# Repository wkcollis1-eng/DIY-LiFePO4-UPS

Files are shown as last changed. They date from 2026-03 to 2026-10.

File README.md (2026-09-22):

<div align="center">

# DIY UPS for Home Assistant Green & Xfinity XB7 Modem

**12V LiFePO4-Based Uninterruptible Power Supply**







</div>

A 12V LiFePO4-based uninterruptible power supply for keeping a Home Assistant Green and Xfinity XB7 cable modem running during grid outages. Built into an IP65 enclosure with Home Assistant monitoring via ESPHome INA260 current sensor.

> **Honest context:** A $85 APC BE600M1 provides comparable backup capability. This build costs roughly the same over 10 years as that option (based on battery replacements and electricity usage). The engineering rationale — longer battery life, faster switchover, direct HA integration, no DC-DC converter voltage regulation — is documented in [design-rationale.md](docs/design-rationale.md). Build this if those tradeoffs matter to you.

---

## ⚠️ Safety Warning

> [!CAUTION]
> **This project involves lithium batteries and AC mains voltage.** Improper handling can cause fire, electric shock, or equipment damage.

- ✅ **Disconnect AC power** before any work inside the enclosure
- ✅ Use appropriate **fusing** on battery connections
- ✅ Never charge LiFePO4 below **0°C (32°F)**
- ✅ Keep a **Class B or ABC fire extinguisher** accessible
- ✅ Review [docs/safety.md](docs/safety.md) before building

**Disclaimer:** Information provided for educational purposes only. Build at your own risk.

---

## Performance Summary

**Validated Runtime:** **~3.6 hours** to hardware LVD (11.8V) under a sustained **14.9W** load.

> **Monitoring upgrade note:** The Shelly Plus Uni has been replaced by an ESPHome XIAO ESP32-C3 + Adafruit INA260 current sensor. All capacity figures below are now coulomb-counted by INA260 rather than inferred from voltage profiles. The May 2026 figures supersede the March 2026 D3 estimates.

### Key Finding

The UPS delivers a reliable **~3.6 hours** of runtime at typical HA Green + XB7 loads. This is **~42%** of the theoretical maximum runtime at full charge (10 Ah / 1.18A = 8.47h).

This result is **not** due to battery degradation, measurement error, or software issues. It is a direct consequence of the **single-rail 13.3V CV architecture**.

### Why the Runtime is Limited

The system uses a single shared rail for both charging and load. To keep the voltage safe for the connected equipment, charging is capped at 13.3V. This holds the battery at approximately **65% SOC**, preventing proper absorption charging at 14.4V. As a result, approximately **3.5 Ah** (~35%) of the battery's rated 10 Ah capacity is never accessible.

| Capacity zone | Ah | Reason |
| :--- | ---: | :--- |
| Float ceiling — never loaded | ~3.5 Ah | 13.3V float ≈ 65% SOC; requires 14.4V charger to recover |
| Rate/LVD penalty | ~1.3 Ah | IR drop at 1.18A strands charge above LVD threshold |
| **Delivered (INA260 measured)** | **4.18 Ah** | Coulomb-counted, May 6 2026 |
| Protected at LVD cutoff | ~0.8 Ah | Intentional; prevents over-discharge |
| Below LVD to rated-empty | ~0.8 Ah | Intentional; cell protection |

### Discharge Characteristics

- Extremely flat voltage plateau from 13.0V down to 12.85V — delivers the bulk of usable energy
- Knee region (12.40–12.85V) shows accelerating decline; ~53 min at production load
- Cliff begins at **~12.40V**: voltage slope accelerates from −30 mV/min to −58 mV/min
- 12.4V warning provides approximately **15–20 minutes** of action time before hardware LVD

### Conclusion

The system performs exactly as designed. The layered protection (voltage warnings → automated shutdown → BP-65 hardware LVD) is robust and all three tiers are now fully live-validated.

**Current validated specification:** ~3.6h runtime at 14.9W average under the existing single-rail topology, based on INA260 coulomb counting (May 6 2026).

A two-stage charging architecture (dedicated 14.4V charger + DC-DC regulator) would be required to approach the full ~7.1–8.5 hour theoretical runtime.

Reports and data can be found in [docs/](docs/).
Last validated: **May 2026 (INA260 coulomb counting)**

---

## Commissioning Results

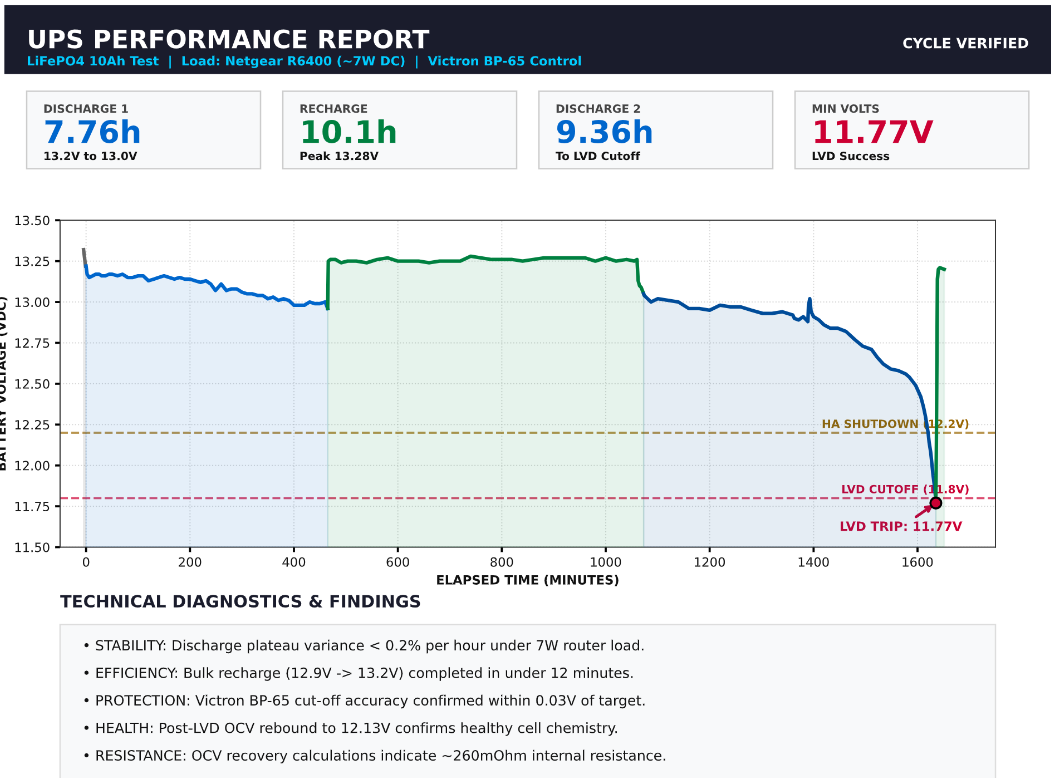
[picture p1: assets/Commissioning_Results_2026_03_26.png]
Commissioning Results


The chart records a full two-cycle discharge test performed March 25–26, 2026 using a
Netgear R6400 router (~7W DC) as a substitute load, with battery voltage logged via the
Shelly Plus Uni at 5-second intervals.

**Discharge 1 (7.76h):** Voltage held the characteristic LiFePO4 flat plateau from 13.2V
to 13.0V over 7.76 hours — a drop of only 0.2V at light load, confirming textbook cell
behavior. **Recharge (10.1h):** AC restored; PSU returned the battery to float within
minutes, peaking at 13.28V and holding stable through a 10-hour recharge window.
**Discharge 2 (9.36h):** A second full discharge ran the battery to LVD cutoff. The
Victron BP-65 tripped at **11.77V** — within 0.03V of the 11.8V design target —
confirming protection circuit accuracy. Post-LVD OCV rebound to 12.13V confirms healthy
cell chemistry with no permanent capacity loss from the deep discharge.

Key findings:
- Discharge plateau variance under 0.2%/hr
- BP-65 cutoff accuracy ±0.03V
- Internal resistance ~260mΩ at low SoC (derived from OCV recovery)
- Bulk recharge from 12.9V to 13.2V completed in under 12 minutes after AC restoration

---

## System Overview

AC grid powers a Mean Well HDR-60-12 PSU set to 13.3V float, which charges a 12V 10Ah LiFePO4 battery through a MOSFET ideal diode. On grid failure, loads switch directly to battery in under 1ms. A Victron BatteryProtect BP-65 disconnects loads at 11.8V to prevent over-discharge. An ESPHome XIAO ESP32-C3 with Adafruit INA260 current sensor and DS18B20 temperature sensor reports battery voltage, current, power, and accumulated Ah/Wh to Home Assistant.

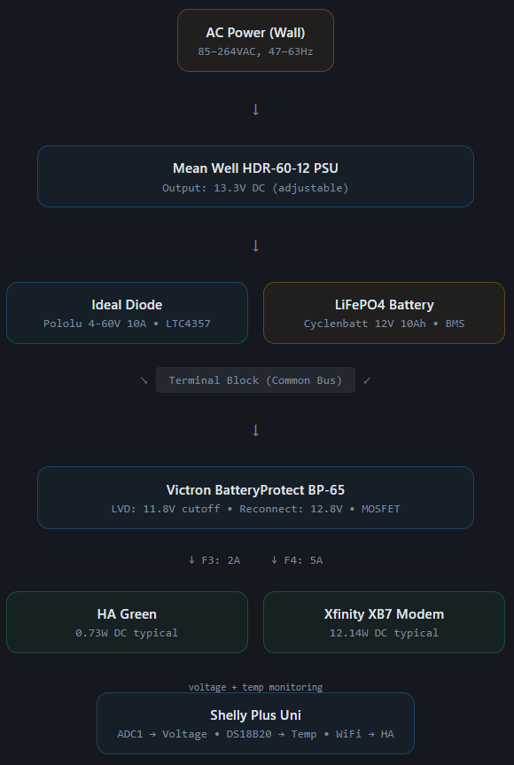
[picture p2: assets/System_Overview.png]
System Architecture


---

## Key Specifications

| Parameter | Value |
| :--- | :--- |
| PSU | Mean Well HDR-60-12, 13.3V float |
| Battery | Cyclenbatt 12V 10Ah LiFePO4 |
| Float voltage | 13.3V (set on PSU trimmer, lacquered) |
| LVD cutoff | 11.8V (Victron BP-65, Setting 7) |
| LVD reconnect | 12.8V (30s delay after threshold met) |
| Device voltage envelope | 11.71–13.11V at terminals (2A worst-case) |
| Switchover time | <1ms (MOSFET ideal diode) |
| Typical load | 16.0W AC wall / 14.9W DC at devices + monitor (INA260 measured) |
| Accessible capacity | 4.18 Ah / 53.3 Wh (INA260 coulomb-counted, May 2026) |
| Runtime at typical load | ~3.6 hours to LVD |
| Battery lifespan | 10–20 years (calendar aging at 13.3V float, 63–75°F) |
| Enclosure | LeMotech IP65 ABS, 9.6″×7.6″×4.5″ |
| Monitoring | ESPHome XIAO ESP32-C3 + INA260 + DS18B20 → Home Assistant |
| Total build cost | ~$224 + ~$25 ESPHome monitor board |

---

## Operating Modes

**Mode 1 — AC Present:** PSU outputs 13.3V through ideal diode; battery held at float equilibrium. Loads draw from PSU, not battery.

**Mode 2 — AC Failure:** PSU output drops to 0V. Ideal diode blocks. Battery feeds loads directly, no interruption.

**Mode 3 — Low Battery (~12.4V):** ESPHome Cliff phase alert. HA notification: Critical Warning.

**Mode 4 — Low Battery (~12.2V):** ESPHome detects threshold. Home Assistant initiates graceful HA Green shutdown; modem continues on battery.

**Mode 5 — LVD Cutoff (11.8V):** Victron BP-65 disconnects loads after 90-second hold-off.

**Mode 6 — AC Restoration:** PSU resumes 13.3V, ideal diode switches source, BP-65 reconnects after 30s hold-off. PSU immediately enters CC mode at 4.5A (~60W) bulk recharge, tapering to CV float over approximately 10–15 minutes.

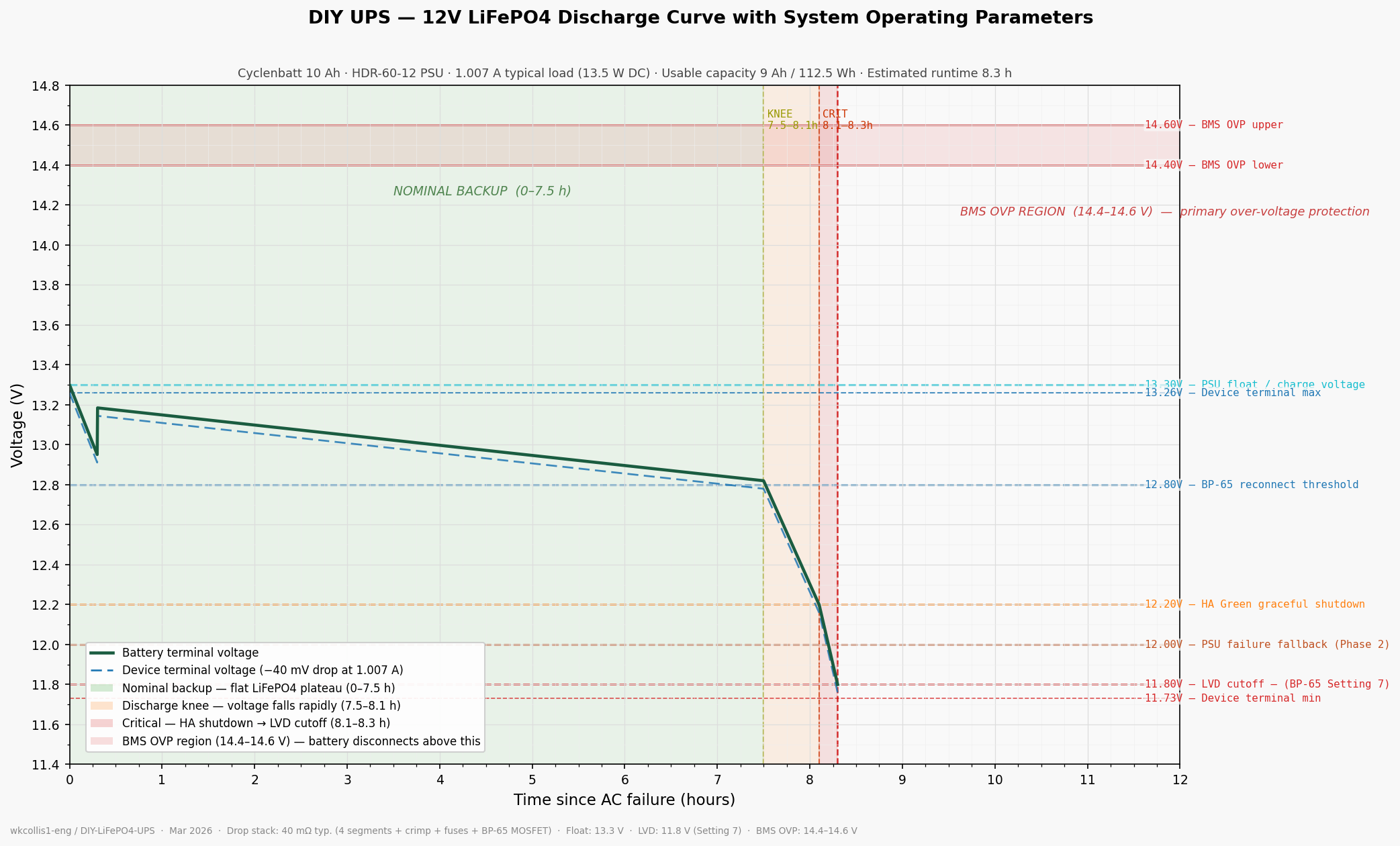
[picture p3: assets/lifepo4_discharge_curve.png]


---

## Automation Validation Status

| Automation | Threshold | Mar 26 | Mar 28 | May 6 | Status |
| :--- | :--- | :--- | :--- | :--- | :--- |
| Early Warning | < 13.0V for 2 min | ✅ | ✅ | ✅ | **PASS** |
| Critical Warning | < 12.4V | ✅ | ✅ | ✅ | **PASS** |
| Graceful Shutdown | < 12.2V for 1 min | ⚠️ Not tested | ⚠️ Not tested | ✅ **Confirmed** | **PASS** |
| BP-65 hardware LVD | ~11.8V | ✅ Direct (11.77V) | ✅ Inferred | ✅ Confirmed (11.675V) | **PASS** |

All four tiers are now fully live-validated. The graceful shutdown automation was confirmed on May 6, 2026 — the final outstanding commissioning item.

---

## Assembly Layout

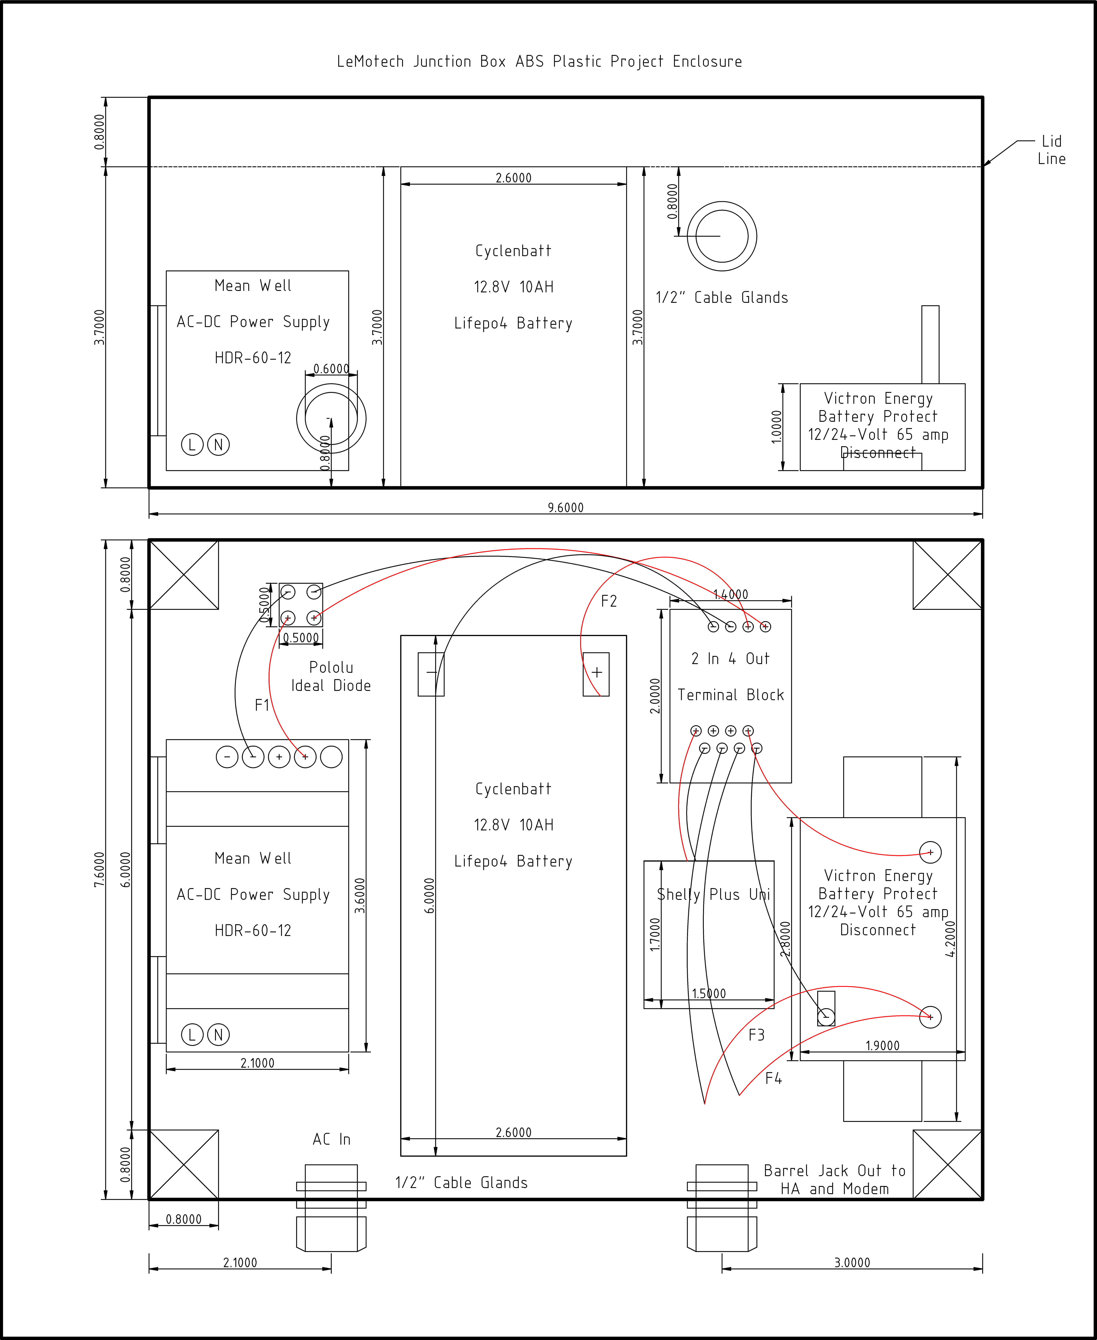
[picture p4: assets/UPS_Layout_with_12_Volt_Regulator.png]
Component Layout


*Elevation (top) and plan (bottom) views of LeMotech junction box. Interior Dimensions in inches.*

## Assembly Pictures

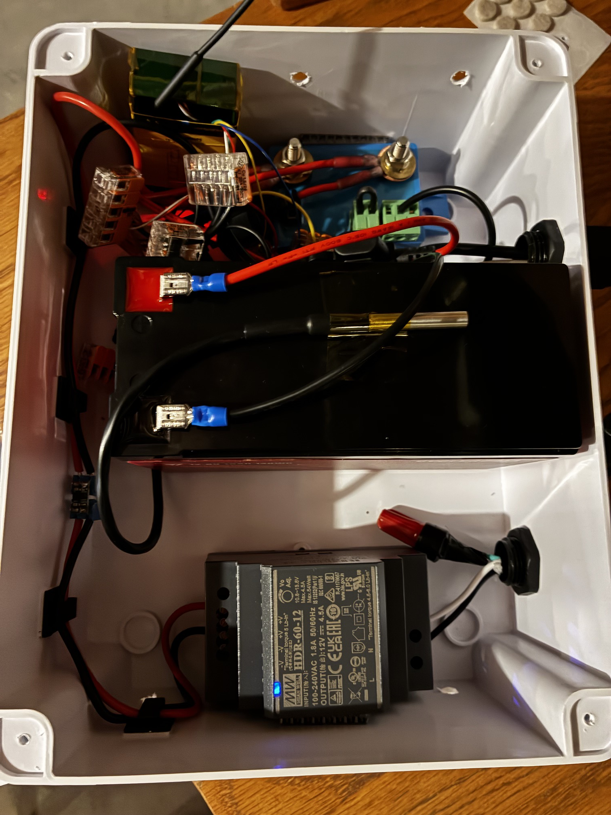
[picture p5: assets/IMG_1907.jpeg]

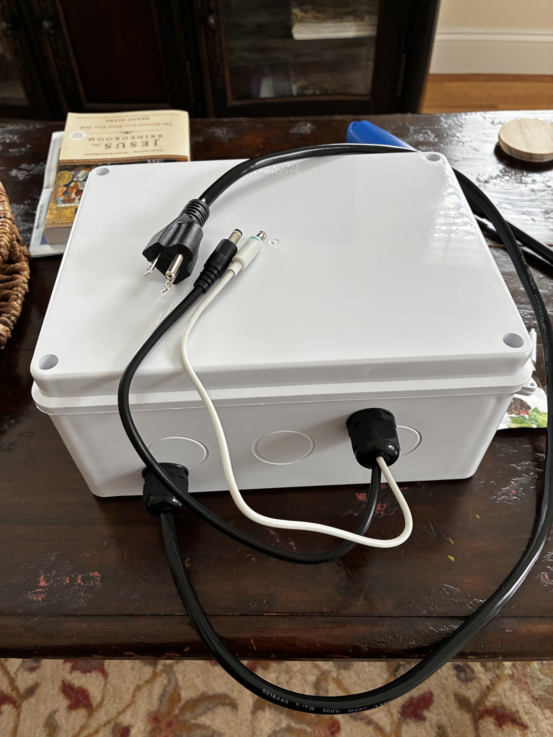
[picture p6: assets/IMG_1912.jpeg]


---

## Documentation

| File | Contents |
| :--- | :--- |
| [docs/bom.md](docs/bom.md) | Full bill of materials with vendor, price, and notes |
| [docs/wiring.md](docs/wiring.md) | From/To wiring tables, fuse locations, component mounting |
| [docs/specifications.md](docs/specifications.md) | Electrical, performance, and protection spec tables |
| [docs/design-rationale.md](docs/design-rationale.md) | Build-vs-buy analysis, float charging strategy |
| [docs/component-selection.md](docs/component-selection.md) | Per-component selection rationale |
| [docs/cost-analysis.md](docs/cost-analysis.md) | Build cost breakdown and 10-year lifecycle comparison |
| [docs/safety.md](docs/safety.md) | AC and battery safety procedures |
| [docs/voltage-drop-analysis.md](docs/voltage-drop-analysis.md) | Wiring resistance and voltage drop calculations |
| [docs/supplemental-analysis.md](docs/supplemental-analysis.md) | Thermal Analysis & Enclosure Heat Budget, Runtime Analysis, Failure Modes & Effects Analysis (FMEA) |
| [docs/design-specification.md](docs/design-specification.md) | Formal requirements, design decisions, and verification matrix |
| [docs/commissioning.md](docs/commissioning.md) | System commissioning process and results |
| [docs/Final_As_Built_Performance_&_Cost_Summary.md](docs/Final_As_Built_Performance_&_Cost_Summary.md) | Final As-Built Performance & Cost Summary |
| [docs/UPS_Validation_Report.md](docs/UPS_Validation_Report.md) | Final Validation Report with Home Assistant configuration |
| [docs/UPS_Report_2026-04-05.md](docs/UPS_Report_2026-04-05.md) | Inaugural commissioning report (Apr 5, 2026) |
| [docs/UPS_Report_2026-05-06.md](docs/UPS_Report_2026-05-06.md) | Outage test report; INA260 first measurement; 12.2V automation confirmed |
| [Top-Off-Charger/top-off-charger-design.md](Top-Off-Charger/top-off-charger-design.md) | Bench top-off / top-balance charger for the removed battery: pre-build design with from/to wiring tables |

## Datasheets

- [Mean Well HDR-60-12 - Datasheet](https://www.meanwell.com/Upload/PDF/HDR-60/HDR-60-SPEC.PDF)
- [Victron Smart BatteryProtect BP-65 — Datasheet](https://www.victronenergy.com/upload/documents/Datasheet-Smart-Battery-Protect-65-A--100-A--220-A-EN.pdf)
- [Victron Smart BatteryProtect — Manual](https://www.victronenergy.com/upload/documents/Smart_BatteryProtect_12V_24V/114439-Smart_BatteryProtect-pdf-en.pdf)
- [Adafruit INA260 — Guide](https://learn.adafruit.com/adafruit-ina260-current-voltage-power-sensor-breakout)
- [TI INA260 — Datasheet](https://www.ti.com/product/INA260)
- [Seeed Studio XIAO ESP32-C3 — Datasheet](https://wiki.seeedstudio.com/XIAO_ESP32C3_Getting_Started/)

---

## Related Projects

- [LiFePO₄ Battery Bank Study](https://github.com/wkcollis1-eng/Lifepo4-Battery-Banks) — 500Ah DIY battery bank with 130+ days of monitoring
- [Home Assistant Config](https://github.com/wkcollis1-eng/home-assistant-config) — HVAC monitoring implementation

---

## Status

- [x] Design complete
- [x] Components specified
- [x] Components ordered / received
- [x] Build complete
- [x] XB7 power measurement complete (14.7W avg, 20.3W peak — 1.066 kWh / 72.4 hr standalone)
- [x] Combined system power measurement complete (16.0W avg, 23.0W peak — confirmed across 5 windows, 525 hours total)
- [x] Home Assistant automation documentation
- [x] ESPHome INA260 monitor build complete and deployed (Apr 2026)
- [x] INA260 coulomb counting validated — first direct capacity measurement: 4.18 Ah / 53.3 Wh (May 2026)
- [x] HA graceful shutdown automation live-validated (May 6, 2026)
- [x] All four automation tiers confirmed — system fully commissioned

---

## Notes

- Device input voltage tolerance (±10%) is inferred from IEC 62368-1 design practice; neither Nabu Casa nor Comcast publish explicit DC input voltage ranges for these products.
- The PSU output trimmer is set to 13.3V and lacquered. Drift analysis shows expected aging drift of 3–5 mV/year — negligible relative to the 500mV headroom before OVP.
- No DC-DC converter is used. The direct battery feed strategy is documented in [design-rationale.md](docs/design-rationale.md).
- The INA260 monitor board (XIAO ESP32-C3 + Adafruit INA260 + DS18B20 on SBB400 breadboard) replaced the Shelly Plus Uni in April 2026, adding coulomb counting, phase detection, and runtime estimation. Monitor draws ~30–40 mA from the 12V battery bus via Pololu D24V7F3 3.3V regulator.
- The Shelly Plus Uni ADC-based capacity estimates (D3, March 2026: 4.85 Ah / 62.5 Wh) are superseded by the INA260 coulomb-counted measurement of 4.18 Ah / 53.3 Wh from May 2026. The D3 figure was computed from voltage profile timing × assumed constant load and should no longer be used as the capacity baseline.

---

## 💝 Support This Project



If this build log or the design rationale saved you time or money on your own UPS project, consider sponsoring continued measurement and documentation work.

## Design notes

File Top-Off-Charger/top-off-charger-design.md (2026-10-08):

# LiFePO4 Top-Off / Top-Balance Charger — Design

**System:** bench top-balance hold charger for the UPS's Cyclenbatt 12V 10Ah. **The pack is removed from the UPS for every session** [owner, 2026-09-21], **charged to full on a Dylannet P20 at 5 A, then held at 14.40 V here** [owner, 2026-09-22; §4.3, §10.1].
**Controller:** the **Top Off Charger PCB** (`Top Off Charger- Oct 2026.kicad_pcb`, §7), one 2-layer board carrying the XIAO ESP32-C3, Adafruit INA228 (#5832), Pololu #2814 switch, Pololu #5382 ideal diode, Pololu D24V7F3 buck and the status LED. It replaces rev 0.5's second build of the bank-monitor board and its Wago-spliced wiring. The bank-monitor build is still cited for the rules that carry over ([wiring summary v1.10][ws], cited below as **ws**).
**Document revision:** 0.8 — **pre-build design draft, 2026-10-08.** The board is laid out (rev 0.7: re-laid smaller, 29.5 × 78 mm, with a Kelvin GND for the INA228; rev 0.8: the power path widened and VIN+ moved to B.Cu), with DRC at 0 errors, 34 warnings (all silk or library) and 0 unconnected. Schematic parity did not run (§7). It is not fabricated, and nothing here is built or tested. Scoped to the UPS pack and moved here from `Lifepo4-Battery-Banks/Top-Off Charger/` (rev 0.2 is commit `680caed` in that repo). Changes are listed in §15.
**Author:** William Collis (draft prepared with Claude Code)

Provenance tags follow the house convention: **[M]** measured, **[S]** spec (document + page), **[D]** derived (formula shown), **[I]** inferred (with its falsifier). The on-hand fuse has no maker's datasheet, so its interrupt rating is **[I]** (O2). Seller listings are cited as **[listing]**: below [S], because R16 needs a maker's document for the identifier on the unit.

[ws]: https://github.com/wkcollis1-eng/Lifepo4-Battery-Banks/blob/main/INA228%20Monitor/battery-bank-monitor-wiring-summary-v1_10.md

---

## 1. The unattended moment

A session is running and the owner is away. Wi-Fi or Home Assistant is down, the ESP32 hangs, the PSU's voltage regulation fails high, or the pack on the lead never went through the P20.

**"Working" at that moment means:**

1. The session ends by itself within its time cap.
2. The pack never sits above its voltage ceiling for longer than one sample period.
3. No fault the battery can feed can burn a conductor.
4. Nothing restarts a charge after a reboot or an AC blip.
5. The PSU never runs in its overload fault mode beyond a short transient (RQ-12).

Every protection layer in §8 exists for one of those five clauses.

---

## 2. Why this exists

The HDR-60-12 floats the pack at 13.3 V, so the cells never reach balancing voltage. On the 09-15 test the pack delivered 2.5331 Ah LVD-to-LVD, against 4.179 Ah on 05-06 [M, one test each; [09-15 README](../data/2026-09-15_full_discharge_survival_test/README.md)]. Its OCV overlay favours a non-uniform pack. Rev 0.4 made this charger the tool for that report's Open Item 16, a coulomb-counted recharge to termination. **Rev 0.5 does not:** the bulk charge moves to the P20 (§4.1 correction record, §4.3), which counts nothing, so Open Item 16 is not served by this build (O10).

**What it cannot do:** balance a pack whose BMS has no balancer. The Cyclenbatt is sealed, with no balance taps [M, owner-confirmed 2026-09-15], and its label gives no balance details [owner, 2026-09-21]. Documentation cannot settle whether it balances. Two observations bear on it:

- **The success measure** is the matched-load LVD-to-LVD capacity test, before and after (UPS Open Item 14a). Nothing else here shows whether the top-off helped.
- **The current tail at 14.40 V** (FW-6) is the first direct look. A passive balancer bleeding a high cell should hold the charge current above zero at constant voltage [I; falsifier: the logged current at 14.40 V decays toward zero with no floor].

The P20's full charge reaches the capacity the 13.3 V float never uses. The hold here adds time at balancing voltage, and nearly all of it is the current tail FW-6 logs, which is the observation above.

**Deferred: the 500 Ah bank hold** (rev 0.2 profile P2). Adding it back needs a second firmware profile, a busbar pigtail fused for the bank's ≥ 3.6 kA prospective fault current [D, rev 0.2 §6.2], the charger's return on the load side of the bank shunt, and the bank report's ledger fix done first. Nothing in this build blocks it, but V_SET must then stay at or below the bank's 14.58 V measured peak.

---

## 3. Requirements

| ID | Requirement | Value | Basis |
|---|---|---|---|
| RQ-1 | Charge current into the pack | **≤ 5.0 A (0.5 C)** | Owner, 2026-09-21, from the Cyclenbatt documentation |
| RQ-2 | The PSU physically cannot exceed RQ-1, under any overload behaviour | ≤ 3.64 A worst case, at any pack voltage FW-3 admits | [D] §4.1 |
| RQ-3 | Charge stops with no network, no HA, and a hung CPU | — | §1 |
| RQ-4 | Nothing restarts after a reboot or an AC loss | — | §1 |
| RQ-5 | Every conductor the battery can feed is fused at the battery end, with an interrupt rating ≥ the battery's prospective fault current | — | §6 |
| RQ-6 | Battery polarity at the F2 tabs is set **by procedure**: colour-matched QDs, checked before each push-on, with AC off | — | §6.3. Rev 0.2 claimed "reversal impossible" through a keyed connector. That held only for a permanent pigtail, and this pack's tabs are remade every session |
| RQ-7 | The pack is never charged on the UPS bus | Removed from the UPS for every session | Owner, 2026-09-21. XB7 validated envelope 11.71–13.11 V [[boost-subsystem-design.md](../UPS-Monitor/boost-subsystem-design.md) R5] |
| RQ-8 | *Withdrawn in rev 0.3* (bank return on the busbar; bank deferred, §2) | — | — |
| RQ-9 | No charging at or below freezing | Charge only above 32 °F. **Met by siting:** the P20 and this charger are used indoors, in conditioned space. No sensor, no firmware check | Owner, 2026-09-21 (Cyclenbatt label) and 2026-09-22 (siting; rev 0.5 dropped the DS18B20) |
| RQ-10 | Charge voltage within the pack's rating | 14.4–14.6 V | Owner, 2026-09-21, Cyclenbatt label |
| RQ-11 | No charging above the pack's upper charge temperature | The label gives none [owner, 2026-09-22]. **Met by siting**, as RQ-9 | Q2 answered |
| RQ-12 | The PSU runs inside its rating: load ≤ 2.0 A, except a transient no longer than t_ol | 2.0 A [S, HDR-30-SPEC p.2, rated current]; t_ol from T11 | Overload is a "fault condition" [S, p.2]; §4.1 correction record. Enforced by FW-4 |

---

## 4. Part selection

### 4.1 PSU — HDR-30-15, not HDR-60-15

The HDR series has no current setpoint. When a pack below V_SET is connected, the battery holds the output near its own voltage, and the PSU runs at its overload limit: **105–160% of rated output power** [S, HDR-30-SPEC and HDR-60-SPEC, both dated 2026-04-03, p.2]. **In rev 0.5 that happens only as a transient** (RQ-12): the P20 does the bulk charge (§4.3), and this PSU holds a full pack.

| | HDR-60-15 | **HDR-30-15** |
|---|---|---|
| Rated | 4 A / 60 W [S, HDR-60-SPEC p.2] | **2 A / 30 W** [S, HDR-30-SPEC p.2] |
| Adj. range | 13.5–18 V [S] | 13.5–18 V [S] |
| OVP | 18.8–22.5 V [S] | 18.8–22.5 V [S] |
| Efficiency (typ.) | 89% [S] | 89% [S] |
| Current in overload, into 13.2 V | **4.77–7.27 A** [D: 63–96 W ÷ 13.2 V] | **2.39–3.64 A** [D: 31.5–48 W ÷ 13.2 V] |
| Meets RQ-1 (≤ 5.0 A)? | **No**: the upper part of the band exceeds it | **Yes, at the band's ceiling** |

The sibling HDR-60-12 on the UPS was measured inside that band. Its total output was 143.8% of nameplate at 11:00:13, decaying to 96.0% by 11:07:58 [D in the 09-15 README; one recharge, with the true peak earlier and unobserved]. So the band is not a paper number. It was also a transient of minutes, which is the only use of the band rev 0.5 keeps (RQ-12).

**Decision: HDR-30-15.** Its datasheet ceiling (3.64 A [D]) is below RQ-1, whatever the overload circuit actually does. The overload row adds "Constant current limiting within 50% ~ 100% rated output voltage" [S, p.2], so the current does not rise as the pack voltage falls, down to 7.5 V [D: 50% × 15 V]. The 13.2 V figure below is therefore not a limit on validity: 3.64 A bounds every pack voltage FW-3 admits (> 10.0 V).

- The pack took ≥ 4.4465 A on the 09-15 outage recharge [M, one firmware peak, a lower bound], so 3.64 A is inside its service history.
- Heat is 3.71 W at rated load [D: 30 W ÷ 0.89 − 30 W].
- 13.2 V is used as a conservative low battery voltage. The current is lower at any higher voltage.

**Output regulation**, the terms that set the voltage-ceiling margin in §9 [S, HDR-30-SPEC p.2, 15 V column]:

| Spec | HDR-30-15 | At V_SET = 14.40 V |
|---|---|---|
| Voltage tolerance (Note 3: includes setup tolerance, line and load regulation) | ±1.0% [S] | ±144 mV [D: 14.40 × 1.0%] |
| Temperature coefficient (0–50 °C) | ±0.03%/°C [S] | ±108 mV over a 25 °C rise [D: 14.40 × 0.03% × 25; the rise is assumed, not measured] |
| Ripple and noise (max, 20 MHz) | 120 mVp-p | +60 mV peak [D: 120 ÷ 2] |
| Overload behaviour | "Hiccup mode when output voltage <50%"; "Constant current limiting within 50% ~ 100% rated output voltage"; both "recover automatically after fault condition is removed" [S] | Hiccup below 7.5 V [D: 50% × 15 V rated]; constant current above it. O3 closed: read by layout-preserving extraction 2026-09-22, the last clause decoded from private-use glyphs |

Terminals: one **+V**, one **−V**, **AC/L**, **AC/N** [S, HDR-30-SPEC p.4]. The pin numbers do not survive text extraction, so work from the labels on the unit's silk. Class II, with no earth terminal [S, p.4].

> **Correction record (R13), 2026-09-22.** Rev 0.3 and 0.4 made this PSU the bulk charger, running "at its overload limit" for the whole bulk phase. The review that preceded rev 0.5 accepted that and recommended dropping the owner's P20, citing the HDR-60-12's recharge as precedent. The datasheet does not support it: the overload row says the PSU "recovers automatically after **fault condition** is removed" [S, HDR-30-SPEC p.2], and the derating curve's load axis ends at 100% [S, p.3]. The HDR-60-12 precedent was a transient of minutes, 143.8% of nameplate decaying to 96.0% within 8 min [D, 09-15 README, n = 1], while a bulk charge from empty would hold this PSU in overload for 0.8–2.0 h [D: 2.53 Ah ÷ 3.2 A to 4.18 Ah ÷ 2.1 A; the pack's measured capacities, one test each, over the 105–160% band of the 2.0 A rating]. Found when the owner asked for proof that the HDR-30-15 could do the whole charge. Rev 0.5 moves the bulk charge to the P20 and adds RQ-12 and the FW-4 overload stop.

### 4.2 Switch — Pololu #2814 (Big MOSFET Slide Switch, MP), not #2815 (HP)

From the comparison table on the Pololu #2814/#2815 product pages [S, read 2026-09-21; footnote 1: "At 12 V with ambient temperature of 22 °C in still air"]:

| | #2814 MP | #2815 HP |
|---|---|---|
| Absolute max / recommended operating voltage | 40 V / 4.5–32 V | 40 V / 4.5–32 V |
| On resistance (max, at 10 V) | 30 mΩ | 8.6 mΩ |
| Continuous current, MOSFETs at 55 °C | 4.0 A | 6.0 A |
| Continuous current, MOSFETs at 150 °C (absolute limit) | 8.0 A | 16 A |
| Price | $5.49 | $8.49 |

**Decision: #2814.**

- At the PSU's 3.64 A worst case [D, §4.1] the #2814 dissipates 0.40 W [D: 3.64² × 0.030 Ω]. That is below the 4.0 A at which Pololu's table puts its MOSFETs at 55 °C in 22 °C still air.
- Its 32 V recommended maximum is above the PSU's 22.5 V OVP ceiling [S, §4.1].
- The ON pin tolerates 30 V independent of VIN, and **"Driving the 'ON' pin low (or leaving it disconnected) will leave the switch off"** [S, #2814 page].
- It saves $3.00 [D: 8.49 − 5.49].

> **Correction record (R13), 2026-09-21.** The review that preceded rev 0.3 read the table's "4.0 A at 55 °C" as an **ambient**-temperature rating and recommended keeping the #2815. The 55 °C is the **MOSFET** temperature, at 22 °C ambient (footnote 1). The owner caught it from the #2814's 8 A spec line, which is the 150 °C absolute-limit figure. Evidence: the #2814 page's comparison table, read 2026-09-21.

### 4.3 Bulk charger — Dylannet P20 (owner's, rev 0.5)

The owner's charger does the bulk charge before every hold session. Everything below comes from the owner's reading of the unit or from the seller's listing; there is no maker's datasheet.

| | Value | Source |
|---|---|---|
| Identity | Dylannet **P20**, maker's part TB-30020A (Huizhou Haitan Technology) | [listing, Amazon B0BM9H759L, read 2026-09-22]. Confirm "P20" on the unit's label (R16) |
| LiFePO4-mode current | 5 / 10 / 20 A selectable; **5 A used** | Owner, 2026-09-22. Meets RQ-1. The listing's own note: "Charge the battery below 10AH with the minimum current" |
| LiFePO4-mode voltage | 14.6 V | [listing]. The top of RQ-10's 14.4–14.6 V |
| End of charge | Enters trickle charging; it **does not turn off** | [listing]. §10.1 disconnects it when it reaches trickle |
| Repair / pulse mode | Lead-acid only; not offered in LiFePO4 mode | Owner, 2026-09-22 |
| Temperature compensation | Automatic winter/summer switching; whether it acts in LiFePO4 mode is not stated | [listing]. Indoor use (RQ-9) |

**Why the P20 and not the HDR-30-15 for bulk:** the P20 is a charger, built to deliver its set current continuously. The HDR-30-15 would deliver bulk current only in its overload fault mode (§4.1 correction record).

**What the P20 does to this design:** the pack arrives having just finished a 14.6 V absorb, so it rests above V_hold, and FW-3 refuses Start until VBUS falls below it (§9). The P20 records nothing, so the approach to the top of charge, where an uneven pack would trip its BMS, happens unlogged. FW-5 still sees a trip during the hold.

---

## 5. Architecture

```text
AC 120 V ─ plug-in COUNTDOWN TIMER (L6, no network) ─ 2-wire cord ─ G1 ─► HDR-30-15 AC/L, AC/N

POWER PATH  (charge current, ≤ 3.64 A)      ── board copper ──────────────────────────────────────────────────────────────────────
HDR +V ─► TB1-2 ═BATT_RAW═► U4 #2814 VIN ~ VOUT ═Batt_SW═► U5 #5382 VIN ~ VOUT ═VIN+═► U2 INA228 VIN+ ═15 mΩ═ VIN− ═VIN−═► TB2-1 ─ G2 ─► S1 ─► 5 A FUSE ─► F2 QD ─► pack +
HDR −V ◄─ TB1-1 ◄══════════════════════════════════ GND pour (both layers) ═══════════════════════════════════════ TB2-2 ─ G2 ──────────────────► F2 QD ─► pack −

BOARD SUPPLY (upstream of the switch)
BATT_RAW ─► F1 1 A slow-blow ═V_Fused═► U3 D24V7F3 ═+3V3═► U1 XIAO 3V3 · U2 INA228 VCC

CONTROL  (on-board traces)
U1 D2 (GPIO4) ═GPIO4_SW═► U4 pin 1 ON   (direct; the #2814's own R4 + R5 = 20 kΩ to GND holds it off)
U1 D1 (GPIO3) ═GPIO3═► R1 1 kΩ ═GPIO3_LED═► LED anode;  LED cathode ─► GND      (status LED, §5.5)
U1 SDA / SCL ═► U2 SDA / SCL

#2814 slide: LOCKED in OFF.  INA228 VBUS jumper: CLOSED.  GPIO4_SW: NO pull-up (the board has no position for one; never add one, §7.2).
```

The order of the power path is deliberate:

- **Switch → ideal diode → shunt.** The switch interrupts forward current. The shunt sees only battery current, not the board's supply.
- **The ideal diode** blocks the battery from back-feeding the PSU (the job it already does in the UPS [[bom.md](../docs/bom.md)]). It does two further jobs here:
  - **It makes L6 end everything.** The board is fed from the PSU side of the switch. Without the diode, AC loss with the switch ON would let the pack back-feed through the switch into the board. The ESP32 would stay up and hold the switch on, and the pack would drain into the PSU output with nothing to stop it. T12 proves this.
  - **It guarantees I ≥ 0 through the shunt.** The VBUS ceiling trip (§9) relies on this.
- **The board is fed upstream of the switch**, from the PSU side (BATT_RAW → F1 → U3). It is alive whenever AC is on, draws nothing from the battery when AC is off, and keeps reading the pack while the switch is open.
- **VBUS is on the battery side.** With the switch open, VIN+ is tied to the battery through the idle shunt, so VBUS reads the pack's open-circuit voltage before every start.
- **The ground is the pour, not a star (rev 0.6).** Rev 0.5 made the [WG] lever nut a ground star, so charge current never flowed in the conductor the INA228 measures VBUS against. On the board, pack − (TB2-2) and HDR −V (TB1-1, rev 0.7) both land on the GND pour. The INA228's GND (U2 pin 2) is not on the pour (the owner's 2026-10-06 17:09 save): it is its own net, GND_SENSE, a 0.5 mm track to a net tie on TB2-2's pad. This is a Kelvin connection (§7.3). The charge return therefore no longer crosses copper shared with the INA228's reference, and **VBUS reads high by ≤ 0.20 mV at 3.64 A** [D, §7.3]. Before the Kelvin connection it read high by 0.376–0.382 mΩ × I, 1.37–1.39 mV at 3.64 A. High is the safe direction for the 14.60 V ceiling (§9). It is zero before every start (I = 0, FW-3), and T10 measures it as part of R_series.

### 5.1 Terminal blocks (rev 0.6: replaces the splice nodes)

The rev 0.5 lever nuts WP, WG and WL are gone: their joints are board copper now. Only four wires land on the board, on two 2-position 3.81 mm screw terminals: **Phoenix Contact BC-381X9-2 GN, item 5442756** (owner, 2026-10-06; it is the board's Value field) [S, Phoenix product page for 5442756, owner-supplied text, 2026-10-06]. Its body (7.62 × 7.3 mm, 1.1 mm hole) matches the footprint, `TerminalBlock_Phoenix_MKDS-1-2-3.81_1x02_P3.81mm_Horizontal` (7.61 × 7.3 mm, 1.1 mm drill) [M, board file]. Directions below assume the board is held **component side up, with the INA228 end at the top** (the TB2 end; KiCad's y = 20 mm edge in rev 0.7).

| Block | Pin | Pad | Silk | Net | Wire landed | Which screw |
|---|---|---|---|---|---|---|
| **TB1** (PSU in) | 1 | round | `GND` | GND | W6 from HDR **−V** | the **upper** screw, nearer the XIAO |
| | 2 | square | `+` | BATT_RAW | W3 from HDR **+V** | the **lower** screw, nearer F1 |
| **TB2** (pack lead) | 1 | square | `+` | VIN− (the shunt's low side) | W16, lead **+** | the **right** screw, nearer the board centre |
| | 2 | round | `GND` | GND | W18, lead **−** | the **left** screw, nearer the left edge |

[M, board file saved 2026-10-06 15:16:19 (rev 0.7 layout), pad nets, shapes and positions. **Rev 0.7 swapped TB1's pins** (owner, 2026-10-06: intentional): BATT_RAW moved from pin 1 to pin 2 and GND from pin 2 to pin 1, so `+` is now the **lower** screw. The square pad stayed with `+`. TB2 is unchanged.]

- **TB1's wires enter from the board's left edge**; **TB2's from the top edge**, so the lead leaves the box that way without a hard turn (owner, rev 0.6 layout; both blocks keep their rev 0.6 rotations in rev 0.7 [M]).
- **Rev 0.8: TB1's labels can be read with U4 seated** (O14). TB1 moved 4.5 mm down, its pads now at y 68.5 and 72.31 [D: rev 0.7's + 4.5]. `GND` is at (16.5, 66.0), above the upper screw, and `+` at (17.0, 74.5), below the lower one, both left of U4's outline at x 20.7 [M, board file 2026-10-08 10:48:22]. The screw order is unchanged: **lower screw `+`**.
- **Rev 0.7: TB1's `+` and `GND` silk sat under the #2814.** `GND` is at (22.5, 66.0) mm and `+` at (21.5, 67.5), both inside U4's outline (x ≥ 20.7 mm), so a seated #2814 hides them [M, board file 2026-10-06]. `GND` also sits midway between the two screws (pads at y 64.0 and 67.81). Read them before U4 goes in, or go by the table: **lower screw `+`** (O14).
- **TB2-1's screw is under the INA228.** TB2's `+` silk (20.0, 29.5) and pin 1 (x 20.6) are inside U2's outline (x ≥ 18.5 mm) [M], and the module sits ~10 mm up (owner) over an 8.5 mm block [S]. **Land and torque W16 and W18 before seating U2**, and unseat U2 (AC off) to re-land them. `GND` (15.5, 30.0) is clear. Rev 0.8 leaves TB2 and its `+` where they were, and moves `GND` to (15.5, 29.5), still clear [M].
- **Landing the wires** [S, Phoenix 5442756 page]: 26–16 AWG (to 1.5 mm²), so 16 AWG at TB2 and 18 AWG at TB1 are in range. Strip 5 mm. Torque 0.22–0.25 Nm, holding the housing while tightening. Ferrules are listed only up to 0.5 mm², so land 16 and 18 AWG bare. Do not tin the strands [I: solder creeps under clamp pressure and the joint loosens; general practice, not on the Phoenix page]. Rated 13.5 A (UL 10 A), above the 3.64 A transient (§6.4).
- **Nothing on the board blocks a reversed TB1.** BATT_RAW has no diode or protection part [M, netlist §7]. The #2814 has its own reverse-voltage protection [S, product name, §14], but F1's branch feeds C4 and U3 directly. Check polarity before first power (§5.4).

### 5.2 From/to — inside the enclosure

| W# | From | To | Wire | Termination / notes |
|---|---|---|---|---|
| W1 | AC cord, **hot** conductor (smooth jacket; narrow blade on a polarized plug) | HDR-30-15 **AC/L** | 2-conductor cord, through cord grip **G1** | HDR screw terminal. The cord's plug goes into the countdown timer |
| W2 | AC cord, **neutral** conductor (ribbed jacket; wide blade) | HDR-30-15 **AC/N** | same cord | HDR screw terminal |
| W3 | HDR-30-15 **+V** | board **TB1-2 (BATT_RAW, `+`)** | 18 AWG red | HDR screw terminal → TB1 **lower** screw (§5.1; rev 0.7 moved it). Feeds the power path and, through F1 (1 A SB), the board supply. PSU-fed only: the ideal diode keeps the pack off it (§5) |
| W4, W5 | *Withdrawn in rev 0.6* | — | — | Board copper: the BATT_RAW track to U4 VIN and to F1 (§7) |
| W6 | HDR-30-15 **−V** | board **TB1-1 (GND)** | 18 AWG black | HDR screw terminal → TB1 **upper** screw. The charge return lands here from the pour (§5, §7.3) |
| W7–W14 | *Withdrawn in rev 0.6* | — | — | Board copper. W7–W9 (grounds) → the GND pour; W10 → the Batt_SW track; W11 → the VIN+ track; W12 → the VIN− track; W13/W14 (the J2 control pair) → the GPIO4_SW track, U1 D2 to U4 ON, and the pour. The #2814 and #5382 grounds are their own module pins on the pour (§7) |
| W15 | *Withdrawn in rev 0.3* | — | — | No external pull-down: the #2814 carries its own (§7.2) |

### 5.3 From/to — leaving the enclosure

| W# | From | To | Wire | Termination / notes |
|---|---|---|---|---|
| W16 | board **TB2-1 (VIN−, `+`)** | Splice **S1** → fuse holder, line-side lead | 16 AWG red, through cord grip **G2** | **Lead +.** S1 is a crimped, heat-shrunk butt splice, not a lever nut: this joint is outside the box, on a lead that is handled every session. **24–30 in** (owner, 2026-10-06; §6.4). R_series is measured at T10 |
| W17 | Fuse holder, battery-side lead (**5 A**) | **F2 female QD** → Cyclenbatt **+** | the holder's own lead | **The fuse sits within a few inches of the + tab** (§6.1). Insulated 6.3 mm female QD |
| W18 | board **TB2-2 (GND)** | **F2 female QD** → Cyclenbatt **−** | 16 AWG black, through **G2**, twisted with W16 | **Lead −**, the charge return. Insulated 6.3 mm female QD |
| W19 | *Withdrawn in rev 0.5* | — | — | DS18B20 dropped: RQ-9 and RQ-11 are met by siting (§3). Enclosure temperature comes from the INA228 die (FW-10) |

Not on the rev 0.6 board: an OLED header (dropped in rev 0.3), a DS18B20 terminal (dropped in rev 0.5), an ALERT test point (L4 withdrawn), or a separate VBUS lead (the jumper replaces it). INA228 header pins 5 (VBUS) and 8 have no net [M, board file].

### 5.4 Build notes

- **First flash by USB with AC off** (cord unplugged from the timer), OTA after that, and never USB with AC on. The board puts U3's 3.3 V output straight onto the XIAO's 3V3 pin (§7), so the bank build's rule against a 3V3 source conflict with the XIAO's USB-fed LDO carries over [[ws] §2.1].
- **Power-up tell:** the status LED is firmware-driven, not a rail indicator. GPIO3 resets as an input with no pull and is not in the power-up glitch table [S, ESP32-C3 datasheet pp.20–21], so the LED is dark from reset until the firmware drives it. If it is **dark for more than ~10 s** after AC on, the board is not running [[ws] §4.4]. Check TB1 polarity first, **then the LED's own polarity** (§5.5): a reversed LED is dark forever and fakes this symptom.
- **Staged first power (rev 0.6).** The modules plug into sockets, and every socket accepts a module turned 180° or shifted along the row. Bring the board up one module at a time, AC off for every insertion:
  1. **Bare board** (U1–U4 out; U5 is soldered): DMM TB1-1 to TB1-2 must **not** read a steady short. C4 and C5 charge from the meter, so the reading climbs.
  2. **U4 (#2814) in:** repeat step 1. Turned 180°, the module's GND pin 2 lands on board pad 11 (BATT_RAW) while its pins 9–10 land on GND pads, so TB1 reads a dead short [D, from the pad map, §7]. On AC, that short would hold the PSU in hiccup.
  3. **U3 (D24V7F3) in, U1 and U2 out:** AC on, read **3.3 V** at the U1 socket's 3V3 pin and at U2 socket pin 1. Turned 180°, U3 puts V_Fused on its own output pin. What that does to the +3V3 net depends on the module's internals, which the board review could not settle: whether C4's body blocks the reversed insertion is inconclusive [I; falsifier: the step-3 reading]. That is why U1 and U2 stay out until this reads 3.3 V.
  4. **U2, then U1**, each with AC off.
- **Control net, XIAO out, U4 in, before the first AC on:** the U1 socket's D2 contact to U4 pin 1 (ON) reads 0 Ω, and D2 to GND reads roughly 10–20 kΩ through the #2814's R4 + R5, with Q3's base junction across R5 depending on the meter. A 0 Ω to GND, or an open to ON, means U4 is mis-seated. On the board, copper replaces the J2 cable, so the pair can no longer be swapped; this check now proves the seating. It still does one of the jobs of the withdrawn Rs (§7.2).
- **Before the first AC on:** DMM continuity from each F2 QD back to its terminal (+ through the fuse to TB2-1, − to TB2-2), with no continuity between them.

### 5.5 Status LED: where it goes, and which leg goes in which hole

**Where (rev 0.8).** With the board component side up and the INA228 end at the top, the LED is on the **left edge**, below the XIAO and above TB1, just left of the #2814's outline. Its two holes are 2.54 mm apart, at (15.96, 61.50) and (18.50, 61.50) mm, against the left edge at x 13.45 [M, board file saved 2026-10-08 10:48:22]. It is still turned as in rev 0.7, so the square pad is the **right** hole. But the LED now sits at the other edge, so the square hole is the one **farther from** the edge; in rev 0.7 it was the nearer. The LED is under no module, and no part's outline stands in front of the XIAO's USB-C socket (O12) [M, courtyards and outlines]. R1 (1 kΩ) lies horizontally under the XIAO.

**Where (rev 0.7, superseded).** The LED was on the **right edge**, level with the XIAO's USB-C socket, which opened straight at it: the socket's axis at y 46.0 mm, the LED's centre at y 47.0, its holes at (37.16, 47.00) and (39.70, 47.00) mm [M, board file saved 2026-10-06 15:16:19]. Rev 0.7 **turned it 180°** from rev 0.6.

```text
            INA228 end of the board is UP, component side facing you

                      silk ring: cut FLAT on this side (on the
                      3 mm footprint the flat shows only as two
   left edge          short ticks, above and below the square pad)
   of the board                    │
       │                           ▼              #2814 (U4)
       │       (●)          [■]   ▌               outline ──►
       │      pad 2        pad 1  ▌
       │      ROUND        SQUARE ▌
       │        │             │
       │     LONG leg      SHORT leg
       │     anode (+)     cathode (−)
       │     to R1, XIAO   to GND
       │     D1 (GPIO3)
```

| LED lead | How to recognise it | Goes in | Pad | Net |
|---|---|---|---|---|
| **Cathode (−)** | the **short** leg; the **flat** on the LED's rim is on this side | the **right** hole, toward the #2814 and away from the board edge, on the flat side of the silk ring | **square** (pad 1) | GND |
| **Anode (+)** | the **long** leg | the **left** hole, nearer the board edge | **round** (pad 2) | GPIO3_LED → R1 → GPIO3 |

**Mnemonic: Square = Short = Flat = minus.** The square pad, the short leg and the flat on the rim all mark the same lead, the cathode. The long leg goes in the round hole.

- **What is measured, and what is convention.** The pad shapes, their nets and the flat in the silk are [M], read from the board file: pad 1 is square and on GND, and pad 2 is round and on R1. "Long leg = anode, flat = cathode" is the industry convention. For this part it is **[I]**: Lite-On's LTL-4231N datasheet could not be retrieved (§14).
- **The check that settles it, before soldering and before trimming the legs** (trimmed legs lose the length cue). Put the DMM on diode test, red probe on the long leg and black on the short. The LED should glow faintly and read about 2 V [I: the listing's 2.1 V forward voltage]. If it reads open, swap the probes. If it glows that way round, this part breaks the convention: trust the meter, and put the lead on the **black** probe in the square hole.
- **A reversed LED** sits reverse-biased at 3.3 V and never lights. Whether that is inside its reverse rating is [I] without the datasheet. The real cost is the indicator: a dark LED reads as "board not running" (§5.4), and FW-11's status patterns are lost. The first boot checks it: once HA or the web page shows the node running, the LED must show the IDLE blink.
- **Current:** about 1.2 mA [D: (3.3 V − 2.1 V) ÷ 1 kΩ; Vf from the listing]. Whether that is bright enough in room light is [I]. The falsifier is the first boot. If it is too dim, R1 is the only part to change.
- **Size: 3 mm.** The Value field names the LTL-4231N, which LCSC lists as a 3 mm (T-1) part [listing, C125082]. The owner changed the footprint from `LED_D5.0mm` to `LED_D3.0mm` in v6 (2026-10-03 22:41:30), and that closed Q6. The pads did not move in that edit: same positions, same nets, 1.8 mm pads, 0.9 mm drill [M, v5/v6 diff]. Rev 0.7 then moved and turned the LED (above); pad 1 is now 1.6 × 1.8 mm, pad 2 1.8 mm round, both 0.9 mm drill, same nets [M, board file 2026-10-06]. The Value text still reads "LED GREEN DIFFUSED T/H LED_D5.0mm - LTL-4231N". It is on F.Fab, which is not fabricated, so nothing printed is wrong (O13).
- **USB-C plug clearance: settled in rev 0.8** by the move to the left edge. The LED is now at the XIAO's other end and below it, so a cable's overmold cannot reach it (O12 closed). Rev 0.7's analysis follows. The XIAO sits about 10 mm up on its sockets (owner, 2026-10-06; rev 0.6 said ~8 mm), and in rev 0.7 its USB-C socket points straight at the LED. The LED is 1.0 mm off the socket's axis (it was 7.0 mm in rev 0.6), and its dome starts about 0.5 mm past the XIAO's outline [D: dome centre x 38.43 − 1.5 mm vs outline x 36.4, board file], so a cable's overmold passes **directly over** it. The board's 3D render puts the LED top at about 5.1–5.3 mm and the socket's underside at about 9.7 mm [M, render of the board file's models]. An overmold up to 8 mm thick, centred on the socket, would clear the LED by roughly 2 mm [I: overmold size and a 3.2 mm socket height assumed, not measured]. Whether it clears is not settled (O12). **Dry-fit before soldering:** seat the XIAO, plug a USB-C cable in, and stand the LED in its holes. If they touch, mount the LED flush, or do the one USB flash (§5.4) with the XIAO out of its socket. Every later flash is OTA.

---

## 6. Fusing and the battery connection

### 6.1 Where the fuse goes

The energy that burns wire comes from the **battery**. The PSU limits itself to ≤ 160% of rated power [S] and hiccups below 50% Vout [S, HDR-30-SPEC p.2; O3].

A short in the external lead (a QD touching the wrong tab, chafed insulation) is fed from the battery and never passes a fuse at the charger end. **So the fuse goes at the battery end of the + conductor, as close to the + tab as the holder allows.** Everything downstream of it is then protected: the lead, the splices, and every node inside the enclosure the battery can reach. A second fuse at the charger end would add nothing for battery-fed faults.

The negative conductor is not fused (standard practice: fuse the ungrounded conductor). The UPS's own F2 fuse stays with the UPS harness when the pack comes out, so the charger lead carries its own.

### 6.2 Rating and interrupt capacity

| | |
|---|---|
| Normal current | ≤ 3.64 A [D, §4.1] |
| Fuse | **5 A mini (ATM/APM) blade in an inline holder** (owner, on hand; from an AKOSN assortment kit, Q3 answered 2026-09-22) |
| Prospective fault current | Bounded by the pack and a 10 A BMS, below 1 kA [I; falsifier: none cheap] |
| Interrupt rating | **Unknown.** The kit's listing states no voltage rating, no interrupt rating and no standard [listing, Amazon B0DNC57LR9, read 2026-09-22], and the kit has no maker's datasheet. **RQ-5 cannot be shown met with it:** fit a branded 5 A mini fuse whose maker publishes a DC interrupt rating (O2). Rev 0.2's ATC-5 figure (1,000 A at 32 VDC) came from a distributor listing |

The fuse protects the **wire**. It does not enforce RQ-1: a 5 A fuse carries 5 A indefinitely. RQ-1 is enforced by the PSU choice (§4.1) and the firmware I_max stop (§9).

### 6.3 No alligator clips, and no keyed connector

**Clips are out.** A slipping clip can bridge terminals upstream of the fuse, and clips allow a reversed connection.

**The keyed connector is out too (rev 0.3).** The pack comes out of the UPS for every session, so its F2 tabs are reconnected every time, to the UPS harness and to this lead alike. A keyed connector on the charger would only move the joint where reversal can happen. It would never remove it.

The lead therefore ends in the fuse holder and insulated F2 female QDs (§5.3), and **RQ-6 is met by procedure** (§10.1), as it already is for the UPS's own battery connection.

What reversal would do: with the switch open, a reversed pack puts about −13 V on VBUS and the #5382 output [I]. Treat the INA228 and #5382 as damaged until proven otherwise. FW-3 refuses to start on a reversed or absent pack, because VBUS then reads ≤ 10.0 V. But the damage happens when the QD goes on, before any firmware runs.

### 6.4 Conductors

- **External lead:** 16 AWG, 4.016 mΩ/ft [S, standard AWG table, 20 °C].
- **PSU to board** (W3, W6): 18 AWG, short runs.
- **On the board (rev 0.7):** the power path is 1.5 mm track on F.Cu: BATT_RAW, Batt_SW, VIN+ and VIN−, each a single route [M, board file 2026-10-06]. IPC-2221's external-conductor formula gives 3.21 A at a 10 °C rise and 4.35 A at 20 °C for 1.5 mm of 1 oz copper [D: I = 0.048 · ΔT^0.44 · A^0.725, with A = 81.4 mil²; 1 oz is assumed, not measured]. 2.0 A is the steady case (RQ-12); 3.64 A is a transient no longer than t_ol. The ground is the pour (§7.3). The owner plans to move VIN+ to B.Cu and shorten it (O15, §7.4).
- **On the board (rev 0.8, the 2026-10-08 10:48 save):** each power net is still a single route, now wide [M, board file]:
  - BATT_RAW: 4.0 mm on F.Cu, from TB1-2 through U4 pins 12 and 11.
  - Batt_SW: 2.9–4.0 mm on F.Cu.
  - VIN+: 2.9–4.0 mm on **B.Cu**, with no vias (O15, done).
  - VIN−: 3.85 mm on F.Cu, necking to 1.7 mm for its last ~0.2 mm into U2 pin 6.

  The same IPC-2221 formula gives these rises at 3.64 A: 4.0 mm 2.6 °C, 2.9 mm 4.5 °C and 1.7 mm 10.8 °C. At 2.0 A they are 0.7, 1.2 and 2.8 °C [D]. The formula assumes a long run, so it overstates the short 1.7 mm neck [I].
- **The F1 branch** (BATT_RAW, from U4 pins 11–12 to F1 pin 1) is 2.0 mm, and V_Fused is 1.5 mm. The branch lies upstream of F1, so F1 does not protect it. The PSU's limit does (≤ 3.64 A [D, §4.1]), and the #5382 keeps the pack off BATT_RAW. At 3.64 A, 2.0 mm rises 8.3 °C [D, as above]. The branch's two legs, to U4 pins 11 and 12, form a small loop in parallel with the main run. That loop barely matters: narrowing the branch from 2.95–3.95 mm to 1.5 mm, on a copy of the 08:04 save, moved BATT_RAW's track resistance from 1.172 to 1.177 mΩ [D, §7.4's 2-D solve].
- **Module contacts.** U2's VIN+ and VIN− are one socket contact each, so the whole charge current crosses two Sullins contacts rated 3 A [S, Sullins 0.100″ female header datasheet pp.114–115]. That covers 2.0 A steady. **3.64 A exceeds it**, and is tolerated only as the t_ol transient [I; falsifier: the contact runs warm to the touch after T11's opening minutes]. The #2814 has two contacts on VIN and two on VOUT (§7). U5 is soldered on pin headers. The #5382 is rated 10 A continuous and < 10 mΩ [S, Pololu #5382 product page, read 2026-10-08; the part number is the board's Value field, not read off a unit (R16)].
- **The #2814's contact pairs share the current** (rev 0.8). A network solve of the board copper, with each socket pad tied in through a contact resistance Rc, gives these splits at Rc = 1 mΩ and 5 mΩ [D]:
  - VIN, pin 11 / pin 12: 47.0 / 53.0 and 49.4 / 50.6.
  - VOUT, pin 5 / pin 6: 51.0 / 49.0 and 50.2 / 49.8.

  The busier contact therefore carries ≤ 1.93 A at 3.64 A, under the 3 A rating [D]. With ideal contacts (Rc → 0), the copper alone would put 89 % through pin 12. No real contact is that good [I: falsifier, a Sullins contact resistance below 1 mΩ on pp.114–115]. Rc itself has not been looked up.
- **Voltage drop** between VBUS and the pack terminals is I × R_series, where R_series = shunt (15 mΩ [S, Adafruit #5832]) + U2's VIN− contact + the VIN− track (≈ 5.7 mΩ in rev 0.7 [D: 17.3 mm ÷ 1.5 mm = 11.5 squares × 0.4926 mΩ/sq, at 35 µm and 20 °C; a network solve of the three segments gives 5.67]; rev 0.6's 24.4 mm gave 8.0; rev 0.8 gives 2.36 mΩ [D: 2-D solve, §7.4]) + TB2 + fuse + both lead conductors + splice + QDs + the pour's shared path (≤ ~0.055 mΩ since the 17:09 Kelvin GND, TB2-2's own pad included; it was 0.376–0.382 mΩ [D, §7.3]). VIN+ is upstream of the VBUS sense point, so its track is not in R_series. Measure it once at commissioning (T10). **The firmware does not use it (rev 0.5):** it publishes raw VBUS and I, and V_batt = VBUS − I·R_series is computed in InfluxDB/Grafana, where a revised R_series re-computes history. T10's value also splits FW-12's per-session edge resistance into series and pack parts.
- **Worked example**, lead alone, at the owner's 24–30 in (2026-10-06; W16): 4.0–5.0 ft of 16 AWG conductor, out and back, is 16.1–20.1 mΩ [D: × 4.016 mΩ/ft]. It drops 32–40 mV at 2.0 A and 58–73 mV at 3.64 A [D]. Until this revision the example assumed 5 ft each way: 40 mΩ and 146 mV. At 24–30 in the lead is **less** than the board's 38.10 mΩ of charge-path track (§7.4). In rev 0.8 that track is 12.17 mΩ (§7.4), so the lead is now the larger term. The drop falls toward zero as the current tapers.

---

## 7. The board — Top Off Charger PCB (rev 0.8)

The controller is a purpose-built board, `Top Off Charger- Oct 2026.kicad_pcb` (KiCad 10): two layers, 29.5 × 78 mm in rev 0.7 (rev 0.6 was 31.5 × 95) [M, F.Cu/B.Cu stackup, Edge.Cuts]. It is drawn for OSH Park and replaces rev 0.5's reuse of a bank-monitor V2 board. Everything in this section is read from the board file using kicad-cli 10.0.6 and KiCad's pcbnew Python [M]. Unless a line says rev 0.6, it was read from the rev 0.7 file saved 2026-10-06 15:16:19 (309,671 B), or from the owner's 17:09:17 save (309,654 B), which adds the Kelvin GND (§7.3). The 17:09 save was the file in `pcb/` until rev 0.8 (below). Rev 0.6 was read from v6 (saved 2026-10-03 22:41:30, 318,750 B) and gated on v7 (22:42:18, 318,320 B). Rev 0.7 re-laid the same netlist on a smaller outline. Its net changes are TB1's pin order (§5.1) and, in the 17:09 save, the GND_SENSE net (§7.3). The design rules are unchanged: the `.kicad_pro` differs only in the default pad width for new pads and the last plot path [M, diff]. The 17:09 save's (17:08:40) differs from 15:16's only in the default size and drill of new pads [M, diff].

- **Not yet fabricated.** The board file and its project file (design rules) are the only artifacts. Both are in [`pcb/`](pcb/) (O11). When the Gerbers are exported for the order, they become the authority for what was built, as the V2 Gerbers were for rev 0.5.
- **No schematic.** The board was drawn directly, so the netlist below is the design. KiCad's schematic-parity check therefore cannot run.

**Rev 0.8 (2026-10-08).** The file in `pcb/` is now the owner's 2026-10-08 11:00:58 save (318,992 B, sha256 `e5586ceb07233e71a7556a01576da8c81db629cf90da1182eaa210763013efaf`). Every check in this revision was run on the 10:48:22 save before it (318,536 B, sha256 `9661db54913ce70fbb37433480a5eb0c0172a43b08102493edb6cd6dbcda5b28`). The two differ only in U1's 3D models: the XIAO's model is raised from 8.5 to 11.0 mm, and two pin-header models are added. The copper, pads, vias, zones and text are identical, and DRC gives the same 34 warnings [M: text diff, board dump, DRC set]. Each sha256 in this document is of a board file as KiCad wrote it, with CRLF line endings, which a Windows checkout with `core.autocrlf` reproduces. Git stores the boards with LF, so a plain checkout or a download from GitHub hashes differently: rev 0.8's board is then `aaa9e15839149177f0d6b3867c41cc5a0832db0a3e18ae6439577525eda6e6d4` and the 17:09 save's `f141be03aa21f8603825f59d2e9ac5b4dba23db41a2cc76aac1e34f071ec0bf6` [M]. The `.kicad_pro` files are LF already, so their hashes hold either way. The `.kicad_pro`, the same file for both saves, (9,806 B, sha256 `abb4d3f13d19d1a4fbb53a2cd935b50558ca129046a85dc00457706d6852c5eb`) differs from 17:09's only in the default size and drill of new pads [M, diff]. Rev 0.8 keeps rev 0.7's outline, netlist and parts, and changes the copper. The owner made the changes over a series of saves from 2026-10-06 to 10-08. Some of them began as edits a review session wrote into the owner's file on 2026-10-06 (R13, §7.4). The list below is read from the 10:48 file [M]:

- **VIN+ is on B.Cu** (O15): 2.9–4.0 mm wide and 47.3 mm long, from U5 pad 3 to U2 pin 7, with no vias. Both ends are through-hole pads, so the bottom layer reaches them directly.
- **BATT_RAW, Batt_SW and VIN− are 2.9–4.0 mm**, with VIN− necking to 1.7 mm into U2 pin 6. The F1 branch is 2.0 mm (§6.4).
- **Pads enlarged**, for current and for hand soldering:
  - TB1-2, TB2-1 and TB2-2: 3.0 mm. TB1-1: 2.0 mm.
  - U4: pins 11 and 12 3.2 mm (pin 11 3.2 × 2.25), pins 5 and 6 2.1 mm.
  - U5: pins 1 and 3 3.1 mm.
  - U2: pin 7 a 3.0 × 2.1 oval, pin 6 a 2.0 × 1.6 oval.
  - F1: 2.5 mm.
- **TB1-1 and TB2-2 meet the pour through thermal reliefs**, for hand soldering. At 17:09, TB2-2 was solid [M, pad zone_connect] (§7.3).
- **Signals:** GPIO4_SW runs 16.9 mm on B.Cu and 8.7 mm on F.Cu, joined by one via, and still reaches only U1 D2 and U4 pin 1 [M]. SDA and SCL were re-routed on B.Cu.
- **Stitching vias:** 78 → 85, so 86 vias in all, counting GPIO4_SW's.
- **Placement**, against 17:09 [M]. The outline is unchanged. Parts moved:
  - **The LED went from the right edge to the left** (§5.5). Its square hole is now the one away from the edge.
  - TB1 moved 4.5 mm down, which clears its labels from under U4 (§5.1, O14).
  - U4 moved 0.9 mm down, and U5 0.6 mm; U5 is still under U4.
  - R1 moved and turned 180°, and now lies wholly under the XIAO.
  - C2 moved 1.0 mm left and 3.5 mm up. U1 and C3 moved 0.5 mm up.
  - H3 and H4 moved by about 0.5 mm.
  - F1 moved 0.35 mm down, and U3, C1, C4 and C5 0.5 mm.
- **F1 and U3 moved down** in the last save, by 0.15 and 0.2 mm (owner: for clearance). C1, C4 and C5 moved with U3. F1's courtyard now clears U3's by 0.63 mm and C4's by 0.54 mm; they were 0.58 and 0.49 [M, courtyard boxes].
- **The net tie is named NT1** (O16a).

**Gate verdicts, rev 0.8 (the 10:48 save, 2026-10-08):**

- DRC (`--severity-all`, with the board's `.kicad_pro` rules) gives the same result on the saved fill and after a refill: **0 errors, 34 warnings**, **0 unconnected** [M, kicad-cli 10.0.6 JSON, compared as a set]. By class: lib_footprint_issues 2, lib_footprint_mismatch 12, silk_edge_clearance 6, silk_over_copper 8, silk_overlap 6.
- **Against 17:09's 26 warnings, 11 are new and 3 are gone.** None is electrical. The new ones:
  - U2 and U5 no longer match their library footprints, because of the enlarged pads.
  - Module outlines on F.Silk now cross enlarged pads: U2 pin 7 (twice), U4 pins 11 and 12, U5 pins 1 and 3, and C2 pad 2 (U2's outline, twice).
  - U3's outline is clipped by the board edge. This comes from the last save's 0.2 mm move: the outline's bottom line now lies on the edge line, at y 98.0 [M]. U3's pads stay 1.15 mm inside the edge, against the 0.5 mm copper-to-edge rule [M].

  The 3 that are gone are O13(e)'s.
- The saved fill equals a refill: 1258.8 and 1549.5 mm² [M, pcbnew].
- An injected fault made DRC report shorting_items [M]: a GND stitching via moved onto the re-routed V_Fused track.
- Every stitching via lands in both layers' fill: 85 of 85 have their centre and at least 12 of 16 points around them inside each layer's fill [M].
- Schematic parity: **DID NOT RUN** (no `.kicad_sch`). This is a WARN, not a clean result.
- **A save made without a refill can hold copper that only DRC on the saved file catches.** The owner's 09:46 save of 2026-10-08 was made before a refill. Its saved GND fills sat inside the clearance of U4 pins 11 and 12 (BATT_RAW), whose pads that save had enlarged. At pin 12 the gap on B.Cu was 0.000 mm, so the saved copper shorted BATT_RAW to GND. DRC on the saved file gave 4 errors (3 clearance, 1 solder-mask bridge), and a refill cleared them [M]. So press B (Fill All Zones) and save before exporting Gerbers, and run DRC on the saved file as well as with `--refill-zones` (O11).

**Gate verdicts, rev 0.7 (2026-10-06):**

- DRC (`--severity-all --refill-zones`, with the board's `.kicad_pro` rules): **0 errors, 26 warnings** (lib_footprint_issues 2, lib_footprint_mismatch 10, silk_edge_clearance 5, silk_over_copper 3, silk_overlap 6), **0 unconnected**.
- The **17:09 save** gives the same on the saved file and after a refill: 0 errors, 26 warnings, 0 unconnected, and the same 26 entries by type and item [M, kicad-cli 10.0.6 JSON, compared as a set]. An injected fault, a GND track from the stitching via at (23.5, 29.0) onto the GND_SENSE track, made DRC report clearance and shorting_items [M], so GND_SENSE's separation from the pour is checked, not assumed.
- Schematic parity: **DID NOT RUN** (no `.kicad_sch`). This is a WARN, not a clean result.
- None of the 26 warnings is in an electrical class. The silk items worth fixing before the order are in O13 and O14.
- Rev 0.6's v7 gave 0 errors, 26 warnings (lib_footprint_issues 3, lib_footprint_mismatch 9, silk_edge_clearance 5, silk_over_copper 7, silk_overlap 2), 0 unconnected. Re-run on 2026-10-06 under kicad-cli 10.0.6, v7 gave 25: lib_footprint_issues 2, not 3. That class compares footprints against the installed libraries, so the difference is the libraries, not the board [I].

| Ref | Part (from the Value field) | Mounting | Pads → nets |
|---|---|---|---|
| U1 | Seeed XIAO ESP32-C3 | Sullins female sockets, 2 × 1×7, ~10 mm up (owner, 2026-10-06) | 3V3 → +3V3; GND; D1 → GPIO3; D2 → GPIO4_SW; SDA, SCL (§7.1). D3, D6 and D7 are unplated holes |
| U2 | Adafruit INA228 #5832 | Sullins socket, 1×8, ~10 mm up | 1 → +3V3; 2 → GND_SENSE (GND before the 17:09 save, §7.3); 3 → SCL; 4 → SDA; 6 → VIN−; 7 → VIN+; 5 (VBUS) and 8 have no net |
| U3 | Pololu D24V7F3, 3.3 V | Sullins socket, 1×3, ~10 mm up | V_Fused in, GND, +3V3 out |
| U4 | Pololu #2814 Big MOSFET Slide Switch, MP | Sullins sockets, 2 × 1×6, ~10 mm up | 1 (ON) → GPIO4_SW; 11–12 (VIN) → BATT_RAW; 5–6 (VOUT) → Batt_SW; 2–4 and 9–10 → GND; 7–8 have no net |
| U5 | Pololu #5382 ideal diode | **soldered** on pin headers, ~2.54 mm up (owner, 2026-10-03); in rev 0.7 it sits **under U4** | 1 → Batt_SW (from the switch); 3 → VIN+ (to the shunt); 2 and 4 → GND |
| F1 | 1 A slow-blow, 5 × 20 mm, in a Würth 696108003002 holder | soldered | BATT_RAW → V_Fused: the board supply only, not the charge path |
| C1 | 10 µF 25 V X7R, disc | soldered, **under U3's module** | +3V3 |
| C2, C3 | 0.1 µF 50 V X7R, disc | soldered; C3 **under the XIAO** | +3V3; C2 beside U2 |
| C4 | 47 µF 50 V, radial 6.3 × 11 mm | soldered | V_Fused (U3's input) |
| C5 | 0.1 µF 50 V X7R, disc | soldered | V_Fused (U3's input) |
| R1 | 1 kΩ 1/4 W, axial | soldered, **under the XIAO** (partly, before rev 0.8) | GPIO3 → GPIO3_LED |
| LED | Lite-On LTL-4231N, green diffused, 3 mm | soldered; **polarity in §5.5** | pad 1 (square) → GND; pad 2 (round) → GPIO3_LED |
| TB1, TB2 | Phoenix BC-381X9-2 GN (item 5442756), 2-position 3.81 mm screw terminals | soldered | §5.1 |
| NT1 (`REF**` until rev 0.8, O16) | Net tie, KiCad `NetTie-2_SMD_Pad0.5mm` (17:09 save) | F.Cu copper only; nothing to fit | pad 1 → GND, on TB2-2's pad edge at (17.54, 25.17); pad 2 → GND_SENSE |
| H1, H3, H4 | M3 mounting holes, for nylon screws and standoffs (owner, 2026-10-06) | — | no net. In rev 0.7 each is **under a module**: H1 under U2, H3 under U1, H4 under U4 [M]. Rev 0.8 moves H3 and H4 by about 0.5 mm, and each is still under the same module [M] |

The V_Fused capacitors are rated 50 V against the PSU's 22.5 V OVP ceiling [S, §4.1]. C1, at 25 V, sits on 3.3 V.

**Solder the parts that sit under a module first:** C1 under U3, and C3 and R1 under the XIAO. The 2026-10-03 review's 3D render showed C1 clearing U3's underside at the 8.5 mm socket height [D, render]. On the bench, a module that will not seat fully on its socket is the tell. The plan-view courtyards cannot show this, because U3's covers only its 1×3 socket.

**Rev 0.7 adds three steps, all before any module is seated:**

1. **U5 goes under U4.** Solder it, then trim its header pins flush with the top of the #5382's board. Untrimmed, their tips come within about 1.35 mm of U4's underside [D, the board file's 3D models with U4 ~10 mm up]. U5 pin 3 (VIN+) is 2.72 mm from one of U4's 2.18 mm mounting holes [M], whose net is assumed to be GND [I, not read from Pololu's drawing]. That figure is rev 0.7's. In rev 0.8 U4 moved 0.9 mm down and U5 0.6 mm, so the gap changed by no more than 0.3 mm [D]; it was not re-measured.
2. **Fit the board to its standoffs.** H1, H3 and H4 are each under a module, so their nylon screws cannot be reached once the modules are on.
3. **Land TB2's wires.** TB2-1's screw is under U2 (§5.1).

**Netlist** [M, board file 2026-10-06]. The power nets are 1.5 mm track on F.Cu, each a single route; +3V3 and V_Fused are 1.5 mm on F.Cu too. Signals are 0.2 mm, and GND_SENSE 0.5 mm. In rev 0.7, GPIO4_SW, SDA and SCL run on **B.Cu** (24.2, 11.8 and 11.6 mm), through the bottom pour, with no signal vias; GPIO3 and GPIO3_LED stay on F.Cu. Rev 0.6 had every track on F.Cu. §7.3 gives what the B.Cu runs cost the ground. **Rev 0.8** [M, the 10:48 save]: the nets and their pads are unchanged, and only the copper differs. BATT_RAW, Batt_SW and VIN− are 1.7–4.0 mm on F.Cu, and VIN+ is 2.9–4.0 mm on B.Cu (§6.4, §7). V_Fused stays 1.5 mm. GPIO4_SW now changes layer through one via (16.9 mm on B.Cu, 8.7 mm on F.Cu); SDA and SCL stay on B.Cu (11.3 and 12.3 mm).

- **BATT_RAW:** TB1-2, U4 VIN (11, 12), F1.
- **Batt_SW:** U4 VOUT (5, 6), U5 pad 1.
- **VIN+:** U5 pad 3, U2 pin 7.
- **VIN−:** U2 pin 6, TB2-1.
- **V_Fused:** F1, C4, C5, U3 VIN.
- **+3V3:** U3 VOUT, U1 3V3, U2 pin 1, C1, C2, C3.
- **GPIO4_SW:** U1 D2 and U4 pin 1 (ON), and nothing else.
- **GPIO3:** U1 D1 and R1. **GPIO3_LED:** R1 and LED pad 2.
- **SDA / SCL:** U1 to U2 pins 4 / 3.
- **GND:** a pour on both layers, stitched by 78 vias in the 17:09 save (77 at 15:16; rev 0.6: 92; rev 0.8: 85). It reaches 18 pads: TB1-1, TB2-2, U1, U3, U4 (2–4, 9, 10), U5 (2, 4), C1–C5, LED pad 1 and the net tie's pad 1. At 15:16 U2 pin 2 stood where the tie's pad is now (§7.3).
- **GND_SENSE** (17:09 save): U2 pin 2 and the net tie's pad 2, by one 0.5 mm F.Cu track, 8.87 mm. It carries only U2's own supply return, a few mA at most [I], and the tie at TB2-2 is its one join to GND (§7.3).

| Setting | Charger build | Why |
|---|---|---|
| INA228 onboard 15 mΩ shunt | **KEEP** | It is the charger's shunt. At 3.64 A it drops 55 mV [D], inside the ±163.84 mV range [D: 312.5 nV × 2¹⁹, from `battery-bank-monitor.yaml`]. The board is sold for up to 10 A [S, Adafruit #5832 page] |
| Breakout VBUS jumper | **CLOSED** (VBUS = VIN+) | High-side use [S, Adafruit #5832 page]. U2 pin 5 (VBUS) has no net on this board [M, board file v6 and 2026-10-06], so the closed jumper reaches nothing else, and no VBUS lead is needed |
| **No pull-up on GPIO4_SW** | **mandatory**; the board has no position for one | GPIO4 powers up high-impedance with no internal pull (reset state "1") and is not in the power-up glitch table [S, ESP32-C3 datasheet pp.20–21]. A 10 kΩ pull-up (the V2 board's R3) would hold ON at 2.2 V [D: 3.3 × 20/30, where 30 kΩ = R3 10 kΩ + the #2814's on-board 20 kΩ] through every boot, watchdog reset and flash, above the ~1 V threshold, so **the charger turns on whenever the ESP32 is not running** (§7.2) |
| Board supply | **BATT_RAW, upstream of the switch** (TB1-2 in rev 0.7, from PSU +V) | Board alive whenever AC is on; zero battery drain when AC is off |
| F1 (1 A slow-blow, BATT_RAW → V_Fused), U3 D24V7F3 | as on the V2 board | The D24V7F3 takes 4–36 V [[ws] §3.1], which covers the PSU's 22.5 V OVP ceiling [S] |

### 7.1 XIAO pin map (charger)

| XIAO | GPIO | Net | Charger function |
|---|---|---|---|
| D1 | GPIO3 | GPIO3 → R1 → LED | **Status LED** (FW-11), active-high. Reset state "1", no internal pull, not in the glitch table [S, ESP32-C3 datasheet pp.20–21], so the LED stays dark until the firmware drives it |
| D2 | GPIO4 | GPIO4_SW → U4 ON | **Charge enable** output, active-high. Boot-safe because nothing pulls the net up (§7.2) |
| D4 / D5 | GPIO6 / GPIO7 | SDA / SCL | INA228 |
| 3V3, GND | — | +3V3, GND | Supplied by U3 |

Every other XIAO pin has no net [M, board file 2026-10-06]: 5V, D0, D8, D9 and D10 (GPIO10). The footprint's D3 position is a plain non-plated hole. In rev 0.7, **D6 and D7 (GPIO20) are non-plated too**, with 1.02 mm holes, 1.7 mm mask openings and no copper (owner: "to gain clearance for the 3.3 V rail"). In rev 0.6 they were plated pads with no net. Their socket pins pass through unsoldered. The nearest copper is the VIN+ track along the left edge, 0.30 mm outside both mask openings; no +3V3 copper is within 1.5 mm [M]. The SDA track on B.Cu passes 0.25 mm from D3's hole, which is exactly the board's min_hole_clearance of 0.25 mm; DRC passes it [M]. The strapping pins GPIO2 (D0), GPIO8 (D8) and GPIO9 (D9) are among the unconnected pins, so nothing on the board can pull them at boot [S, Seeed XIAO ESP32C3 wiki pin map].

### 7.2 Switch control net (on-board)

| Ref | Part | Connects | Purpose |
|---|---|---|---|
| Rs | *Withdrawn in rev 0.4* (owner, 2026-09-21) | — | GPIO4 drives ON directly. On the board, GPIO4_SW is one 0.2 mm track from U1 D2 to U4 pin 1 (ON), with no other pad on the net [M, board file v6 and 2026-10-06]. Rev 0.7 moved it to B.Cu. There is no series position. The V2 board had none either: XIAO D2, R3 pad 1 and J2-1 only [M, Gerber X2 net attributes, 2026-09-21]. A swapped control pair is no longer possible, because the J2 cable is now copper. The §5.4 continuity check proves U4 is seated, and FW-1's 5 mA drive strength limits what the pin pushes into a fault. **Left uncovered:** +V reaching the track, through a solder bridge or a mis-seated #2814. That would cost the socketed XIAO, and it turns the charger on whatever the firmware does. That is L6's case, the same as a shorted #2814 |
| — | *(on the #2814)* R4 10 kΩ + R5 10 kΩ | ON → R4 → Q3 base; R5 base → emitter (GND) | **The off-state pull-down, already on the board** [S, Pololu schematic]. With ON floating, R5 holds Q3's base at 0 V and the switch is off. That is Pololu's "leaving it disconnected will leave the switch off". GPIO4's input leakage, at most 50 nA [S, ESP32-C3 datasheet Table 14 p.32], gives at most 1 mV across 20 kΩ [D]. GPIO high drives ON to ~3.3 V at 0.17 mA [D: 3.3 V ÷ 20 kΩ], above the ~1 V threshold [S, §4.2]; R4/R5 halve it onto Q3's base-emitter junction |

> **Correction record (R13), 2026-09-21.** Rev 0.2 and the first draft of rev 0.3 specified an external **Rpd 10 kΩ** (ON → GND at the switch) to hold ON low with GPIO4 high-impedance, and gave ON = 3.0 V [D: 3.3 × 10/11]. Both were written before the switch's schematic was read. The board already has R4 + R5 = 20 kΩ from ON to GND, which does that job, so Rpd was redundant and the 3.0 V omitted the on-board resistors. The owner asked why Rpd was required, and the schematic answered it. Rpd was withdrawn (W15). T1 and T2 now prove the on-board pull-down. Evidence: Pololu "Big MOSFET Slide Switch with Reverse Voltage Protection" schematic (file 0J1071, ©2015), read 2026-09-21.

> **Correction record (R13), 2026-09-21.** Rev 0.3 (`34e4a52`) said the ESP32's leakage across the 20 kΩ was "microvolts". The datasheet's maximum input leakage is 50 nA [S, ESP32-C3 datasheet Table 14 p.32], which gives up to 1 mV [D]. The conclusion stands, because turn-on needs ~1 V, but the figure was wrong. It was found while answering the owner's question about Rs.

**Off at every reset: why GPIO4, and why GPIO4_SW has no pull-up.** Power-on, an AC blip, a watchdog reset (L3), an OTA reflash or a crash each leave the ESP32 in ROM and the bootloader for a few hundred milliseconds before ESPHome drives GPIO4 low. In that window the hardware alone holds the switch off:

1. GPIO4 returns to reset state "1": input, high-impedance, no pull [S, ESP32-C3 datasheet pin table p.20, key p.21]. It is not in the power-up glitch table [S, Table 7 p.21].
2. With ON undriven, the #2814's R5 holds Q3's base at 0 V and the switch is open [S, Pololu schematic].
3. Leakage gives at most 1 mV against a ~1 V turn-on [D, above].
4. Only then does FW-1 drive GPIO4 low (`restore_mode: ALWAYS_OFF`), confirming a state the hardware already set.

No added part, no firmware and no resistor ratio is involved. Adding a pull-up to GPIO4_SW is the one way to break it, and the board (rev 0.6 and rev 0.7) has no position for one (§7). T1 and T2 prove it on the hardware.

**GPIO20, the bank board's LED pin, is not an alternative control pin, and it is not used.** It resets in state "3", with its internal pull-up on [S, p.20–21]. That would lift ON to ~1.0 V at every reset [D: 3.3 × 20/66, with the pull-up at its typical 45 kΩ (Table 14), R4 1 kΩ and the #2814's 20 kΩ]. The datasheet gives that pull-up no minimum, so no added pull-down could be proven adequate on paper. The rev 0.6 board moves the LED to GPIO3 (D1). It resets in state "1" with no pull and no glitch [S, pp.20–21], so the LED stays dark through every reset (§5.4).

**The #2814 slide must be locked in OFF.** External ON control works only with the slide OFF: "if the physical switch is in the 'off' position, the switch state can also be controlled by a digital signal … via the 'ON' control pin" [S, #2814 page]. Glue or lacquer it.

### 7.3 Ground: the pour, and what it costs VBUS

The ground is copper pour on both layers, stitched by 78 vias in the 17:09 save (77 at 15:16, 92 in rev 0.6, 85 in rev 0.8), with no star point [M, board file 2026-10-06]. The charge return enters at TB2-2 (pack −) and leaves at TB1-1 (PSU −V; TB1-2 in rev 0.6). The INA228's ground (U2 pin 2) sits on the same pour, so part of the return path is shared with its reference. **VBUS reads high** by the drop across that shared part. The pack's negative terminal sits above U2's ground by I × R_shared. **The owner's 17:09 save removes the shared part** with a Kelvin connection (below). The table, the effect and the B.Cu-track study are the 15:16 save's: the baseline it improved on.

| Case | R_shared, TB2-2 → U2 pin 2: rev 0.6 | rev 0.7, 15:16 | Whole pour, TB2-2 → PSU −V pad: rev 0.6 | rev 0.7, 15:16 |
|---|---|---|---|---|
| 0.1 mm cells, ideal vias | 0.383 mΩ | 0.382 mΩ | 1.720 mΩ | 1.632 mΩ |
| 0.05 mm cells, ideal vias | 0.375 mΩ | 0.377 mΩ | 1.699 mΩ | 1.596 mΩ |
| 0.1 mm cells, 1.5 mΩ per via barrel [I] | 0.407 mΩ | 0.376 mΩ | 1.819 mΩ | 1.749 mΩ |

All rows are [D]. The PSU −V pad is TB1-2 in rev 0.6 and TB1-1 in rev 0.7. **Effect (rev 0.7, 15:16 save):** VBUS reads high by 0.75–0.76 mV at 2.0 A, and by 1.37–1.39 mV at 3.64 A [D: I × 0.376–0.382 mΩ]. Rev 0.6 gave 0.75–0.81 and 1.36–1.48 mV. The lead alone drops 58–73 mV at 3.64 A (§6.4), so the pour is a small term in R_series, and T10 measures R_series whole.

**What rev 0.7 changed [D, differences of the table's rows].** The whole pour fell by 0.070–0.104 mΩ. R_shared moved by −0.001 and +0.002 mΩ in the ideal-via rows, which is inside the 0.006–0.008 mΩ the two cell sizes disagree by, so it is unchanged. In the barrel row it fell by 0.032 mΩ. At 3.64 A, the whole-pour drop is 5.81–6.37 mV and its loss 21.1–23.2 mW [D: I × R, I² × R], against 6.19–6.62 mV and 22.5–24.1 mW in rev 0.6. Both changes are small beside the 58–73 mV in the lead.

- **The B.Cu signal tracks (rev 0.7).** GPIO4_SW, SDA and SCL cut slots in the bottom pour, so they were sized directly. pcbnew refilled the rev 0.7 file three ways and the solver ran on each:
  - **Control: refilled, nothing removed.** Same fill as the saved file, 1278.9 mm² on the zone that pours both layers and 1772.5 mm² on the B.Cu zone [M, pcbnew]. Same results as the table.
  - **SDA and SCL deleted, then refilled.** The B.Cu fill gains 19.5 mm². R_shared 0.441 / 0.432 / 0.437 mΩ and whole pour 1.479 / 1.449 / 1.575 mΩ, in the table's row order.
  - **All three deleted, then refilled.** The fill gains 44.4 mm². R_shared 0.442 / 0.433 / 0.440 mΩ and whole pour 1.452 / 1.423 / 1.531 mΩ.

  So the tracks as laid **raise** the whole pour by 0.173–0.218 mΩ and **lower** R_shared by 0.057–0.064 mΩ [D]. The I²C pair is most of it (+0.146–0.174 and −0.056–0.062 mΩ). It runs from U2 down to the XIAO (x 19–30 mm, y 31.6–38.4), just south of U2 pin 2 and across the return path from TB2 to TB1. GPIO4_SW, down the right side, adds +0.026–0.044 and −0.001–0.003 mΩ. At 3.64 A, that is 0.63–0.80 mV more whole-pour drop and 2.3–2.9 mW more loss, and VBUS reads 0.21–0.23 mV *less* high [D]. Why a slot lowers R_shared [I, no field map was drawn]: it closes off the copper around U2 pin 2 to the south, so little return current flows past the pin and the pin sits nearer TB2-2's potential. **No reroute is needed:** the larger term is under 0.22 mΩ, and the term the INA228 sees moves the right way.
- **The Kelvin GND (owner, 17:09 save).** U2 pin 2 is now its own net, GND_SENSE. A net tie (`NetTie-2_SMD_Pad0.5mm`; its reference is still `REF**`, O16) joins it to GND on F.Cu: pad 1 sits on TB2-2's pad edge at (17.54, 25.17), and a 0.5 mm track runs 8.87 mm from pad 2 to U2 pin 2 [M, board file]. TB2-2's zone connection is Solid. The edit moved one stitching via and added another (77 → 78). The fills changed from 1278.9 to 1270.0 mm² on the two-layer zone and from 1772.5 to 1775.9 mm² on the B.Cu zone [M, pcbnew]. In the table's row order [D, `gnd_drop.py`]:
  - **Whole pour** 1.584 / 1.550 / 1.701 mΩ, down 0.045–0.048 mΩ from 15:16. At 3.64 A it drops 5.64–6.19 mV and loses 20.5–22.5 mW.
  - **The Kelvin residual**, V(TB2-2) − V(tie pad 1), is 0.0049 / 0.0024 / 0.0049 mΩ. The solver holds each pad at one potential, so it leaves out the spreading inside TB2-2's pad, from the pin out to the tie at its edge: 0.047 mΩ on one layer [D: 0.4926 mΩ/sq × ln(1.0/0.55) ÷ 2π, for radial flow from the 1.1 mm hole to the 2.0 mm pad's edge; the radial model is [I]].
  - So **VBUS reads high by ≤ 0.11 mV at 2.0 A and ≤ 0.20 mV at 3.64 A** [D: (0.0049 + 0.05) mΩ × I], down from 0.75–0.76 and 1.37–1.39 mV. That is about one 195.3 µV LSB at most, beside the INA228's own VBUS error of up to ±9.70 mV at 14.40 V [D: 14.40 V × 0.05 % + 2.5 mV, from TI SLYS021A p.5 [S]].
  - **Solid, not a thermal relief.** A relief with 0° spokes was tried and raised the whole pour by about 0.06 mΩ [D]. Solid puts TB2-2's pin straight into the pour on both layers, so it will take more heat to solder than its neighbours [I: falsifier, solder that does not wet the pin's whole ring at the iron's usual setting]. Inspect its fillet from both sides.
  - `gnd_drop.py` prints R_shared only when U2 pin 2 is on GND. On this file it skips that line without saying so (O16), and the residual above is read from its per-pad list.
- **Rev 0.8 (the 2026-10-08 10:48 save).** The tie, its pad positions and its track are unchanged, and its reference is now NT1. TB2-2's pad is now 3.0 mm and TB1-1's 2.0 mm, and both meet the pour through thermal reliefs, for hand soldering [M]. That supersedes "Solid, not a thermal relief" above. There are 85 stitching vias, and the fills are 1258.8 mm² on the two-layer zone and 1549.5 mm² on the B.Cu zone [M, pcbnew; a refill reproduces them]. In the table's row order [D, solver with the fix below]:
  - **Whole pour** 1.965 / 1.932 / 2.054 mΩ, up 0.380 / 0.381 / 0.353 mΩ from 17:09. The two reliefs account for 0.173–0.180 mΩ of that, found by changing only them on a copy of the owner's 2026-10-06 22:29 save [D]. The rest is copper that the wider power tracks, VIN+'s B.Cu run and the larger pads, with their clearances, take out of the pour [I: not split further]. At 3.64 A the pour drops 7.03–7.48 mV and loses 25.6–27.2 mW [D: I × R, I² × R]. The charge-path tracks fell by far more (§7.4), so the loop is lower overall.
  - **The Kelvin residual** is 0.0000 mΩ in all three rows. The tie's pad 1 now lies inside TB2-2's larger pad, so the solver puts both on one node. The spreading inside the pad, from the pin out to the tie, is unchanged at about 0.047 mΩ, because the tie is still 1.0 mm from the pin's centre [D: as above; the radial model is [I]]. So VBUS reads high by ≤ 0.10 mV at 2.0 A and ≤ 0.18 mV at 3.64 A [D: 0.047 mΩ × I].
  - **The repo's `gnd_drop.py` gives a false residual on rev 0.8** (O16). Once TB2-2's pad reaches about 2.5 mm, the tie's pad falls inside it, and the script then reads the residual from the wrong node: it printed 0.240 mΩ on the 08:04 save [D, false]. The figures above come from a scratch copy that numbers the tie's node last. **Fixed in the repo on 2026-10-08** (O16): a pad that loses all its copper to a later pad is now numbered last, and a pad left with no node is refused. The fixed script gives the same figures as the old one on every save from 2026-10-06 15:16 to 22:29, with no per-pad value changed, and 0.0000 mΩ on every save from 2026-10-07 19:09 on [M, both scripts on the 17 saves, `--h 0.1`].
- **Method.** Finite differences on the GND copper, rasterised at 0.1 mm and 0.05 mm. The model includes both layers' zone fills as KiCad refills them, the GND tracks, and the through-hole GND pads (both layers, each pad one node). It also includes the stitching vias (78 at 17:09, 77 at 15:16), as ideal links or with a barrel resistance. Sheet resistance is 0.4926 mΩ/sq [D: ρ 1.724 × 10⁻⁸ Ω·m, annealed copper at 20 °C, ÷ 35 µm]. 1 A goes in at TB2's GND pad and out at TB1's. The solver finds each by reference and net, not by pad number (R13 note in the code, 2026-10-06: rev 0.7's TB1 swap broke the old pad-2 selection). The solver is `gnd_drop.py`, which moved on 2026-10-08 from `pcb/` here to the Tools repo: [`pcb-eval/solve/gnd_drop.py`](https://github.com/wkcollis1-eng/Tools/blob/e6c198f66fdf1c933df72e4e666ca1a19c05137f/pcb-eval/solve/gnd_drop.py). Run it from a Tools checkout as `python pcb-eval/run.py gnd_drop <board file>`. The move changed one thing: the board file is now a required argument (it used to default to the board beside the script).
- **Solver checks.** A uniform strip, solved by the same code, gave 1.9481 mΩ against 1.9457 mΩ exact. A pour cut in two is refused by its connectivity check, and a board with no TB2 is refused by the pad selection. `python gnd_drop.py --self-test` runs all three.
- **Limits (R11).** Two geometries. Rev 0.6 was computed on v4 (2026-10-03); its copper is byte-identical in v5, v6 and v7, whose diffs touch only silk text, the LED footprint (same pads, same nets) and a 3D-model offset [M]. A re-run on v7 reproduced all three rev 0.6 cases, on 2026-10-03 and again on 2026-10-06 with the fixed solver [M]. Rev 0.7 was computed on the 2026-10-06 15:16:19 file and on the 17:09:17 save. A pcbnew refill reproduces each saved fill exactly [M]. Left out: resistance inside the modules, the socket contacts, the solder joints, and temperature (copper at 20 °C; warmer copper reads higher). The copper thickness, 1 oz (35 µm), is assumed, not measured. The 1.5 mΩ barrel is [I].
- **Falsifier (T10).** With a known charge current flowing, probe the solder joints on the board's underside, not the screws. (1) TB2-2's pin to U2's socket pin 2 (GND_SENSE): ≤ ~0.11 mV at 2.0 A [D, above]. More than 0.5 mV falsifies the Kelvin figures [I: the margin covers a 0.1 mV meter resolution and probe placement]. (2) TB2-2's pin to TB1-1's pin: 3.1–3.4 mV at 2.0 A [D: 1.550–1.701 mΩ × 2.0 A]. More than 5 mV falsifies the pour model [I: the margin covers the 1 oz assumption, warm copper and the pin joints]. If either trips, look for a joint or a thin pour before a modelling error. **R13 (2026-10-06):** rev 0.6 and the first rev 0.7 draft put the probe on TB2-2's screw. That reading includes the terminal's own clamp-to-pin drop, which the model leaves out and which has not been measured [I: about 1 mΩ would add about 2 mV at 2.0 A], so a sound board could have tripped the old 1.5 mV threshold.

### 7.4 Improvement study, and the VIN+ re-route (planned 2026-10-06, done in rev 0.8)

After the Kelvin GND, the owner asked what else would improve the board electrically, and proposed a shorter VIN+ on B.Cu. Figures are [D] on the 17:09 save unless tagged, at 1 oz and 20 °C (§7.3, Limits). Two effects are kept apart:

- **What VBUS reads.** Only copper between the pack and the INA228's reference moves it: the pour's shared path (now ≤ ~0.055 mΩ, §7.3) and the VIN− track, which T10 measures inside R_series (§6.4).
- **What the loop costs.** Every charge-path conductor adds drop and heat: the board's tracks, the pour, the socket contacts and the lead. VIN+ is in the loop but upstream of the VBUS sense point, so changing it changes no reading. A lower loop resistance raises the opening current a little [I: T11 measures it, and FW-4's overload stop and t_ol are set from T11].

**Baseline: the 17:09 save** (309,654 B, sha256 `484347efc18dab8977edf261f263d09099937cb40ec9514db8752c9c1c653b5d`; its `.kicad_pro`, 9,805 B, sha256 `c2c4390b8853b105a179ccb513242b1f844c5a0ecbd582b303f57a4ee791b847`). Both were in [`pcb/`](pcb/) until rev 0.8 replaced them; git keeps them at commit `f77169e`.

| Quantity | 17:09 save | Source |
|---|---|---|
| Charge-path track: BATT_RAW, Batt_SW, VIN+ and VIN− | 38.10 mΩ | [D: each net's segments solved as a network, 0.4926 mΩ/sq, T-junctions split, vias ideal] |
| of which VIN+, U5 pad 3 → U2 pin 7: F.Cu only, 1.5 mm, 77.56 mm | 25.15 mΩ (25.47 taken as one series run) | [D, same] |
| Whole pour, TB2-2 → TB1-1, §7.3's three rows | 1.584 / 1.550 / 1.701 mΩ | [D, `gnd_drop.py`] |
| Kelvin residual, V(TB2-2) − V(tie pad 1), same rows | 0.0049 / 0.0024 / 0.0049 mΩ | [D, `gnd_drop.py`'s per-pad list] |
| Zone fill: two-layer zone / B.Cu zone | 1270.0 / 1775.9 mm², reproduced by a refill | [M, pcbnew] |
| Stitching vias | 78 | [M] |
| DRC | 0 errors, 26 warnings, 0 unconnected: §7's 26 entries | [M, kicad-cli 10.0.6] |

**Options**, at 2.0 A, the steady case:

| Option | Loop | VBUS | Outcome |
|---|---|---|---|
| Kelvin GND for U2 pin 2 | whole pour −0.045–0.048 mΩ | offset 1.37–1.39 → ≤ 0.20 mV at 3.64 A | **Done** (owner, 17:09; §7.3) |
| Widen VIN+ to fill its corridor | 25.5 → 17.3 mΩ: −16 mV, −33 mW | none | Possible. The left-edge run is boxed at 1.65–1.70 mm by TB2-2, U1 and H3, so most of the gain is on the other runs. **Superseded** by the B.Cu route, which rev 0.8 lays 2.9–4.0 mm wide (below) |
| 2 oz copper | track 38.10 → 19.05 mΩ, pour 1.58 → 0.79 mΩ: −38 mV, −76 mW | VIN− 5.67 → 2.84 mΩ, inside R_series, which T10 measures anyway | A fab option, not a layout change. Not taken up |
| Narrow +3V3 from 1.5 to 0.5 mm | F.Cu fill 1270.0 → 1342.3 mm² [M]; whole pour −0.018–0.023 mΩ | none | **Not worth it.** Safe: 0.5 mm carries 1.45 A at a 10 °C rise [D, IPC-2221 as in §6.4, A = 27.1 mil²]. But U3's output to the XIAO's 3V3 pin drops 44.4 mV at 600 mA, the D24V7F3's continuous rating [S, Pololu #5592 page], against 14.8 mV at 1.5 mm. 0.8 mm gives a whole pour within 0.005 mΩ of 0.5 mm's. +3V3 bounds no VIN+ corridor |
| Remote sense of the pack | — | would take R_series out of VBUS | **Rejected.** A loose sense wire would corrupt the reading the 14.60 V ceiling acts on (§9), and the wire would need its own fuse |
| VIN+ on B.Cu, shorter (owner) | about −7.3 mΩ: ~15 mV, ~29 mW [D on a hand route, not laid] | none | **Done** in rev 0.8 (O15 closed): 25.00 → 7.15 mΩ [D, the 2-D solve below], with no vias |

**Why not a straight line.** U5 pad 3 to U2 pin 7 is 37.3 mm straight [D, from the pad coordinates]. On B.Cu that line crosses GPIO4_SW near (28.5, 40.1) and the XIAO's top row of pins (y 38.38), whose gaps are 0.84 mm [M], too narrow for 1.5 mm. XIAO D7 is an unplated hole (§7.1), so the route passes beside it. GPIO4_SW cannot move to F.Cu whole, because there it would cross GPIO3.

**A route that fits**, hand-checked against the board's pads, tracks and holes, not laid: F.Cu from U5 pad 3 along the present route to (14.75, 52.5), between H3 and D7; four vias to B.Cu; B.Cu diagonally between H3 and C3 to (23.75, 43.5); along y 43.5, between the XIAO's top row and R1, to (34, 43.5); up past the right side of XIAO D0 to (37.46, 40.04); and up to U2 pin 7. About 54.2 mm: 17.8 mΩ of track plus ~0.4 mΩ for the vias [I: 1.5 mΩ per barrel, four in parallel], against 25.15 mΩ. It costs:

- GPIO4_SW hops to F.Cu and back, by two vias near (30.7, 42.25) and (32, 44.75), about 0.9 mm from GPIO3 [D, hand clearance].
- About six stitching vias move.
- A 1.5 mm track with 0.5 mm zone clearance each side cuts a 2.5 mm slot diagonally across the B.Cu pour, in the return path from TB2 to TB1. In return the F.Cu pour regains the left-edge and top strips the present route occupies. **Which way the whole pour moves is not known until it is solved.**

The owner's route may differ; the method below applies to whatever is laid.

**Evaluation method**, for the session that reviews the re-route. Run each step on a copy, and give each result against its baseline figure:

1. **Identity.** Copy the saved `.kicad_pcb` and `.kicad_pro` out of the owner's folder (KiCad keeps the original open), and record size, save time and sha256. Diff the board against the 17:09 baseline item by item: footprints, every pad's net, tracks by net and layer, vias and zone fills. Expect changes on VIN+, GPIO4_SW (if it hops) and GND vias only, and **no pad's net**. Name and explain anything else before going on.
2. **DRC**, `--severity-all --refill-zones`. Accept 0 errors and 0 unconnected. Compare the warnings as a set against the baseline's 26, and name any new one. Then inject a fault on the new route, such as a VIN+ via moved onto a GND via, and show that DRC reports it (R7).
3. **Fill.** A pcbnew refill must reproduce the saved fill areas, so the solver reads current copper.
4. **Pour.** Run `gnd_drop.py` (in the Tools repo, §7.3 Method) on the copy three ways (`--h 0.1`; `--h 0.05`; `--barrel-mohm 1.5`) against 1.584 / 1.550 / 1.701 mΩ. Read the Kelvin residual from the per-pad list (O16) against 0.0049 / 0.0024 / 0.0049 mΩ. It should stay under 0.01 mΩ [I]; a larger one means the new slot changed the copper around TB2-2, so look at the tie's placement.
5. **VIN+.** Solve the VIN+ segments as a network, layer by layer, with each via at 1.5 mΩ [I], against 25.15 mΩ. The hand route predicts ~18.2.
6. **Net change in the loop** = ΔR(VIN+) + Δ(whole pour), in each of the three pour cases. Accept the re-route if all three are negative, and give the change in mV and mW at 2.0 A.
7. **Width and vias.** Keep VIN+ at 1.5 mm, like the rest of the power path; for any narrower segment, redo §6.4's IPC-2221 figure. Record the number of VIN+ vias and their drill. Four would share 3.64 A at 0.91 A each [D]; whether a 0.3 mm via carries that is not checked here.
8. **GPIO4_SW** still reaches U1 D2 and U4 pin 1 and nothing else (§7.2).
9. **Record.** Update §6.4, §7's netlist and verdicts, §7.3's Kelvin figures and this section; close O15; copy the file into `pcb/`; then export the Gerbers (O11).

The track network solve and the DRC set comparison were run with scratch scripts that are not in this repo; the method above is enough to repeat them.

**Outcome: rev 0.8, the owner's 2026-10-08 10:48 save** (§7 gives its identity and gate verdicts). The tracks were wider than some of their pads and joined by overlap, so the one-dimensional network solve above no longer applies. Both columns below therefore use a two-dimensional solve of each net's copper (tracks and pads, 0.05 mm cells, 0.4926 mΩ/sq, current entering and leaving at each pin's drill). On the 17:09 save it gives 37.33 mΩ for the four nets, against the network solve's 38.10.

| Quantity | 17:09 save | 10:48 save | Source |
|---|---|---|---|
| BATT_RAW track | 3.514 mΩ | 1.177 mΩ | [D, 2-D solve] |
| Batt_SW track | 3.469 mΩ | 1.484 mΩ | [D, same] |
| VIN+ track | 25.003 mΩ | 7.148 mΩ | [D, same] |
| VIN− track | 5.345 mΩ | 2.359 mΩ | [D, same] |
| Charge-path tracks, total | 37.33 mΩ | 12.17 mΩ | [D, sum] |
| Whole pour, §7.3's three rows | 1.584 / 1.550 / 1.701 mΩ | 1.965 / 1.932 / 2.054 mΩ | [D, `gnd_drop.py`; the 10:48 column with the tie numbered last, §7.3] |
| Kelvin residual, same rows | 0.0049 / 0.0024 / 0.0049 mΩ | 0.0000 mΩ in each | [D, same] |
| Zone fill: two-layer zone / B.Cu zone | 1270.0 / 1775.9 mm² | 1258.8 / 1549.5 mm² | [M, pcbnew; the 10:48 figures equal a refill] |
| Stitching vias | 78 | 85 | [M] |
| DRC | 0 errors, 26 warnings, 0 unconnected | 0 errors, 34 warnings, 0 unconnected | [M, kicad-cli 10.0.6] |

With the whole pad taken as the contact instead of the drill, the 10:48 tracks give 0.822 / 1.258 / 6.762 / 2.101 mΩ [D], so the drill figures are the conservative ones.

- **Net change in the loop** (step 6). VIN+ fell by 17.86 mΩ and the pour rose by 0.353–0.381 mΩ, so the re-route is accepted in all three pour cases [D]. Taking every change together, the board's share of the loop (tracks plus the pour's barrel row) went from 39.03 to 14.22 mΩ, down 24.81 mΩ [D]. That is 49.6 mV and 99 mW less at 2.0 A, and 90 mV and 329 mW less at 3.64 A [D: ΔR × I, ΔR × I²].
- **The board is now the smallest known term in the loop.** The known parts total 85.3–89.3 mΩ [D: board 14.22 + #2814 30 [S, §4.2, max at 10 V] + #5382 ≤ 10 [S, §6.4] + shunt 15 [S, Adafruit #5832] + lead 16.1–20.1 [D, §6.4]]. It leaves out the module socket contacts, TB1, TB2, the splice, the QDs and the pack, none of which has a figure here. At 3.64 A the known parts drop 0.31–0.33 V [D]. A lower loop raises the opening current, until the PSU's overload limit caps it (§4.1) [I: T11 measures it, and FW-4's overload stop and t_ol are set from T11].
- **Departures from the plan above.**
  - Step 1 expected changes on VIN+, GPIO4_SW and GND vias only. Rev 0.8 also widened every power net, enlarged pads, changed two zone connections and moved parts (§7's rev 0.8 list). Each was named before going on, and **no pad's net changed** [M: the (part, pad, net) sets of the two saves are equal, apart from one XIAO pin with no net, whose pad name went from blank to D6].
  - Step 2's fault was injected on V_Fused, not on VIN+, because VIN+ has no vias in rev 0.8.
  - Step 5 has no barrel term, for the same reason.
  - Step 7: VIN+ is 2.9–4.0 mm, wider than the 1.5 mm asked for, so §6.4's IPC-2221 figures are redone for the new widths.
  - Step 8 holds: GPIO4_SW reaches U1 D2 and U4 pin 1 and nothing else [M].
  - Step 9 is this revision, except the Gerbers (O11).
- **R13 (2026-10-08): some of rev 0.8's copper began as edits written by a review session, not by the owner.** On 2026-10-06 at 20:35, the session reviewing the board wrote a set of scripted edits into the owner's board file (session 4dcbc5e4). One of them widened the power path, and with it the BATT_RAW branch from U4 to F1, from 1.5 to 2.95–3.95 mm. That branch carries only the board supply (§6.4), so its width bought nothing. The same edit set TB1-1's pour connection to solid, which was never weighed against hand soldering. Neither was recorded here. Later review sessions found both and noted them only in their local review notes. The owner returned TB1-1 to a thermal relief in the 2026-10-07 19:09 save and narrowed the branch to 2.0 mm in the 2026-10-08 09:46 save. The rest of that edit, the wider charge path, is in rev 0.8 at the widths §7 lists.

**Limits (R11).** These are copper resistances at 1 oz and 20 °C, computed on one file. They leave out the socket contacts, the solder joints and the modules' own copper, and the via barrel is [I]. Nothing here has been measured on a built board; T10 measures the series path whole.

---

## 8. Protection ladder

| Layer | What stops the charge | Catches | Does not catch | Proven by |
|---|---|---|---|---|
| L1 | Firmware normal end: time at voltage (FW-6) | normal completion | everything below | T11 |
| L2 | Firmware hard stops: VBUS ceiling, I_max, PSU overload beyond t_ol, T_max, INA228 loss, BMS-trip signature | PSU regulation fault, sensor faults, a pack that skipped the P20 | firmware logic error, hang | T4, T6–T8, T14 |
| L3 | ESP32 watchdog reset → GPIO4 high-impedance → the #2814's on-board R4 + R5 → OFF | CPU hang | logic error that keeps the loop alive | T3 |
| L4 | *Withdrawn in rev 0.3.* It was INA228 BOVL → ALERT → Dx → ON low. BOVL and the ALERT latch are registers the firmware writes at boot, and an INA228 power-on reset returns them to defaults, so L4 was armed only by the firmware it backed up. L2 (gated by T4 on every firmware edit), L6 and L7 stand behind the same fault | — | — | — |
| L5 | `restore_mode: ALWAYS_OFF` | auto-resume after a blip or reboot | — | T9 |
| L6 | AC **countdown timer** (standalone, no network) | everything electronic, **including a #2814 failed short** | nothing inside its time | T12 |
| L7 | The pack's own BMS (OVP/OCP) | last resort | — | not tested (inside the pack) |
| L8 | Battery-end fuse (§6) | battery-fed faults in the lead or enclosure | over-charge (a fuse is not a limiter) | continuity only |

Pololu's own caveat: *"Do not use this switch as an emergency cutoff or similar safety disconnect in applications where failure to cut power could lead to injury or property damage."* [S, Pololu #2814 page]. MOSFETs usually fail shorted. **The #2814 is the operational stop; L6 and L7 are the safety layers.** L6 ends everything only because the ideal diode stops the pack keeping the board alive (§5).

**Not watched (rev 0.5): the pack's temperature.** With the DS18B20 dropped, a cell heating during the hold is bounded only by T_hold/T_max (FW-6, FW-4), L6 and L7. Accepted with RQ-9/RQ-11's siting.

---

## 9. Firmware requirements (new firmware; not written)

This is a new, small configuration, **not** `battery-bank-monitor.yaml`. It is gated by the `esp-firmware-validation` skill (real compile, `src/main.cpp.o` 0 errors), compiled on the Device Builder add-on's ESPHome version.

**States:** IDLE → CHARGING → DONE | FAULT(reason). DONE and FAULT are latched until acknowledged.

| ID | Requirement |
|---|---|
| FW-1 | Enable switch on GPIO4, `restore_mode: ALWAYS_OFF`, **`drive_strength: 5mA`**. Only the state machine drives it. ON needs 0.17 mA [D: 3.3 V ÷ 20 kΩ], so the weakest setting drives it fully and pushes less into a swapped or shorted control wire. The options are 5, 10, 20 (default) and 40 mA on esp-idf [S, esphome.io pin schema], which the bank firmware already uses. The 5 mA is ESPHome's nominal label; the datasheet characterises only the 40 mA setting [S, Table 14], so the dead-short current is [I] |
| FW-2 | *Withdrawn in rev 0.3* (profile select; bank deferred) |
| FW-3 | Start preconditions: VBUS (switch open) > 10.0 V (Cyclenbatt BMS UVP [[supplemental-analysis.md](../docs/supplemental-analysis.md)]) and **< V_hold**; no latched fault. A reversed or absent pack reads ≤ 10.0 V and is refused. **Why V_hold, not 14.60 V (rev 0.5):** the pack arrives from the P20's 14.6 V absorb [listing] resting above V_hold. Started there, the diode blocks (I = 0) while VBUS ≥ V_hold, and FW-6 would count the pack's own relaxation as time at voltage, so a session could reach DONE having delivered nothing. Counting time only while I > 0 would not fix it: a balanced pack with no balancer legitimately decays toward 0. **Write the test so NaN refuses:** `v > 10.0 && v < V_hold`, never `!(v <= 10.0)` |
| FW-4 | **Hard stops** (any one → switch OFF, FAULT latched): **raw VBUS > 14.60 V** on one averaged sample; I > I_max = 5.0 A (RQ-1); **I > 2.0 A for longer than t_ol → FAULT "overload: pack not pre-charged"** (RQ-12; 2.0 A is the PSU's rated current [S, HDR-30-SPEC p.2], t_ol from T11); session time > T_max; INA228 read failure or NaN on **one** read. **N = 1 (rev 0.5):** §1 clause 2 allows one sample period unobserved, and a missed read is that period; a glitch costs a session, the same safe-direction trade §9 accepts for false trips. The overload stop also enforces §10.1: a pack that skipped the P20 is refused within t_ol instead of holding the PSU in overload |
| FW-5 | **BMS-trip signature:** current falls from charging to ~0 within one sample while VBUS sits at the source voltage → OFF, FAULT "BMS trip", and publish the **raw VBUS and I of the last sample before the step** (V_batt is computed downstream, §6.4). A plain "at voltage and I < tail" rule would read this as "full". This is the first per-cell evidence the sealed pack can give. With a per-cell cutoff V_ovp, a trip at V_batt puts the other three cells at an average of (V_batt − V_ovp)/3 [D]. V_ovp is undocumented for this pack (O7), so the figure stays a formula. **A blown fuse or a QD pulled off gives the same signature**: check continuity before reading it as a BMS trip. If the pack is uneven, session 1 may end here rather than in DONE. That is a designed-for outcome, not a failure. **Thresholds (rev 0.5):** "charging" and "~0" have no values yet. At the tail the step is at most the tail current, so both are set from T11 (O5). Resolution is not the limit: 20.8 µA per shunt LSB [D: 312.5 nV ÷ 0.015 Ω] |
| FW-6 | **Normal end: time at voltage.** Accumulate time with VBUS ≥ V_hold; at T_hold → OFF, DONE. **Log the current throughout and do not act on it.** A taper rule (I < I_tail) could fail to fire precisely when a balancer is bleeding and holding the current up (§2), ending a working session as a T_max FAULT. V_hold, T_hold and T_max are **TBD from T11**. T_hold is bounded by how long the owner accepts the host running with no backup (§10.2) |
| FW-7 | **V_SET = 14.40 V**, inside the Cyclenbatt's 14.4–14.6 V (RQ-10). Dropping the bank removed rev 0.2's reason (the bank's 14.58 V peak), but 14.40 V stays: it is the bottom of RQ-10, and the whole window to the 14.60 V ceiling is the false-trip margin (below). It sits below the P20's 14.6 V absorb [listing], so the hold adds time at balancing voltage, not a further push |
| FW-8 | Sampling ≥ 1 Hz while charging. INA228 averaging window ≥ one 120 Hz ripple period (8.3 ms [D: 1 ÷ 120 Hz]); one conversion cycle is "one sample period" for §1 clause 2. **ESPHome's defaults miss this (rev 0.5):** its INA2xx driver always converts bus, shunt and die temperature (MODE 0x0F [M, source read, ESPHome 2026.8.2 `ina2xx_base.cpp:344`]), and its defaults of 4120 µs × 128 averages give a 1,582 ms cycle [D: 3 × 4.120 ms × 128]; the bank firmware logged the same ~1.58 s cycle in V1.12. FW-10 pins the settings. Termination and stops are local; HA is not in the loop. **`reboot_timeout: 0s` on both `api:` and `wifi:`** (both default to 15 min [S, esphome.io `api` and `wifi` component pages, read 2026-09-21]): a mid-session reboot is safe (FW-1) but discards the session's Ah count, the Open Item 16 measurement. Because ESPHome notes that a full reboot is sometimes needed to recover Wi-Fi [S, `wifi` page], add an interval check that reboots after 15 min without an API client **only while IDLE** |
| FW-9 | Publish to HA: raw VBUS, I, P, Ah this session, time at voltage, state, fault reason, the INA228 die temperature (enclosure; report-only), FW-5's pre-step VBUS and I, and FW-12's edge values. **No V_batt and no R_series in firmware** (rev 0.5, §6.4). **Session Ah is the INA228's hardware CHARGE register**, not a sum in a lambda (R10): ESPHome publishes it (`charge:`, INA228/229 only) and `reset_energy_counters()` zeroes it at Start [M, source read, ESPHome 2026.8.2 `ina2xx_base/__init__.py:74`, `ina2xx_base.cpp:237`]. An INA228 power-on reset also clears it, but that reset ends the session anyway (FW-1). Hold session Ah, FW-5's pre-step VBUS and I, and the end reason in `restore_value` globals, written once at DONE/FAULT, so a later reboot does not lose them. Controls: Start/Stop, fault acknowledge |
| FW-10 | INA228 at boot: shunt 0.015 Ω; ADC range ±163.84 mV; **`adc_time: 1052us`, `adc_averaging: 64`** → 67.3 ms per channel [D: 1.052 ms × 64], above FW-8's 8.3 ms, and a 202 ms cycle [D: 3 × 67.3 ms], inside FW-8's 1 s. Both are valid settings [S, TI INA228 datasheet SLYS021A pp.23–24]. Publish `temperature:` (the die): ±1 °C max at 25 °C, ±2 °C max over −40…+125 °C [S, SLYS021A p.6]. It reads the breakout, which carries the 15 mΩ shunt (0.199 W at 3.64 A [D: 3.64² × 0.015]), so it runs above the enclosure air while current is high [I; falsifier: in T0 it does not move with current]. The XIAO's own sensor is not used: Espressif gives it no accuracy figure and says it reads "higher than the operating ambient" [S, ESP32-C3 datasheet v1.2 §3.3.2 p.19]. No BOVL or ALERT configuration (L4 withdrawn) |
| FW-11 | **Status LED (GPIO3, XIAO D1; active-high, through R1 1 kΩ; §5.5)**, the only local indicator when Wi-Fi is down. IDLE: one short blink every 3 s. CHARGING: 500 ms on / 500 ms off; a hung CPU freezes it on or off. DONE: two short blinks every 3 s. FAULT: 4 Hz |
| FW-12 | **Edge resistance, both switch edges, every session (rev 0.5).** In the same loop pass, capture VBUS and I from the last sample before the edge and from the first full conversion after it (discard the conversion that straddles the edge), and publish both pairs. R_edge = ΔVBUS ÷ ΔI = R_series + the pack's ohmic resistance + whatever polarisation relaxes within one conversion [I; falsifier: session-to-session scatter too large to trend]. Computed downstream, not in firmware. **The pairing must be done here:** HA writes VBUS and I to InfluxDB as separate state changes with their own timestamps, the problem UPS firmware V1.20's paired V/I blocks fixed (UPS Open Item 21). The ON edge carries the session's largest current; the OFF edge carries the tail. Both happen on a full pack indoors, so conditions repeat session to session. Hold FW-10's conversion settings fixed, or the trend breaks |

**Voltage ceiling: 14.60 V on raw VBUS, not on compensated V_batt.**

- **Why raw VBUS is never later.** Charge current flows from VBUS through the shunt and lead into the pack, so V_batt = VBUS − I·R_series. The ideal diode holds I ≥ 0 (§5), so V_batt ≤ VBUS: whenever V_batt exceeds the ceiling, VBUS already has.
- **Why compensation would be worse.** A compensated trip with R_series set too high would read low and fire late, which is the unsafe direction. Tripping on raw VBUS takes a hand-measured constant out of the safety path.
- **False trips are possible and are safe-direction.** In normal operation VBUS ≤ the PSU output, which the datasheet bounds at 14.40 V + 144 mV tolerance + 108 mV drift + 60 mV ripple peak = **14.712 V worst case** [D, §4.1, for an assumed 25 °C rise]. That is above the 14.60 V ceiling. A false trip stops the charge and latches FAULT: it costs a session, not safety. Near the end of charge the current is small, so a compensated trip would have the same exposure.
- **How the margin is established.** T0 measures the real unit warm, T4's no-trip direction runs a full warm session, and FW-8's averaging removes ripple. T0 also logs the INA228 die temperature, which replaces the assumed 25 °C rise with a measured one: the temperature coefficient is specified against ambient, 0–50 °C [S, HDR-30-SPEC p.2].

---

## 10. Procedures

### 10.1 Every session

1. **Remove the pack from the UPS by OP-1**: battery last-off, first-on; EN jumpered low across any battery connection [[boost-subsystem-design.md](../UPS-Monitor/boost-subsystem-design.md) §9]. From this point the host has no backup.
2. **Charge it to full on the P20** (§4.3): LiFePO4 mode, **5 A** (RQ-1). The P20 does not turn off: when it reaches trickle, disconnect it.
3. Countdown timer **OFF** (AC dead).
4. **Polarity check, then connect:** read the pack's + and − markings, then push the **black** QD onto **−** and the **red** (fused) QD onto **+**. Re-read both before step 5 (RQ-6).
5. Set the timer to T_max plus a margin, and switch it on. The board boots with the switch **OFF**, and the LED shows IDLE.
6. In HA or on the ESPHome web page, check VBUS. Fresh off the P20 the pack rests above V_hold, and FW-3 refuses Start until it falls below V_hold (and at or below 10.0 V). Wait for it, then press **Start**.
7. The session ends by itself (DONE or FAULT). Then set the timer **OFF** and remove the red QD, then the black.

### 10.2 Returning the pack to the UPS (RQ-7)

- **Before reconnecting**, read the pack's rest voltage. A freshly topped pack rests above the 13.3 V float [I]. Bleed it to ≤ 13.3 V so the bus stays inside the XB7's validated envelope. Falsifier: the UPS INA260 bus reading right after reconnection. **The bleed load and method are not yet named (O8).**
- Reinstall by OP-1.
- The P20 and this charger are used indoors, in conditioned space (RQ-9, RQ-11). No sensor checks it.
- **Success measure:** the matched-load LVD-to-LVD capacity test, before and after (UPS Open Item 14a).
- The host has no backup from step 1 of §10.1 until reinstall, which now spans the P20 charge, the rest before Start and the hold. T_hold (FW-6) trades balancing time against that window. **That trade is the owner's call.**

### 10.3 Bank

*Withdrawn in rev 0.3*; the bank is deferred (§2).

---

## 11. Commissioning tests — both directions (R2 / R7)

Run T1–T9 and T14 on a **resistive load, no battery**: **10 Ω, ≥ 25 W**, 1.44 A at 14.4 V [D: 14.4 V ÷ 10 Ω], 20.7 W [D: 14.4² ÷ 10], inside the PSU's 2.0 A rating (RQ-12). Each fault test must **fire**, and the clean run must stay **silent**. In every test, the LED pattern must match the state (FW-11).

> **Correction record (R13), 2026-09-22.** Rev 0.4 specified a 5 Ω load, which draws 2.88 A [D: 14.4 V ÷ 5 Ω], above the PSU's 2.0 A rated current [S, HDR-30-SPEC p.2]. Every commissioning test would have run the PSU in its overload fault mode, and if the unit's limit sat below 2.88 A, T0 would have measured a current-limited VBUS instead of the regulation margin. Found while writing RQ-12.

| # | Inject | Must | Silent direction |
|---|---|---|---|
| T0 | — | Trim V_SET = 14.40 V at the PSU terminals, output open, cold. Run the resistive load 30 min with the box closed; log the highest averaged VBUS. Stop, and within 1 min re-read the PSU output open-circuit. **Record the margin, 14.60 V − highest VBUS [M]**, and the INA228 die temperature's rise over the run (§9). If it is under 60 mV [D, ripple peak §4.1], stop: RQ-10 leaves no room to move either number. Lacquer the trimpot | — |
| T1 | Power up with the XIAO **removed** from its socket | Load current 0; ON < 1 V | — |
| T2 | Hold RESET; reflash OTA; power-cycle | ON < 1 V throughout (scope the ON node) | Commanded ON conducts |
| T3 | Test build: infinite loop in a lambda while charging | Watchdog reset → OFF | Normal build runs a full session |
| T4 | Test build: ceiling below V_SET | OFF, FAULT "over-voltage" | Production ceiling (14.60 V): a full **warm** session on the load with no trip |
| T5 | *Withdrawn in rev 0.3* (L4) | — | — |
| T6 | Test build: I_max below the load current | OFF, FAULT "over-current" | — |
| T7 | **Rev 0.6:** mid-session, hold SDA to GND with a clip lead from U2's SDA pin (pin 4) to a GND point. Then, **AC off**, remove the INA228, power up, and press Start | OFF, FAULT "sensor"; Start refused (NaN, FW-3), with ON < 1 V at U4 pin 1 | — |
| T8 | Test build: T_max = 1 min | OFF at 1 min | — |
| T9 | Pull AC mid-session, then restore | Stays OFF | — |
| T10 | On the pack, at a steady known current | DMM at the pack terminals vs VBUS → **R_series** (analysis only: V_batt downstream, and FW-12's split, §6.4). Also, at the solder joints on the underside (R13: not the screws), mV from TB2-2's pin to U2's socket pin 2: ≤ ~0.11 mV at 2.0 A, and more than 0.5 mV falsifies; and from TB2-2's pin to TB1-1's pin: 3.1–3.4 mV, and more than 5 mV falsifies (§7.3) | — |
| T11 | First **supervised** session, on a pack fresh off the P20 | Log the current at 14.40 V (the balancer question, §2); set V_hold, T_hold, T_max, t_ol (how long the opening current stays above 2.0 A) and FW-5's thresholds; note how long the pack takes to rest below V_hold. Session 1 may end in an FW-5 trip | — |
| T12 | Let the countdown timer expire mid-session | Everything dark: LED off, pack current 0. This proves the ideal diode stops the pack keeping the board alive (§5) | — |
| T13 | *Withdrawn in rev 0.5* (DS18B20 dropped) | — | — |
| T14 | Test build: overload threshold below the load current | OFF after t_ol, FAULT "overload" | Production threshold (2.0 A) on the 10 Ω load: a full session, no trip |

Any firmware edit re-runs T1–T4, T6–T9 and T14 (R7: a gate untested against a known-bad input is not a gate).

**Why T7 changed in rev 0.6.** On the board, the INA228 is in the charge path: VIN+ and VIN− pass through its socket contacts 7 and 6 (§6.4). Unplugging it mid-session would break up to 3.64 A at a socket contact. It would also end the charge by opening the path, so the test could pass without the firmware doing anything. And it would tilt a module carrying ~14 V on pin 7 beside SDA and SCL on pins 4 and 3. Holding SDA low produces the same I2C read failure without touching the power path [I: the ESP32's I2C pins are open-drain, so the short fights only the breakout's pull-ups]. **Never unplug U2 with AC on.**

---
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

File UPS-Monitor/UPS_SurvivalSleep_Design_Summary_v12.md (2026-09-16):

# UPS Monitor — Survival Sleep Feature Design Summary

## Engineering Basis Document v12

**Document scope:** Power budget, timing, entry/exit logic, data-integrity, and
implementation rationale for the ESP32-C3 survival sleep feature on the DIY
LiFePO4 UPS Monitor, as built on the **UPS-Monitor-THT Rev 1** carrier PCB.

**Date:** June 2026
**Revision:** v12 — **Tracks firmware through V1.14.** Builds on the v10 pre-sign-off
fixes (FIX 1, FIX 2) and the v11/V1.13 config simplification, and adds the items
surfaced by the V1.13 pre-deployment review pass. Per the code-review standard, all
v12 items were caught *during review, before sign-off*; none changes the validated
survival entry/exit thresholds or decision logic.

> **Currency note (2026-09-16).** This document tracks firmware **through V1.14**;
> the deployed firmware is **V1.20**. Revisions V1.15–V1.20 are recorded in the
> header changelog of `ups-monitor.yaml`, not here. One of them alters a mechanism
> this document describes as current, and is noted at its sites: **V1.20 replaced
> the per-channel `throttle_average: 5s` filters with a paired V/I block
> accumulator** (§2.3 "Data path", §9.6). Everything else below is as of V1.14 —
> check the firmware header before relying on a detail added after that version.
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

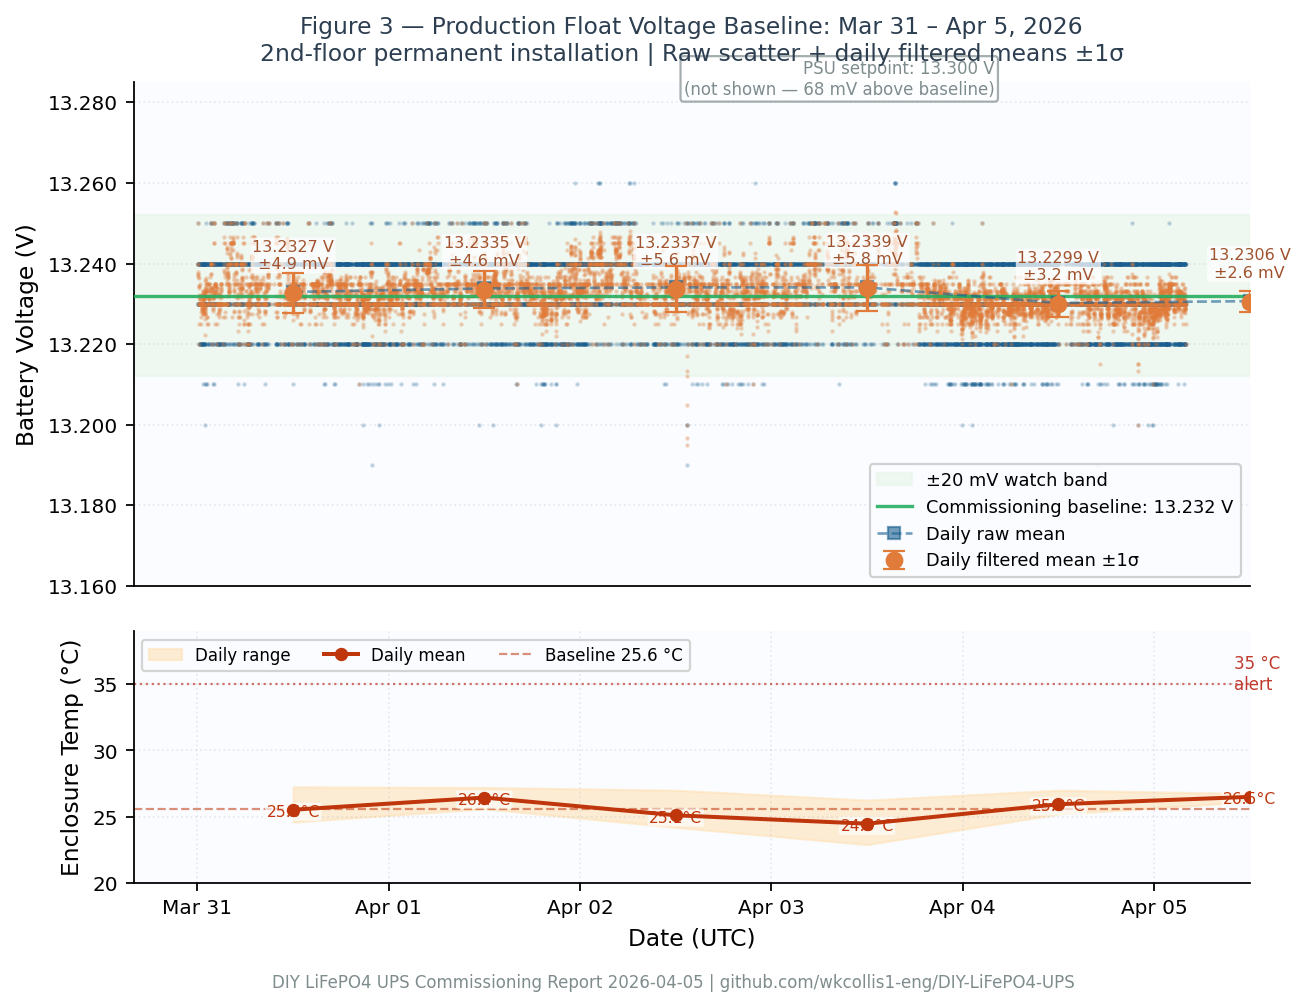
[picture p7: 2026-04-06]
assets/fig_float_baseline_apr05.png

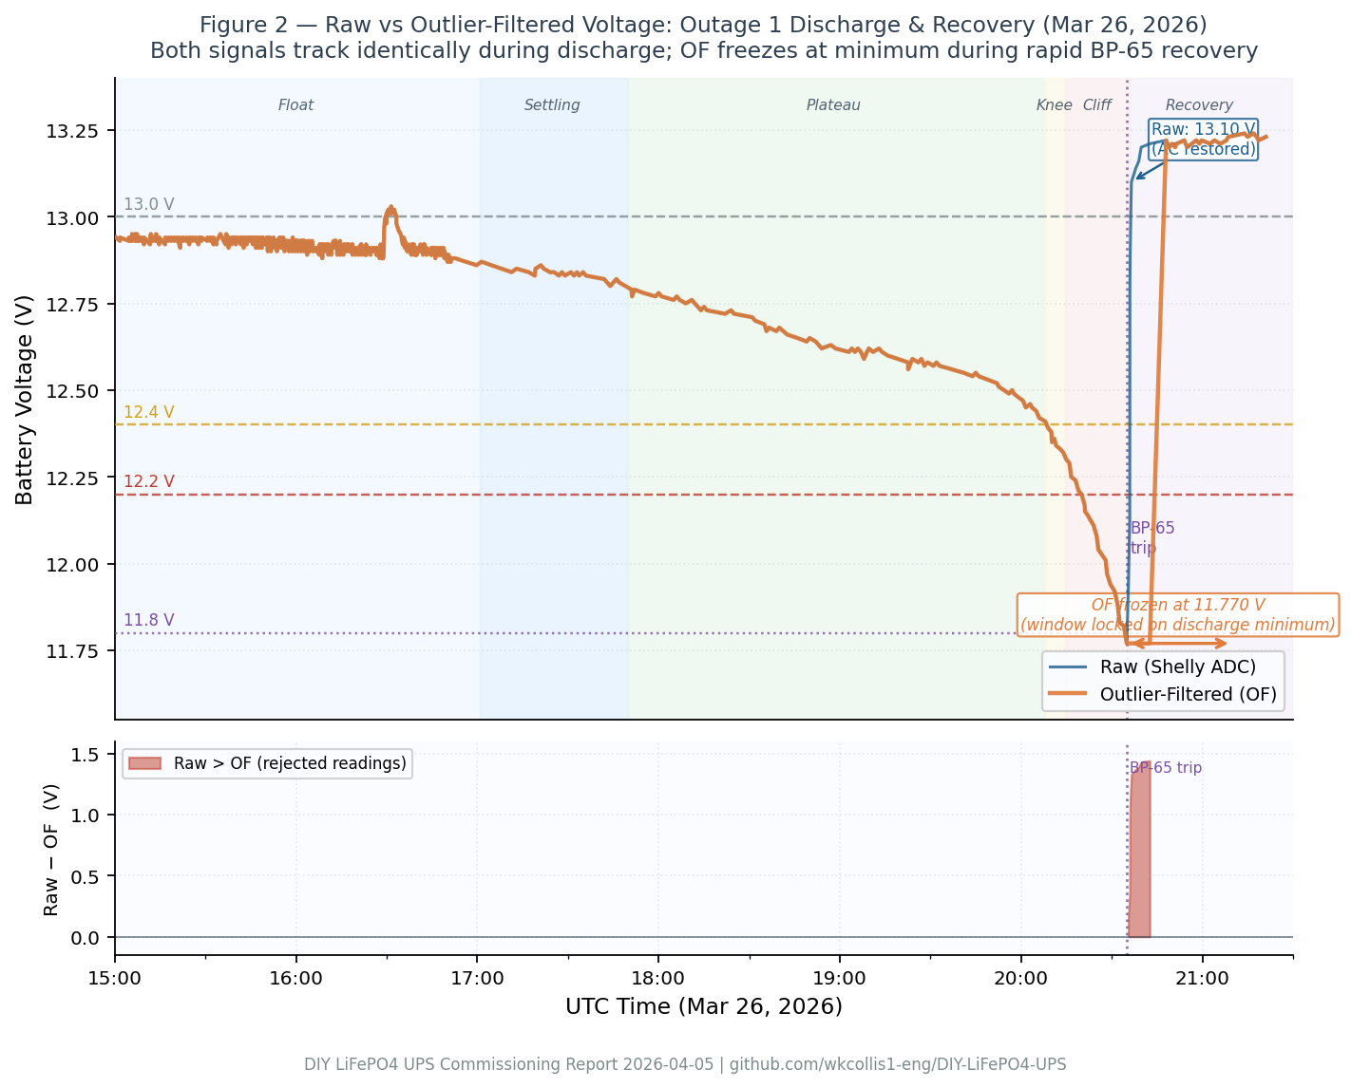
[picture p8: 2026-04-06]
assets/fig_filtered_vs_raw_apr05.png

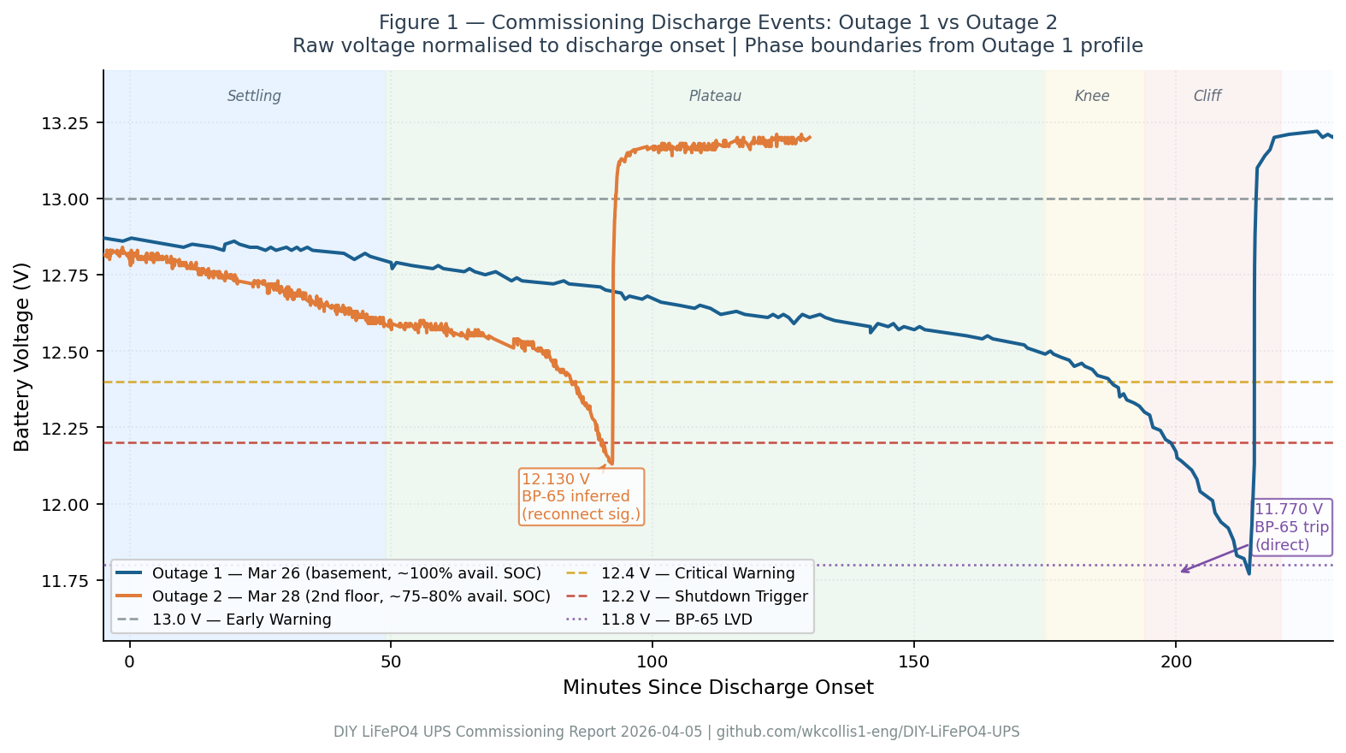
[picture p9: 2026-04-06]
assets/fig_discharge_comparison_apr05.png

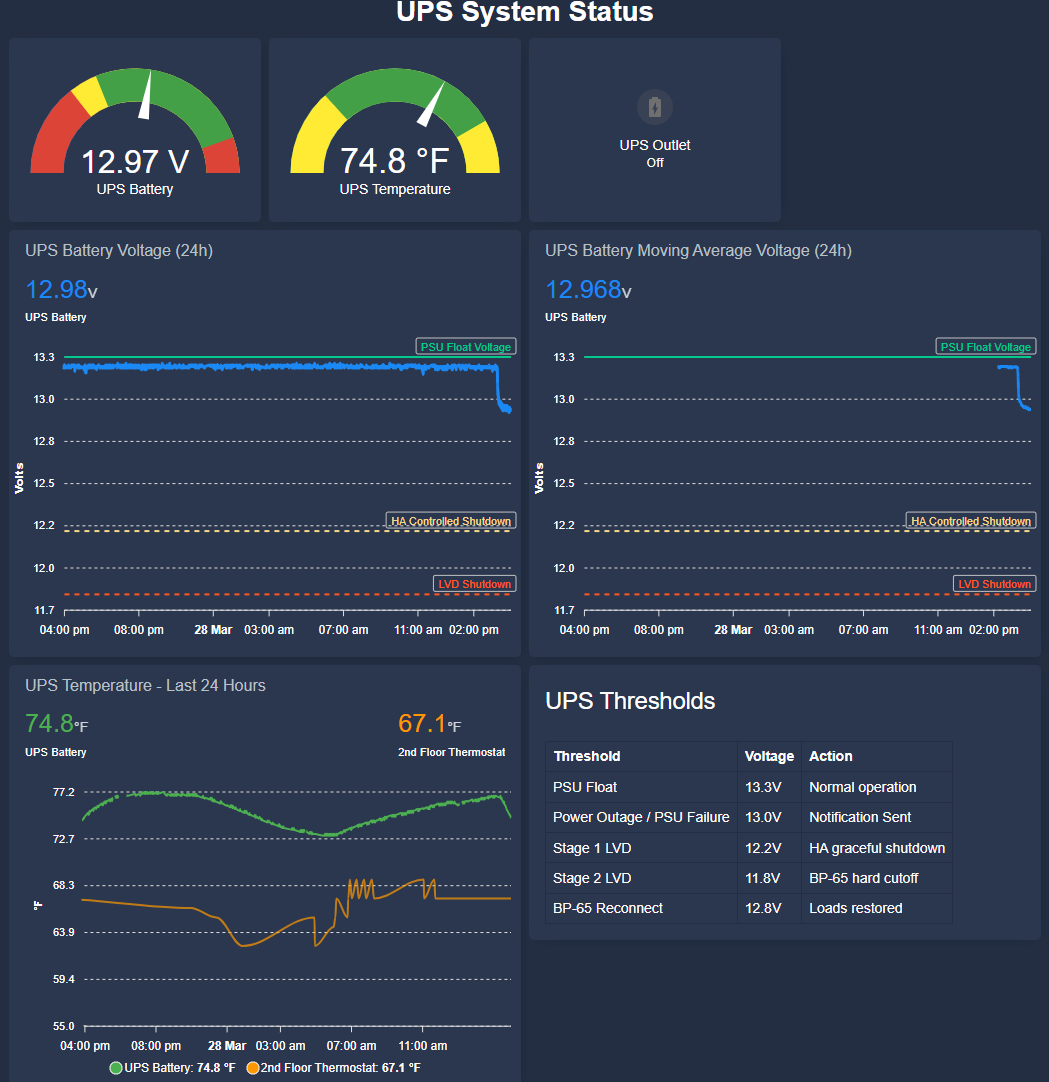
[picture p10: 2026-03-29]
assets/HA_UPS_Dashboard.png

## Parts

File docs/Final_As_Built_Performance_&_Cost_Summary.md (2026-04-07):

***

# Final As-Built Performance & Cost Summary
**Project:** DIY LiFePO4 UPS
**Date:** March 2026
**Status:** Validated & Deployed

## Executive Summary
Following 25+ hours of continuous full-load operation in its permanent 2nd-floor location, the DIY LiFePO4 UPS has been fully validated. The system currently supports an Xfinity XB7 modem and a Home Assistant Green hub. All thermal, electrical, and efficiency metrics align precisely with the original engineering models.

---

## 1. Performance Results
*Measured over 25h 5m of continuous operation (Kill-a-Watt, final configuration: PSU → Kasa HS103 → Kill-a-Watt).*

| Metric | Value |
| :--- | :--- |
| **Average AC Wall Draw** | 17.90 W |
| **Peak AC Wall Draw** | 29.3 W (Includes Kasa HS103 in measurement chain) |
| **Derived DC Load** | ~14.4 W (Typical) |
| **PSU Terminal Voltage** | 13.3 V (Set) |
| **Battery Terminal Voltage** | 13.23 – 13.27 V (Avg: 13.25 V) |
| **Battery Temperature** | 72–77 °F (8–10 °F above ambient) |

### Comparison to Original Specification

| Parameter | Original Spec | As-Built Performance | Status |
| :--- | :--- | :--- | :--- |
| Typical AC Wall Power | 16.0 W | 17.90 W | Matches thermal model |
| Peak AC Wall Power | 23.0 W | 29.3 W | Acceptable¹ |
| Typical DC Load | 14.5 W | ~14.4 W | **Excellent match** |
| Float Voltage (PSU) | 13.3 V | 13.3 V | **Exact setpoint** |
| Battery Voltage (Float) | 13.24 V | 13.25 V (Avg) | **Exact match** |
| Expected Runtime | ~7.8 Hours | ~8.0 – 8.3 Hours | **Exceeds target** |

> ¹ *Final measurement configuration: PSU plugged into Kasa HS103, Kasa into Kill-a-Watt. Peak of 29.3 W includes Kasa HS103 idle overhead (~0.5 W) and XB7 spike events. The Mean Well HDR-60-12 and DC-side components see a lower peak (~21–22 W AC equivalent), well within safety ratings.*

---

## 2. Engineering Notes
*   **Voltage Regulation:** The voltage drop from 13.3 V (PSU) to 13.25 V (Battery) confirms a total path resistance of ~50 mΩ, validating the `voltage-drop-analysis.md` calculations.
*   **Thermal Margin:** Thermal performance remains excellent, maintaining a buffer of ~27–32 °F below the 40 °C (104 °F) DS18B20 alert threshold.
*   **Switchover Efficiency:** Confirmed seamless transition; zero reset events on the XB7 or Home Assistant Green during testing.
*   **HA Shutdown Automation:** Validated against actual discharge data (2026-03-26). Outlier filter radius set to 0.10 V; trigger duration 1 minute. Total automation chain 2.5 min; margin before BP-65 hardware LVD ~18 min at 15 W actual load.

---

## 3. Cost Analysis

### Actual Build Cost
*   **Total Investment:** $223.88
*   **Effective Hardware Cost:** ~$211.00 (excluding one-time tools)

### Annual Operating Cost Comparison
| System Configuration | Annual Cost | Notes |
| :--- | :--- | :--- |
| Standard AC Adapters (No UPS) | $41 /yr | 16.0 W base load |
| **DIY LiFePO4 UPS** | **$46 /yr** | **17.90 W (As-built)** |
| APC BE600M1 | $52 /yr | Estimated efficiency loss |
| APC BX1500M | $64 /yr | Higher idle power draw |

---

## 4. 10-Year Lifecycle Cost Comparison

| Metric | DIY LiFePO4 UPS | Standard AC Adapters | APC BE600M1 | APC BX1500M |
| :--- | :--- | :--- | :--- | :--- |
| **Initial Cost** | $224 | $0 | $85 | $180 |
| **Battery Repl.** | $30 (1x) | — | $60–90 | $100–150 |
| **Electricity** | $460 | $410 | $520 | $640 |
| **10-Year Total** | **~$714** | **~$410** | **~$665–695** | **~$920–970** |

---

## 5. Value Proposition
The DIY UPS represents a **$304 premium over 10 years** compared to unprotected power; this is the **cost of redundancy**. For this investment, the system delivers:
*   **High Performance:** 3× longer runtime than a comparable APC BE600M1.
*   **Instantaneous Response:** <1 ms switchover (10× faster than typical consumer standby UPS).
*   **Longevity:** 10–20 year battery service life vs. 2–3 years for Lead-Acid (SLA) equivalents.
*   **Intelligence:** Integrated Kasa HS103 enables smart switching and remote power monitoring.

## Conclusion
The as-built system performs exactly as designed. Voltage regulation and thermal margins are well within engineered parameters. The UPS is cleared for long-term service, providing approximately 8 hours of reliable, seamless backup for the home network infrastructure at a competitive lifecycle cost.

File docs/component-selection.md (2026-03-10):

# Component Selection Rationale

---

## Mean Well HDR-60-12 Power Supply

Selected for its adjustable voltage range and efficiency characteristics:

- Adjustable voltage range (10.2–13.8V) enables precise 13.3V float setting
- 13.3V float operates 1.3V below BMS OVP trip point (14.4–14.6V) for safe margin
- 87% efficiency at 25% load vs 79% for LRS-100-12 at comparable loading
- MTBF 927,600 hrs — 37% higher than LRS-100-12
- Class II design (double-insulated) appropriate for ABS enclosure with no metal surfaces
- DIN rail mount capability, compact form factor
- OVP range of 13.8–16.2V provides a hard ceiling above the 13.3V float setpoint

At the 14.5W DC typical system load (~1.2A), the PSU operates at approximately 26% of its 4.5A rated capacity. Light loading reduces thermal stress and extends service life.

---

## Cyclenbatt 12V 10Ah LiFePO4 Battery

LiFePO4 chemistry selected over SLA for:

- Thermal stability: thermal runaway threshold above 270°C, non-flammable under normal conditions
- Cycle life: rated 5000+ cycles vs. 200–500 for SLA
- Calendar life: 10–20 years expected at 13.3V float and 63–75°F (1–2%/yr calendar aging) vs. 2–3 years for SLA at conventional float voltage
- Weight: approximately 40% lighter than equivalent SLA

Built-in 10A BMS provides cell-level over-voltage (14.4–14.6V), under-voltage (10.0V), and overcurrent protection as a secondary layer behind the system-level protections.

The 10Ah capacity provides approximately 7.8 hours runtime at the measured 14.5W DC combined load (Kill-a-Watt confirmed, 16.0W AC avg with adapter losses removed).

---

## Pololu Ideal Diode (4-60V, 10A) — Pololu #5382

A MOSFET-based ideal diode rather than a conventional Schottky diode eliminates the 0.6–0.7V forward voltage drop that would otherwise reduce the PSU-to-battery charging voltage. The MOSFET approach has approximately 5mΩ effective resistance at operating current — contributing only ~5mV drop at 1A vs. 600–700mV for a Schottky.

Function: blocks reverse current from battery to PSU during AC failure. Without this, the battery would attempt to back-power the PSU through its output terminals (PSU has no reverse protection).

10A rating provides 8× margin over 1.2A typical load (5× over 2A worst-case design current). Two units purchased; one installed, one spare.

---

## Victron BatteryProtect BP-65 (LVD)

See [design-rationale.md](design-rationale.md) for the relay module comparison.

Key specifications relevant to this installation:

- Setting 7: 11.8V disconnect / 12.8V reconnect — appropriate for LiFePO4 at this load level
- MOSFET Rds(on): ~3mΩ typical (community-validated; not published in datasheet)
- 90-second disconnect delay: prevents LVD trip on brief voltage sag from inrush or transient load; adds only ~0.02V additional drop during delay — negligible
- Over voltage protection: load disconnected if input exceeds 16.3V (12V system)
- Current consumption: 1.5mA with BLE on — negligible impact on battery runtime (0.018W parasitic)
- Bluetooth programming via VictronConnect app; thresholds are user-defined (not just preset table values)
- IP67 potted electronics, no calibration drift
- 5-year warranty

---

## DC-DC Converter — Design Decision (Not Purchased)

Originally specified: Mean Well DDR-60G-12 DC-DC converter. After analysis, this was dropped:

- HA Green and XB7 modem accept industry-standard ±10% on 12V rail
- Eliminated DDR-60G-12 saves $33.80 + 2.8W continuous loss (~$5/year electricity savings)
- Design is more reliable and efficient without it

---

## Shelly Plus Uni

Provides native Home Assistant integration via WiFi with no ESPHome coding required. Two analog inputs (ADC) and DS18B20 1-Wire temperature sensor support in a single module.

Pin 3 (Analog In) bridged to Pin 1 (V+) provides direct battery voltage sense — used as the primary low-battery warning trigger at 12.2V, giving Home Assistant time to initiate graceful HA Green shutdown before the Victron BP-65 LVD cutoff at 11.8V (approximately 15–20 minutes of runtime remaining).

The DS18B20 sensor is placed on the battery surface and provides temperature telemetry with a 40°C HA alert threshold.

Update rates: voltage every 5 seconds, temperature every 30 seconds. Power consumption: 0.5W in eco mode.

---

## LeMotech Junction Box

IP65-rated ABS enclosure with flame-retardant rating (UL94 fire safety standards). The 9.6″×7.6″×4.5″ interior provides adequate space for all components with room for cable management. Rubber gasket seal on lid. Pre-punched knockouts accept the 1/2" NPT cable glands.

ABS self-extinguishing rating is appropriate for an enclosure containing a lithium battery and 120VAC wiring — significantly safer than basic polypropylene storage containers. Six ¼″ ventilation holes have been drilled (3 intake low on PSU wall, 3 exhaust high on BP-65 wall). Thermal analysis confirms the holes contribute negligible active cooling (~0.05W, ~1.5% of total load) at the ~3.5W heat dissipation level — wall conduction dominates. The holes provide pressure equalization during thermal cycling. Note: the drilled holes reduce the enclosure rating from IP65 to approximately IP4X (splash-resistant; no longer water-jet resistant). This is a non-issue for an indoor floor installation.

Physical AC/DC segregation: PSU (AC input side) is mounted on the left; battery, BP-65, and DC components occupy the center and right. AC and DC cable glands are on opposite sides of the bottom face.

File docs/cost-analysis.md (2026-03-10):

# Cost Analysis

---

## Actual Build Cost

| Category | Cost | % of Total |
|---|---|---|
| Main Power Components (PSU, Battery, BP-65, Ideal Diode) | $100.63 | 45.0% |
| Monitoring & Control (Shelly, DS18B20) | $23.47 | 10.5% |
| Protection & Wiring | $44.94 | 19.7% |
| Enclosure & Hardware | $32.83 | 14.6% |
| Tools | $12.73 | 5.7% |
| Pololu Shipping | $6.45 | 2.9% |
| Amazon Cash Back (5%) | −$10.21 | — |
| Sales Tax | $13.98 | 6.2% |
| **TOTAL** | **$223.88** | 100% |

> Tools ($12.73) are one-time costs not specific to this project. Excluding tools, effective build cost is ~$211.

---

## Why Build This?

This project costs more up-front than a commercial UPS. The value proposition is **not** cost savings — it's technical capability:

| Capability | This DIY UPS | Commercial SLA UPS |
|---|---|---|
| **Switchover time** | <1ms (imperceptible) | 4–10ms (can cause modem reboots) |
| **Runtime @ 14.5W DC load** | ~7.8 hours | 2–2.5 hours |
| **Battery lifespan** | 10–20 years | 2–3 years |
| **Home Assistant integration** | Native (voltage, temp, SoC, runtime) | None or proprietary software |

Build this if you want seamless switchover, extended runtime, or native HA monitoring. Don't build this expecting significant cost savings.

---

## Annual Operating Cost

| Option | Wall Draw | Annual kWh | Annual Cost |
|---|---|---|---|
| Bare wall warts (OEM adapters, no UPS) | 16.0W measured | 140 kWh | ~$41/yr |
| This DIY UPS (DC load through HDR-60-12 at ~81% efficiency) | ~17.9W | 157 kWh | ~$46/yr |
| APC BE600M1 (SLA, Line-Interactive) | ~20W estimated | 175 kWh | ~$52/yr |
| APC BX1500M | ~25W estimated | 219 kWh | ~$64/yr |

> Wall wart baseline measured via Kill-a-Watt: 2.538 kWh over 158.8 hours (6 days 14h 50min) = 16.0W average, confirmed stable across three independent combined measurement windows. XB7 OEM adapter DoE Level VI (≥88% efficiency, model NBC56B120460VU). The DIY UPS adds only ~$5/yr vs running devices on bare wall warts — UPS capability is essentially free to operate compared to doing nothing. Commercial alternatives cost $6–18/yr more to run.

---

## 10-Year Lifecycle Cost Comparison

| Metric | This DIY UPS | Bare Wall Warts | APC BE600M1 | APC BX1500M |
|---|---|---|---|---|
| Initial Cost | $224 | $0 | $85 | $180 |
| Battery Replacement (10yr) | $30 (1×) | — | $60–90 (2–3×) | $100–150 (2–3×) |
| Annual Electricity | $46/yr ($460) | $41/yr ($410) | $52/yr ($520) | $64/yr ($640) |
| **10-Year Grand Total** | **~$714** | **~$410** | **~$665–695** | **~$920–970** |

The DIY UPS costs ~$304 more over 10 years than running bare wall warts — this is the cost of UPS capability. It costs roughly the same as the APC BE600M1 over 10 years while delivering 3× more runtime (7.8h vs 2–3h), 10× faster switchover, and 5× longer battery life.

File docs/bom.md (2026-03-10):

# Bill of Materials

All prices as-purchased (March 2026). Amazon prices subject to change; Pololu prices are typically stable.

---

## Main Power Components

| Item | Vendor | Unit Price | Notes |
|---|---|---|---|
| Mean Well HDR-60-12 PSU | Amazon | $26.53 | Incl. $2.40 shipping. 4.5A/54W, 88% peak eff. (~87% at 22% operating load), OVP 13.8–16.2V |
| Cyclenbatt 12V 10Ah LiFePO4 Battery | Amazon | $29.99 | Built-in 10A BMS, 5000+ cycles, F2 spade terminals |
| Victron BatteryProtect BP-65 12/24V | Amazon | $36.53 | LVD: Setting 7 = 11.8V cutoff / 12.8V reconnect. MOSFET, IP67, 5-yr warranty |
| Ideal Diode 4-60V 10A, 2 pcs | Pololu | $7.58 | Pololu #5382. Only 1 required. Prevents PSU backfeed from battery |

## Monitoring & Control

| Item | Vendor | Unit Price | Notes |
|---|---|---|---|
| Shelly Plus Uni | Amazon | $18.99 | 2× ADC, DS18B20 support, WiFi, HA native integration |
| DS18B20 1M Temperature Sensor, 2 pcs | Amazon | $4.48 | Waterproof 1m cable, 1-Wire protocol |

## Protection & Wiring

| Item | Vendor | Unit Price | Notes |
|---|---|---|---|
| Mini Inline Fuse Holder 16AWG, 6 pcs | Amazon | $4.99 | For F1–F4 |
| Mini (Dual Blade) APM/ATM Fuse Assortment | Amazon | $4.66 | 2×10A (F1+F2), 1×5A (F4), 1×2A (F3) |
| 16AWG Wire 3' Black / 3' Red | Amazon | $5.55 | All wiring is 16AWG |
| 2 Pack DC Barrel Jack 5.5mm×2.1mm 18AWG 36" | Amazon | $7.51 | HA Green load connections |
| Comcast/Xfinity DC Barrel Jack | Xfinity | — | Free from Xfinity Store |
| 3' 16/3 Power Cord w/Pigtail | Amazon | $5.99 | AC input to PSU |
| 16-14AWG Nylon Female Spade Connectors | Amazon | $4.49 | Battery F2 terminal connections |
| Screw Terminal Block 2 Pin, 5mm Pitch, 4 pcs | Pololu | $1.89 | Ideal diode connections |
| Wago Lever Nuts, 5-Port | Amazon | $9.99 | All Wago connectors — 8 used|

## Enclosure & Hardware

| Item | Vendor | Unit Price | Notes |
|---|---|---|---|
| LeMotech Junction Box 10"×7.9"×4.7" | Amazon | $21.84 | IP65 ABS (exterior dims; interior 9.6"×7.6"×4.5"), includes mounting hardware (5% discount applied) |
| 1/2" NPT Cable Glands, 5-Pack | Amazon | $4.99 | AC and DC cable entries |
| Velcro Heavy Duty, 2"×4", 3 sets | Amazon | $4.93 | PSU and Victron BP-65 wall mounting |

## Tools

| Item | Vendor | Unit Price | Notes |
|---|---|---|---|
| Wire Strippers / Crimping Tool | Amazon | $4.74 | 16-14AWG |
| Soldering Kit 60W, 110V | Amazon | $7.99 | For terminal connections |

---

## Vendor Summary

| Vendor | Items | Amount |
|---|---|---|
| Amazon | All components except Pololu | $204.19 (sub-total) |
| Pololu | Ideal diode (×2), screw terminal blocks, USPS shipping ($6.45) | $15.92 |
| Amazon Cash Back (5%) | — | −$10.21 |
| Sales Tax | — | $13.98 |
| **TOTAL** | — | **$223.88** |

## Cost by Category

| Category | Cost | % of Total |
|---|---|---|
| Main Power Components (PSU, Battery, BP-65, Ideal Diode) | $100.63 | 45.0% |
| Monitoring & Control (Shelly, DS18B20) | $23.47 | 10.5% |
| Protection & Wiring | $44.94 | 19.7% |
| Enclosure & Hardware | $32.83 | 14.6% |
| Tools | $12.73 | 5.7% |
| Pololu Shipping | $6.45 | 2.9% |
| Amazon Cash Back (5%) | −$10.21 | — |
| Sales Tax | $13.98 | 6.2% |
| **TOTAL** | **$223.88** | 100% |

> Tools ($12.73) are one-time costs not specific to this project and can be excluded if already on hand, reducing the effective build cost to ~$211.

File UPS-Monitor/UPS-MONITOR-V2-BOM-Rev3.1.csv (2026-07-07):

Qty | Designator | Value | Description | Package | Notes
1 | U1 | ESP32-C3-MINI-1-N4 | WiFi/BLE MCU module | Module | Integrated PCB antenna; no external antenna required
1 | U2 | INA228AIDGST | 85V 20-bit power monitor | MSOP-10 | I2C addr 0x40; reset_on_boot: false to preserve energy accumulator
1 | U3 | AP63203WU-7 | 2A synchronous buck converter | SOT-23-6 | 13.3V→3.3V; Vout set by R6/R7
1 | R_SHUNT | WSLT2512R0100FEA | 10mΩ 1% Kelvin shunt | WSK2512 (6332) | Vishay TRUE 4-terminal; 1W rated
2 | R1, R2 | 4.7k 1% 0402 | I2C SDA/SCL pullups | 0402
1 | R3 | 10k 5% 0402 | INA228 A0/A1 address pulldown | 0402 | Both address pins to GND → I2C addr 0x40
1 | R4 | 100R 5% 0402 | LED current limit | 0402
1 | R5 | 10R 5% 0402 | INA228 VBUS series filter | 0402 | LOAD_OUT → R5 → U2 pin9 VBUS. RC pole with C9 at 160kHz
1 | R6 | 210k 1% 0402 | Buck FB divider top | 0402 | Sets 3.3V output with R7
1 | R7 | 68k 1% 0402 | Buck FB divider bottom | 0402
1 | R8 | 10k 5% 0402 | ESP32 EN pullup | 0402
1 | R9 | 4.7k 5% 0402 | DS18B20 data pullup | 0402 | Required for OneWire
2 | R10, R11 | 5.1k 5% 0402 | USB-C CC1/CC2 | 0402 | Device identification resistors
1 | C1 | 100uF 25V | Input bulk cap | Electrolytic 6.3x5.4mm | Low ESR preferred
1 | C2 | 10uF 25V X5R | LOAD_OUT filter | 0805 MLCC
1 | C3 | 22uF 10V X5R | 3.3V output cap | 0805 MLCC
5 | C4, C5, C6, C7, C9 | 100nF 10V+ X7R | Bypass / filter caps | 0402 MLCC | C4=3.3V; C5/C6=ESP32; C7=buck HF; C9=INA228 VBUS filter (with R5)
1 | C8 | 1uF 10V X5R | ESP32 EN RC cap | 0402 MLCC | τ=10ms with R8 10kΩ. MUST be 1µF — not 100nF
1 | L1 | 4.7uH 2.6A IHLP-5050FD | Buck inductor — superior DCR vs EZ variant | Vishay IHLP5050FDER4R7M01 | Low DCR 8.7mΩ; same footprint as EZ. Backup: SHOU HAN CYA0630 C5189748 (verify land pattern before ordering)
1 | TVS1 | SMAJ15CA | 15V bidirectional TVS | SMA | Input transient protection
1 | J1 | Phoenix Contact SPT-SMD 1,5/2-V-5,0 R24 | 2P SMD push-in terminal — 5.0mm pitch | Phoenix Contact 1824307 | 12V battery input | HAND PLACEMENT - PCBWay
1 | J2 | Phoenix Contact SPT-SMD 1,5/2-V-5,0 R24 | 2P SMD push-in terminal — 5.0mm pitch | Phoenix Contact 1824307 | 12V load output | HAND PLACEMENT - PCBWay
1 | J3 | PinHeader 1x03 2.54mm | DS18B20 header | Through-hole 2.54mm | VCC / DATA / GND | HAND PLACEMENT - PCBWay
1 | J4 | USB4110-GF-A | USB-C edge-mount receptacle (16-pin USB 2.0) | GCT USB4110-GF-A | WARNING: disconnect 12V before connecting USB — VBUS tied to LOAD_OUT | HAND PLACEMENT - PCBWay
1 | LED1 | Blue 0402 | Status LED | 0402
2 | SW1, SW2 | Omron B3S-1000 | BOOT / RESET tactile switch | SMD B3S-1000 | SW1=BOOT (GPIO9); SW2=RESET (EN) | HAND PLACEMENT - PCBWay

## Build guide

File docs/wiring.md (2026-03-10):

# Wiring Reference

All power wiring is 16AWG unless noted. See [voltage-drop-analysis.md](voltage-drop-analysis.md) for resistance and drop calculations.

---

## Fuse Locations and Ratings

| Fuse | Rating | Location | Purpose |
|---|---|---|---|
| F1 | 7.5A fast-blow | PSU output | Protects PSU output circuit; selective coordination with PSU internal 8A fuse |
| F2 | 10A fast-blow | Battery positive | **INSTALL FIRST** — protects battery circuit |
| F3 | 2A fast-blow | BP-65 OUT → HA Green | Protects HA Green load circuit |
| F4 | 5A fast-blow | BP-65 OUT → XB7 Modem | Protects Xfinity Modem load circuit |

> Install F2 before connecting the battery to any other part of the circuit. This is the primary short-circuit protection for the battery.

---

## Component Mounting

| Component | Mounting Method |
|---|---|
| Mean Well HDR-60-12 PSU | Flat on enclosure floor, trimmer facing up |
| Victron BatteryProtect BP-65 | Left wall of enclosure |
| Pololu Ideal Diode | Float — secure with wire ties |
| Shelly Plus Uni | Float — secure with wire ties |
| Wago lever nuts | Float — secure with wire ties or cable clips |
| DS18B20 sensor | Kapton tape against battery case midpoint |

---

## BP-65 Terminal Stud Assembly

Both the IN and OUT M6 studs accept two stacked M8 ring terminals using a copper washer sandwich. Assembly order (bottom to top):

1. M6 copper washer — seats on stud, centers lower ring
2. M8 ring terminal (first source or load)
3. M6 copper washer — separates rings, prevents rotation
4. M8 ring terminal (second source or load)
5. M6 copper washer — tops the stack
6. Lock washer
7. M6 nut — torque 4–5 N·m

Apply NO-OX-ID or equivalent contact grease to washer faces before assembly.

| Stud | Bottom Ring | Top Ring |
|---|---|---|
| BP-65 IN | Battery+ via F2 | PSU+ via F1 + ideal diode |
| BP-65 OUT | XB7 branch via F4 | HA Green branch via F3 |

---

## Wiring Connections — From/To Reference

### AC Input → PSU

| From | To | Notes |
|---|---|---|
| Power Cord — Black (Hot) | PSU L terminal | |
| Power Cord — White (Neutral) | PSU N terminal | |
| Power Cord — Green (Ground) | PSU Ground terminal | Safety ground — required |

### PSU → BP-65 IN

| From | To | Notes |
|---|---|---|
| PSU V+ | F1 input | 16AWG |
| F1 output | Ideal Diode VIN+ | 16AWG |
| Ideal Diode VOUT+ | BP-65 IN stud (top ring) | 16AWG; M8 ring, copper washer sandwich |
| PSU V− | Wago GND #1 port 2 | 16AWG |

### Battery → BP-65 IN

| From | To | Notes |
|---|---|---|
| Battery+ (spade) | F2 input | 16AWG; **install F2 first** |
| F2 output | Wago tap (221-415) port 1 | 16AWG |
| Wago tap port 2 | BP-65 IN stud (bottom ring) | 16AWG; M8 ring, copper washer sandwich |

### BP-65 OUT → Loads

| From | To | Notes |
|---|---|---|
| BP-65 OUT stud (top ring) | Wago F3 (221-415) port 1 | 16AWG; M8 ring, copper washer sandwich |
| Wago F3 port 2 | F3 input (2A) | 16AWG |
| F3 output | HA Green barrel plug+ (center) | 5.5mm × 2.1mm, center-positive |
| BP-65 OUT stud (bottom ring) | Wago F4 (221-415) port 1 | 16AWG; M8 ring, copper washer sandwich |
| Wago F4 port 2 | F4 input (5A) | 16AWG |
| F4 output | XB7 barrel plug+ (center) | 5.5mm × 2.1mm, center-positive |

### Ground Returns

All grounds consolidate at two daisy-chained Wago 221-415 five-port connectors connected via pigtail to battery−. A separate Wago Sensor GND handles the sensor ground reference per the Shelly Plus Uni schematic.

| From | To | Notes |
|---|---|---|
| Battery− (spade) | Wago GND #1 port 1 | 16AWG pigtail |
| PSU V− | Wago GND #1 port 2 | 16AWG |
| BP-65 GND terminal | Wago GND #1 port 3 | 18AWG |
| Wago GND #1 port 4 | Wago GND #2 port 1 | 16AWG daisy-chain jumper |
| XB7 barrel plug− (sleeve) | Wago GND #2 port 2 | 18AWG |
| HA Green barrel plug− (sleeve) | Wago GND #2 port 3 | 18AWG |
| Shelly harness VAC2 (black) | Wago GND #2 port 4 | 22AWG; Shelly power ground |
| Wago Sensor GND port 3 (pigtail) | Wago GND #2 port 5 | 22AWG; ties sensor GND to system ground |

### Shelly Plus Uni Monitoring

The Shelly connects via a pre-attached wiring harness. All connections require a Wago to join a harness wire to the corresponding field wire. The Wago tap (221-415) on the battery+ line after F2 provides the Shelly supply and voltage sense — this ensures the Shelly reads true battery voltage independent of PSU state.

| From | To | Notes |
|---|---|---|
| Wago tap (221-415) port 3 | Shelly harness VAC1 (red) | 22AWG; Shelly supply (9–28VDC input) |
| Shelly harness VAC2 (black) | Wago GND #2 port 4 | 22AWG; Shelly power ground |
| Wago tap (221-415) port 4 | Shelly harness ANALOG IN (white) | 22AWG; battery voltage sense; configure for 0–15V range in Shelly web UI |

### DS18B20 Temperature Sensor

The Shelly Plus Uni has a built-in pull-up on the DATA harness wire — no external resistor required. DS18B20 GND routes through the Shelly's GND (green) wire per the schematic, ensuring a common sensor and ADC reference ground.

DS18B20 wire colors: red (VCC), yellow (Data), blue (GND).

| From | To | Notes |
|---|---|---|
| Shelly harness SENSOR VCC (yellow) | Wago DS18B20 VCC (221-415) port 1 | 22AWG |
| DS18B20 VCC (red) | Wago DS18B20 VCC (221-415) port 2 | 22AWG |
| Shelly harness DATA (blue) | Wago DS18B20 Data (221-415) port 1 | 22AWG |
| DS18B20 Data (yellow) | Wago DS18B20 Data (221-415) port 2 | 22AWG |
| Shelly harness GND (green) | Wago Sensor GND (221-415) port 1 | 22AWG; sensor and ADC reference ground |
| DS18B20 GND (blue) | Wago Sensor GND (221-415) port 2 | 22AWG |
| Wago Sensor GND port 3 | Wago GND #2 port 5 | 22AWG pigtail to system ground |

---

## Wago Connector Summary

| Designator | Part | Ports Used | Function |
|---|---|---|---|
| Wago tap | 221-415 (5-port) | 4 of 5 | Battery+ tap — BP-65 IN ring, Shelly VAC1, Shelly ANALOG IN |
| Wago F3 | 221-415 (5-port) | 2 of 5 | BP-65 OUT top ring to F3 fuse |
| Wago F4 | 221-415 (5-port) | 2 of 5 | BP-65 OUT bottom ring to F4 fuse |
| Wago DS18B20 VCC | 221-415 (5-port) | 2 of 5 | Shelly SENSOR VCC (yellow) to DS18B20 red |
| Wago DS18B20 Data | 221-415 (5-port) | 2 of 5 | Shelly DATA (blue) to DS18B20 yellow |
| Wago Sensor GND | 221-415 (5-port) | 3 of 5 | Sensor ground node — Shelly GND (green), DS18B20 GND (blue), pigtail to GND #2 |
| Wago GND #1 | 221-415 (5-port) | 4 of 5 | Ground bus — battery−, PSU−, BP-65 GND, jumper |
| Wago GND #2 | 221-415 (5-port) | 5 of 5 | Ground bus — jumper, XB7−, HA Green−, Shelly VAC2, sensor GND pigtail |

All Wago 221-series: 24–12AWG, 20A, 450V. One conductor per port — do not insert two wires into a single port.

---

## Wire Gauge Reference

| Gauge | Used for | Ampacity (chassis wiring) |
|---|---|---|
| 16AWG | All main power paths | 13A |
| 18AWG | BP-65 GND, device barrel leads | 10A |
| 22AWG | Shelly harness, DS18B20 leads | 3A |

---

## Assembly Sequence

1. Mount all components per enclosure layout.
2. Install F2 on battery positive lead — verify open circuit before proceeding.
3. Build Wago GND bus: wire battery− pigtail to Wago GND #1 port 1; wire PSU V− to port 2; wire BP-65 GND to port 3; jumper GND #1 port 4 to GND #2 port 1.
4. Wire device ground returns: XB7 barrel− to GND #2 port 2; HA Green barrel− to GND #2 port 3.
5. Build BP-65 IN stud assembly: copper washer, battery ring, copper washer, PSU ring, copper washer, lock washer, nut. Torque 4–5 N·m.
6. Wire battery+ → F2 → Wago tap port 1; Wago tap port 2 → BP-65 IN bottom ring.
7. Wire PSU V+ → F1 → ideal diode → BP-65 IN top ring.
8. Build BP-65 OUT stud assembly same as IN stud.
9. Wire F3 branch: BP-65 OUT top ring → Wago F3 → F3 → HA Green barrel+.
10. Wire F4 branch: BP-65 OUT bottom ring → Wago F4 → F4 → XB7 barrel+.
11. Wire Shelly harness: VAC1 (red) from Wago tap port 3; ANALOG IN (white) from Wago tap port 4; VAC2 (black) to Wago GND #2 port 4.
12. Wire DS18B20: VCC (red) via Wago DS18B20 VCC port 2; Data (yellow) via Wago DS18B20 Data port 2; GND (blue) to Wago Sensor GND port 2. Wire Shelly GND (green) to Wago Sensor GND port 1; pigtail Wago Sensor GND port 3 to Wago GND #2 port 5.
13. Secure DS18B20 against battery case midpoint with kapton tape.
14. Verify all connections with multimeter before applying AC power.
15. Follow commissioning.md for first power-up sequence.

---

## Enclosure Layout

See [README](../README.md) for the assembly drawing image.

The enclosure is a LeMotech ABS junction box (9.6″ × 7.6″ × 4.5″ interior), originally IP65-rated. Six ¼″ ventilation holes have been drilled (3 intake low on the PSU wall, 3 exhaust high on the BP-65 wall), reducing the effective rating to approximately IP4X. This is a non-issue for an indoor floor installation. Key layout decisions:

- PSU lies flat on the enclosure floor against one wall, trimmer facing up; battery occupies the center floor with ~¾″ gap between them forming a DC wiring chase.
- BP-65 mounts on the left wall. Both supply sources (PSU and battery) run directly to the BP-65 IN stud — no terminal block in the positive power path.
- Ideal diode floats above the PSU, secured with wire ties.
- Shelly floats above the battery, secured with wire ties. Wago connectors cluster near the Shelly for short harness runs.
- Cable glands (½″ NPT) on the bottom face: AC input on the left, DC output barrel jacks on the right.
- DS18B20 mounts on the battery case midpoint; its leads route to the DS18B20 Wago connectors near the Shelly.

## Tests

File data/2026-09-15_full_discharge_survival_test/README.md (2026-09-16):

# Reproduction Guide — 2026-09-15 Full Discharge & Survival Test

Backs `reports/UPS_Report_2026-09-15_Full_Discharge_Survival_Test.md` (**r2** — r1 is superseded; see that report's §10 and its inline R13 corrections). This file is the short "how to check my work" companion — read the report itself for the full analysis.

---

## ⚠ Read this before opening the raw files

Four properties of the InfluxDB data will silently corrupt any re-analysis that does not account for them. All four are [M]. The first three are reproducible from the files in this directory; the fourth bites only on live re-queries.

**1. The export covers 37.5 of ~90 discharge minutes, and the gap does NOT start at the LVD trip.**

| Series | Gap start | Gap end | Duration |
| :--- | :--- | :--- | ---: |
| V | 13:54:30.6Z | 15:01:24.7Z | 4014.1 s (66.90 min) |
| A | 13:54:31.9Z | 15:01:24.7Z | 4012.8 s |
| W | 13:54:30.1Z | 15:01:24.7Z | 4014.6 s |

The gap opens at **13:54:30Z**, when HA's recorder died at the graceful shutdown — **53 minutes before the LVD trip at 14:47:18Z**. Every Knee-HA-down and Cliff figure in the report therefore comes from `esp32_direct_api_log.txt` and the ESPHome capture, **not** from these files. *(r1 of the report and of this README both said the gap ran "from the LVD trip". It does not.)*

**2. There is one phantom sample per series at 15:01:24.73Z. Drop it.**

```
V  13:54:30.641901Z = 12.5302495956421   ->  15:01:24.728230Z = 12.5302495956421
A  13:54:31.898975Z = -1.96474993228912  ->  15:01:24.728682Z = -1.96474993228912
W  13:54:30.147715Z = -25.3829574584961  ->  15:01:24.728887Z = -25.3829574584961
```

Bit-identical to the last pre-gap value in all three series. This is HA's recorder writing last-known state on restart — **not a measurement**. Left in place, it puts a −1.96 A *discharge* point 74 s after charging began. The first true post-recovery samples are at **15:01:25.27Z** (13.0753 V, +3.1862 A).

**3. The InfluxDB measurements are SHARED ACROSS ENTITIES — always filter `entity_id`.**

`A`, `V` and `W` are named after the *unit*, not the device. The database holds **19 entities in `A`** and **24 in `V`**, including the separate 12 V / 500 Ah `battery_bank_monitor_*` pack, the AC-side `ups_outlet_*`, and this pack's former `ups_monitor_bench_*` names (which the May 2026 CSVs use). An unfiltered query silently returns a mixture — during this revision it produced a discharge that never happened, 659 Wh out of a 53 Wh pack, and a 119.0 V starting voltage. Always:

```sql
WHERE ("entity_id"='ups_monitor_battery_current'
    OR "entity_id"='ups_monitor_bench_battery_current')
```

The JSON files in this directory were exported with the filter applied; live re-queries are where the trap bites.

**4. V, A and W are skewed against each other.** A lands **+1.24 to +1.32 s** after V; W lands **−0.43 to −0.53 s** before it [M, n = 12 consecutive]. **r3:** that holds for the *discharge* portion only. The offset is re-drawn at every boot, and the 10:59:47 survival wake falls inside this export — after it, A lands **1.30 s before** V [M, ESPHome log, n = 215]. Report §10.3. Fixed from firmware V1.20 (2026-09-16) on; this export predates it. On a 5 s grid that is a fifth of a sample period, and it is the dominant error term in every step-resistance derivation. Pair V with I only where the load is steady — **never across a step**.

---

## Files here

| File | What it is |
| :--- | :--- |
| `raw_V.json`, `raw_A.json`, `raw_W.json` | InfluxDB export — `ups_monitor_battery_voltage`/`current`/`power`, query span 2026-09-15 13:16–15:45 UTC. **Coverage span is shorter than the query span — see warning 1 above.** |
| `esp32_direct_api_log.txt` / `esp32_direct_api_script.py` | Direct ESPHome-native-API monitor (bypasses HA) and its log — 93 heartbeats at 60 s + 73 flags at 5 s. Blackout 10:46:28–11:00:19 local. |
| `ha_poller_log.txt` / `ha_poller_script.py` | HA-REST-API monitor. **Carries the 09:34:14 firmware-counter anchor** used for the coulomb-counter cross-check. |
| `network_reachability_log.txt` / `network_reachability_script.py` | Independent ICMP/TCP probes against the XB7 gateway, HA host and ESP32. **Contains the uncorrected tool's three false "back UP" reports (09:55:41, 09:59:04, 10:06:40), preserved deliberately** — the corrected tool restarts at 10:09:26. |
| `live_vs_public_repo.diff` | `diff` of live `H:\esphome\ups-monitor.yaml` against this repo's `UPS-Monitor/ups-monitor.yaml` — 0 lines, both `version: "1.19"`. |

Also used, one level up: `data/logs_ups-monitor-Sept_15_2026_logs.txt` — the owner's independent continuous `esphome logs` capture, 10:04:58–11:18:44 local, 5 s cadence. **This is the only source for the first post-recovery charge reading and for the pre-test `Survival Exit Reason` value.**

---

## Reproducing the key claims

**The capacity shortfall (report §4) — the principal finding.** Two comparisons:

- *Load- and span-matched, vs the 08-31/09-01 test.* Integrate `raw_A.json` and `raw_W.json` from `13:17:00Z` to the first sample at or below **12.565 V** in `raw_V.json` (that is `13:48:00Z`, 12.5460 V). Trapezoid gives **1.0559 Ah / 13.4394 Wh over 31.0 min at 2.043 A mean** (n = 371). The 08-31 report r2 §2 records **1.833 Ah / 23.369 Wh over 54 min at 2.089 A** for the same voltage span. That is **−42.4 % Ah, −42.5 % Wh at matched current**, fourteen days apart. Both this window and the 08-31 window sit entirely inside InfluxDB coverage, so warning 1 does not bite here.
- *LVD-to-LVD, vs 2026-05-06.* 2.5331 Ah / 31.821 Wh against 4.179 Ah / 53.271 Wh = **−39.4 % / −40.3 %**.

**That the coulomb counter is not at fault.** Three checks, all reproducible:
1. `ha_poller_log.txt` line 2 records `fw_ah=0.578883051872253` at 09:34:14. Trapezoid `raw_A.json` over `13:17:00Z`–`13:34:14Z` (n = 206) → **0.5844 Ah**, i.e. **+0.95 %**. Two storage paths, two clocks.
2. Over 10:06:36–10:46:28 the heartbeat counter advances 0.9409 Ah vs 0.9410 Ah by trapezoid on its own published current — **+0.010 %**.
3. The uninstrumented window 09:54:31–10:06:36 must, by difference against the counter, hold 0.2876 Ah → implied mean **1.428 A**, against an independently measured post-shutdown load of ~1.40 A.

**Is it uniform fade or one bad cell?** The pack is sealed — no balance taps, no BMS telemetry — so per-cell voltages are unavailable. The terminal-only substitute uses data already in this repo: `data/Voltage.csv`, `data/Current.csv` and `data/Ah Delivered.csv` hold the **complete 2026-05-06 discharge at 5 s cadence** (n = 2,346 in-window, Ah counter reaching 4.1789). Build pack OCV = `V_loaded + |I| x Ri` against charge removed, normalise each run against **its own** total, and overlay.

Uniform fade predicts the normalised curves overlay. They do not — September sits **60 to 220 mV below** May at every depth (−0.096 V at 5 %, −0.221 V at 50 %, −0.402 V at 95 %), and at matched *absolute* Ah the gap widens monotonically from −134 mV at 0.25 Ah to −924 mV at 2.50 Ah. Sensitivity is `+0.77 V per ohm` of Ri assumed (ΔI ≈ 0.77 A between runs), so sweeping Ri across the whole measured family — 93, 146, 173, 260 mΩ — leaves the depression negative in every cell. That is evidence against uniform fade and for a non-uniform pack. **One confound remains:** the curve is anchored at "charge removed = 0", which assumes both runs started from the same state, and nothing on this system verifies that. Report §4.6 Tests B and C close it.

**What does not explain the shortfall.** Rate effect ≤0.036 Ah (cliff slope measured here at **2.02 V/Ah**, corroborating the 08-31 report's ~1.8 V/Ah); Peukert would need **k = 2.40** against 1.01–1.05 for LiFePO4; float droop ≤0.11 Ah (pre-outage float 13.2047 V vs 13.1970 V post-boost mean); temperature ~0 (77.3–78.2 °F, inside the LFP flat zone). Combined **≤ 9.7 %** of the LVD-to-LVD gap and ~0 % of the load-matched gap.

**Peak recharge current, and why 4.4465 A is a lower bound.** Grep the ESPHome log for `Battery Current` after `11:00:1` — max in the throttled stream is 3.9520 A at 11:00:33. The firmware's own `recharge_peak_a` caught **4.4465 A**, published via `sensor.ups_monitor_last_recharge_peak_current` ~13 s after `on_battery` clears (it is written only in `on_battery`'s `on_release` handler). **But AC return was observed by nothing**: the ESP32 sleeps on a 120 s quantum and woke at 11:00:09, while XB7/host ICMP returned at 10:59:49 — so charging had already run ~60–160 s. The true peak was never sampled.

**That the recharge is PSU-limited.** The Mean Well HDR-60-12 is **54 W / 4.5 A** [S, datasheet; `docs/bom.md` "4.5A/54W"]. The ESPHome log at `11:00:13.671` reads `Battery Power >> 54.627 W` and `Battery Current >> 3.8975 A` — ~~**101 % of the whole supply's nameplate, into the battery branch alone**~~ **r3 (R13): a publish-skew artifact, corrected in report r2 §7.2 but never carried here** — V × I = **50.86 W, 94.2 %** of nameplate, into the battery branch alone, before any share for XB7, host or monitor. The firmware peak of 4.4465 A is **98.8 % of the 4.5 A rating**. *(r1 read the nameplate as "54 A" and concluded the recharge was never PSU-limited. It was PSU-limited throughout.)*

**Was the overage just the BP-65 reconnect hold-off?** Partly — but not for this reading. Grep the ESPHome log for `Battery Current` from `11:00:1` to `11:08`. A BP-65 closure admitting ~2 A of load would step battery current down ~2 A and hold it there; no such step exists. The only excursion is a single −0.907 A dip at `11:00:23` (one second before `Xfinity Modem Online` goes ON) that recovers *above* its pre-dip value by `11:00:33`. ICMP puts XB7 and the host back at **10:59:49**, 24 s before the first charge reading, so loads were already live. The hold-off window was real but closed before any instrument was awake — which is where the true peak lived, unobserved. Adding the measured 26.80 W load: total output runs ~~150.8 %~~ **143.8 % of nameplate at 11:00:13** [D, with the corrected 50.86 W], **decaying to 96.0 % by 11:07:58** — a transient, not a steady state.

**Settling-phase collapse — and its limit.** Load `raw_V.json`, filter `13:16:55Z`–`13:17:15Z`. V falls 13.2047 → 13.0340 within one 5 s sample, past both the 13.15 V and 13.00 V boundaries before `on_battery` registers at 13:17:10. **This bounds Settling at < 5 s at this current; it does not show Settling is absent.** The sampler cannot resolve it (R18).

**The shutdown trigger is noise-dominated (report §6.1) — reproducible at n = 2.** Query the firmware's own published slope, `SELECT "value" FROM "mV/min" WHERE "entity_id"='ups_monitor_voltage_slope'`, over each discharge window. 2026-09-01 gives n=52, sd 18.7 mV/min, **21 crossings** of the −10 mV/min threshold in 52 min; 2026-09-15 gives n=37, sd 24.0, **12 crossings**. Then read `automation.ups_graceful_shutdown_cliff_or_8_min_runtime`: both runs show a trigger that fired, aborted after exactly 30 s, and fired again. Inside the gated region (V < 12.65 V) every excursion below −10 mV/min lasts 1–2 samples and never 3 — which is the basis for the `delayed_on: 180s` recommendation in §6.1.1. **Deployed in firmware V1.20 (2026-09-16).**

**Why `Apparent Ri` failed its gate — and why r1's reason was wrong.** Filter `raw_A.json` from `13:17:01Z` for 100 s and compute deviation from the arm value (−1.8725 A). You get **16 of 20 samples inside the ±15 % band**, **10 up / 9 down** consecutive differences, CV **6.66 %**, peak-to-peak 22.7 % of mean. That is a bursty load with stationary noise, not a ramp — the 45 s mark simply landed on one of the ~20 % burst excursions. The fix is to compare a **median or windowed mean** against `trig_i`, not a single instantaneous sample; lengthening the dwell would not help. **Deployed in firmware V1.20 (2026-09-16)** as 15 s windowed means, after a replay at n = 4 onsets (report §8.1).

**Ri reconstructions, and why they are not comparable.** Both use the firmware's own formulas (`H:\esphome\ups-monitor.yaml`, or `UPS-Monitor/ups-monitor.yaml` here — identical, see the diff):
- Apparent Ri: `(rest_v − v_now) / (−i_now) × 1000`, lines 1374–1380.
- Recharge-step Ri: `(vC − vD) / (iC − iD) × 1000`, line 2828.

Eight estimates exist across this dataset spanning **67–260 mΩ**, and **no two methods agree within 30 %**. The onset figure alone swings **90 → 128 mΩ on sample-pairing choice**, because of warning 3. Any Ri trend claim needs one method held fixed across runs; none of these is evidence about capacity in either direction.

**Why each Ri sensor froze.** Read `ups-monitor.yaml` at the lines cited in report §8 — the `restore_value: no`/`yes` declarations (search `g_onset_was_discharging`, `g_last_loaded_v`, `g_onset_r`) settle which ones a reboot can explain. **r3:** only two froze. `Last Onset Step Resistance` updated at 09:17:48 (report §8.2), and a recharge-step value cannot exist after a survival sleep — there is no discharge→charge step to measure (report §8).

**Live-vs-public reconciliation.** `diff "H:\esphome\ups-monitor.yaml" "UPS-Monitor\ups-monitor.yaml"` — 0 lines at test time.

---

## Access needed to re-run any live queries

- HA REST API: `HA_TOKEN` env var, `http://10.0.0.210:8123`
- InfluxDB: `http://10.0.0.210:8086`, database `Home Assistant`, credentials at `H:\secrets.yaml` (`influxdb_user`, `influxdb_pass`) — **do not commit these**, this repo is public
- ESPHome native API: `10.0.0.232:6053`. `esp32_direct_api_script.py` reads the noise PSK from the **`UPS_MONITOR_NOISE_PSK`** environment variable — set it from `api_key_ups_monitor` in `H:\secrets.yaml` before running. It is never inlined in the script; this repo is public.

---

## Conclusions, condensed

- **The pack delivered 42.4 % less charge than it did fourteen days earlier at the same load over the same voltage span.** No rate, Peukert, float or thermal mechanism accounts for more than ~10 % of it. This is the report's principal finding (§4).
- The normalised OCV-vs-charge overlay against May (from CSVs already in this repo) argues **against uniform capacity fade and for a non-uniform pack**, robust to every Ri in the measured family. Per-cell confirmation is impossible — the pack is sealed — so the decisive test is a **matched-load repeat at May's ~1.2–1.4 A** (Open Item 14a) plus a **coulomb-counted recharge to termination** (Open Item 16).
- Full discharge ladder (Settling→Plateau→Knee→Cliff→LVD) measured for the first time; BP-65 trip delay bounded to **90–109 s** against a documented ~102 s.
- Survival mode validated for the first time: 5 clean sleep/wake cycles. `Recovery` exit is reported, but that field held the same value *before* the test, so a fresh write cannot be confirmed from its value alone.
- The recharge was at the HDR-60-12's constant-current limit throughout — **not** pack-limited.
- ~52.8 min of unsupervised margin between HA shutdown and the LVD trip, at this test's reduced post-shutdown load. Real headroom, but gated on characterising capacity first — Open Item 14a is a constant-load discharge and satisfies the margin question in the same run.
- `on_battery` slow-to-clear and `Last Recharge Peak Current` "unknown" were both correct, on-spec behaviour.
- **The shutdown trigger's slope term is noise-dominated, confirmed at n = 2**, and every graceful-shutdown attempt in the record has aborted at least once before succeeding. The fix is a dwell change (`delayed_on: 60s` → `180s`), not a threshold change — report §6.1 and §6.1.1. **Deployed in V1.20.**
- `Apparent Ri` and the recharge-step sensors have named, reproducible failure modes (report §8). ~~`Last Onset Step Resistance` (Open Item 13) and `total_outages` (Open Item 9b) remain unexplained.~~ **r3:** neither was a defect — both updated during the test, at 09:17:48–49 (report §8.2, §9.1). The recharge-step "failure mode" is correct behaviour after survival sleep (report §8).
- Prior-report figures independently re-derived from raw: 2026-09-01 **1.8316 Ah** (−0.1 %) and 2026-08-29 **0.4731 Ah** (−0.3 %). Open Item 15 closed.

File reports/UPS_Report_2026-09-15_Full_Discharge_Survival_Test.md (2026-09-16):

# DIY LiFePO4 UPS: Technical Report
## Full Discharge to BP-65 LVD, First Survival-Mode Validation, Recharge — and a 42 % Capacity Shortfall

**Data through:** 2026-09-15 15:52 UTC (11:52 local) · **Version:** 2026-09-15-r3 · **Report series:** UPS-RPT
**Repository:** https://github.com/wkcollis1-eng/DIY-LiFePO4-UPS
**Firmware under test:** `ups-monitor.yaml`, ESPHome 2026.8.2, project version 1.19, ESP32-C3
**Supersedes:** 2026-09-15-r1 (uncommitted draft). Every r1 finding this revision corrects is recorded at the site where the error was made rather than silently replaced, per R13.
**r3 (2026-09-16):** corrects four r2 errors found by querying the full InfluxDB history rather than the test-window exports: two open items that were never defects (`Last Onset Step Resistance` and `total_outages` both updated during this test, §8.2, §9.1); a fully-charged detector r2 said had never fired, which was ON before both load-matched runs (§4.5); and a publish-skew mechanism that is re-drawn every boot, not fixed (§7.2, §10.3). Each is recorded at its site, the superseded text struck through rather than removed. r3 also records firmware **V1.20** (deployed 2026-09-16), which closes Open Items 19–21 (§11).

Every numeric claim carries its basis inline: **[M]** measured, **[D]** derived arithmetic on [M] with the formula shown, **[I]** inferred and carrying its falsifier, **[S]** spec or prior document with its identifier. Ratios carry n and a test, or they are not written (R17). Any figure whose sampling cadence is slower than the quantity it describes is named as a bound on the instrument, not a property of the world (R18).

**Time base:** all times local (EDT, UTC−4) unless suffixed `Z`. The raw InfluxDB exports are in UTC; the ESPHome and ad hoc monitor logs are in local time.

---

## Abstract

A deliberate outage test (`switch.ups_outlet` OFF at 09:16:58) ran the pack through its full documented ladder — Settling (absent at this current, §3.1), Plateau, Knee, Cliff — to the Victron BP-65 hardware LVD, the first time this system has been run to a genuine hardware cutoff rather than stopped early. Survival sleep, never previously exercised, ran 5 confirmed cycles and exited cleanly. The system recovered without intervention.

**The finding that matters is not the ladder; it is the capacity.** The pack delivered **2.5331 Ah / 31.821 Wh** [M, firmware coulomb counter, cross-validated against an independent HA-side integration to +0.95 %, §4.1]. Against the 2026-08-31/09-01 test — **same load, same voltage span, fourteen days earlier** — this pack delivered **−42.4 % Ah and −42.5 % Wh** [D, §4.3]. Against the 2026-05-06 LVD run it is −39.4 % Ah / −40.3 % Wh. Every mechanical explanation available to this dataset — rate effect at the LVD endpoint (≤0.04 Ah), Peukert (would require an exponent of 2.40 against 1.01–1.05 for LiFePO4), float-ceiling droop (≤0.11 Ah), temperature (both runs inside the LFP flat zone) — accounts for **under 10 % of the LVD-to-LVD gap, and for none of the load-matched gap**. The residual is a property of the pack, not of the test. §4.5 ranks the candidate mechanisms. The pack is sealed — no balance taps, no BMS telemetry — so per-cell voltages are unavailable at any price, and §4.6 gives three non-invasive substitutes instead. One of them has already been run, on data that was in this repository the whole time, and it argues against uniform capacity fade and for a non-uniform pack.

Two secondary results are load-bearing for how this system is specified. First, **the recharge is PSU-current-limited, not pack-limited**: the Mean Well HDR-60-12 is a **54 W / 4.5 A** supply [S, datasheet; confirmed by owner 2026-09-15], and the firmware's captured peak of **4.4465 A** is **98.8 %** of its rated current. Charge power into the battery branch alone reached **~50.9 W** [M] — 94 % of the whole supply's nameplate — before any share for the XB7, host or monitor. A Kasa AC-side measurement (§7.4) closes the power-flow loop against the DC-side INA260 and shows the supply operating within rating everywhere it has coverage. Second, **the raw InfluxDB export covers only the first 37.5 minutes of a ~90-minute discharge** and contains three bit-identical stale samples on recorder restart (§10); anyone re-deriving these figures needs both facts before opening the files.

A third result concerns the shutdown trigger itself. Replaying the firmware against **both** this outage and the 2026-09-01 test shows its slope term carries noise of sd 18.7–24.0 mV/min against a −10 mV/min threshold, crossing that threshold 21 and 12 times respectively, and that **every graceful-shutdown attempt in the record has aborted at least once before succeeding** (§6.1). The cause is arithmetic — `delayed_on: 60s` against a 60 s slope update is one extra sample of confirmation — and §6.1.1 gives the one-line change the data supports.

On the timing question this test was run to answer: from the moment the host went down to the moment BP-65 tripped was **~52.8 minutes** [M], entirely unsupervised. That margin is real, but §6 sets out why it cannot be converted into a threshold change from this test alone — and §4 adds a second reason, which is that the margin was measured on a pack whose usable capacity is changing month to month.

---

## 1. Test Summary

| Event | Local | UTC | V | I | Source |
| :--- | :--- | :--- | ---: | ---: | :--- |
| Last clean float sample | 09:16:55.6 | 13:16:55.6 | 13.2047 | +0.017 A | InfluxDB |
| `switch.ups_outlet` OFF (test start) | 09:16:58 | 13:16:58 | — | — | HA |
| First loaded sample | 09:17:00.6 | 13:17:00.6 | 13.0340 | −1.8725 A | InfluxDB |
| `on_battery` ON | 09:17:10 | 13:17:10 | 12.9548 | −1.94 A | firmware |
| Poller baseline | 09:34:14 | 13:34:14 | 12.692 | −2.066 A | `ha_poller_log` |
| Phase Plateau → Knee | 09:41:48 | 13:41:48 | 12.649 | — | firmware |
| `cliff_imminent` 1st trigger (aborted in the 30 s revalidation window) | 09:44:47 | 13:44:47 | ~12.66 | — | HA |
| `cliff_imminent` 2nd trigger (held) | 09:53:51 | 13:53:51 | 12.532 | −2.03 A | HA |
| **InfluxDB last write — HA recorder stops** | **09:54:30.6** | **13:54:30.6** | 12.5302 | −1.9647 A | InfluxDB |
| HA API begins refusing connections | 09:54:53 | 13:54:53 | — | — | poller |
| ICMP first DOWN (one false recovery follows at 09:55:41) | 09:55:37 | 13:55:37 | — | — | net_watch |
| ICMP sustained DOWN | 09:55:52 | 13:55:52 | — | — | net_watch |
| ESPHome continuous log capture begins | 10:04:58 | 14:04:58 | — | — | ESPHome |
| Direct ESP32 API monitor connects | 10:06:31 | 14:06:31 | 12.5673 | −1.4330 A | direct API |
| Corrected net_watch restarts; confirms HA down | 10:09:30 | 14:09:30 | — | — | net_watch |
| Phase Knee → Cliff | 10:32:50 | 14:32:50 | 12.399 | −1.41 A | firmware |
| Voltage Warning (12.40 V) | 10:33:26 | 14:33:26 | 12.385 | — | firmware |
| Voltage Critical (12.20 V) | 10:38:56 | 14:38:56 | 12.199 | — | firmware |
| LVD Imminent (internal flag) | 10:44:06 | 14:44:06 | 11.897 | — | firmware |
| Last sample **≥** 11.800 V | 10:45:31 | 14:45:31 | 11.802 | — | direct API |
| First sample **<** 11.800 V | 10:45:36 | 14:45:36 | 11.791 | −1.46 A | direct API |
| Last telemetry of any kind | 10:47:07.7 | 14:47:07.7 | 11.675 | −1.4622 A | ESPHome |
| **BP-65 LVD trip** — XB7 ICMP down | **10:47:18** | **14:47:18** | — | — | net_watch |
| ESP32 ICMP down | 10:47:20 | 14:47:20 | — | — | net_watch |
| Survival mode: 5 sleep/wake cycles (§5) | 10:47:18 – 11:00:09 | — | 11.9275 → 11.9762 | ~0 A | firmware NVS |
| **AC restored (bounded, not observed)** | **~10:57:2x – 10:59:2x** | — | — | — | [I], §7.1 |
| XB7 + HA host ICMP return | 10:59:49 | 14:59:49 | — | — | net_watch |
| First ESP32 reading after wake | 11:00:09.98 | 15:00:09.98 | 13.047 | — | ESPHome |
| **Charge current first observed** | **11:00:13.67** | **15:00:13.67** | 13.047 | **+3.8975 A** (published P 54.627 W is skew-corrupted — use V×I = **50.86 W**, §7.2) | ESPHome |
| Phase → Charging | 11:00:19 | 15:00:19 | 13.049 | +3.8516 A | firmware |
| Xfinity Modem Online | 11:00:24 | 15:00:24 | — | — | firmware |
| ESP32 boot confirmed successful | 11:00:47.9 | 15:00:47.9 | — | — | `safe_mode:154` |
| HA API returns 200 | 11:01:19 | 15:01:19 | — | — | poller |
| InfluxDB stale-restore sample (§10.2) | 11:01:24.73 | 15:01:24.73 | *12.5302* | *−1.9647 A* | **artifact** |
| InfluxDB first true post-recovery sample | 11:01:25.27 | 15:01:25.27 | 13.0753 | +3.1862 A | InfluxDB |
| `on_battery` clears (V re-crosses 13.15 V) | 11:39:39 | 15:39:39 | 13.1555 | +1.13 A | firmware |
| `Last Recharge Peak Current` populates | 11:39:52 | 15:39:52 | — | 4.4465 A | firmware |
| Report data cutoff | 11:52:03 | 15:52:03 | 13.160 | +0.792 A | direct API |

**Outage duration.** `on_battery` ON → OFF = **2 h 22 m 29 s** [M]. This is a flag duration, not an AC-off duration: recovery occurred ~39 minutes earlier and the flag correctly stayed ON until bulk-charge current lifted the bus back over its own 13.15 V threshold (§9.1). **Discharge duration** (onset → LVD trip) = **1 h 30 m 08 s** [M, 09:17:10 → 10:47:18]. Use the second figure for all capacity and runtime work.

**On the phase log.** The ESPHome capture contains 240 `ups.phase` lines [M]; the handler re-logs the current phase periodically rather than only on transition, so a `Phase -> Cliff` line at 10:47:05 is a re-log, not a second transition. Transition times in this table are the first occurrence of each phase string.

---

## 2. What This Report Establishes, and What It Does Not

Stated up front so no reader has to reconstruct it from the body (R11).

**Established [M]:**
- Charge and energy delivered to a hardware LVD trip, on two independent integration paths agreeing to +0.95 %.
- A capacity shortfall against two prior runs, one of which is load- and span-matched.
- The BP-65 trip delay, bounded to 90–109 s against a documented ~102 s.
- Survival-mode cycle count, wake voltages and exit path, from NVS.
- Peak *observed* charge current and charge power, and their relation to the PSU nameplate.
- The unsupervised interval between host-down and LVD, on a non-ping anchor.
- That the shutdown trigger's slope term is noise-dominated, and that every shutdown attempt in the record aborted at least once before succeeding — both at n = 2 (§6.1).

**Not established:**
- **Why** capacity fell. §4.5 gives ranked candidates and §4.6 narrows them; none is confirmed. The decisive test is Open Item 14a, a matched-load repeat.
- The true peak recharge current. AC return was observed by nothing (§7.1); 4.4465 A is a **lower bound**.
- Pack state of charge at test start. ~~No instrument on this system confirms a completed charge (§4.5) — "started full" is [I], not [M], and always has been.~~ **r3:** the fully-charged detector was ON for 3 h 51 m before this test's cut, and ON before the 08-31 comparison run too [M] — both began at the same float equilibrium. That is not a state-of-charge measurement, and the May reference predates the detector (§4.5 candidate 3).
- The margin at undiminished load. This outage's load fell mid-discharge because the shutdown fired (§6).
- ~~Root cause for `Last Onset Step Resistance` (Open Item 13) or `total_outages` (Open Item 9b).~~ **r3: neither was a defect** — both updated during this test (§8.2, §9.1).
- Whether the HDR-60-12 exceeded its nameplate or the load share was lower than modelled (§7.2, Open Item 17).

---

## 3. Discharge Curve — Full Ladder to LVD

The 2026-08-31 report §2.1 had measured only Plateau at the post-boost load and explicitly flagged Knee as extrapolated and Cliff as "not measured". This test closes that.

| Phase | Band | Interval timed | Duration | Avg. current |
| :--- | :---: | :--- | ---: | ---: |
| Settling | 13.00 – 13.15 V | — | **absent, < 5 s** [M] | ~1.9 A |
| Plateau | 12.65 – 13.00 V | 09:17:10 → 09:41:48 | 24 m 38 s | ~2.05 A [M] |
| Knee, HA running | 12.65 → ~12.61 V | 09:41:48 → 09:55:52 | 14 m 04 s | ~2.0 A [M] |
| Knee, HA down | ~12.61 → 12.40 V | 09:55:52 → 10:32:50 | 36 m 58 s | **~1.40 A** [M] |
| Cliff | 12.40 → 11.675 V | 10:32:50 → 10:47:18 | **14 m 28 s** [M] | 1.375 → 1.476 A |
| **Onset → LVD trip** | 12.955 → 11.675 V | 09:17:10 → 10:47:18 | **1 h 30 m 08 s** | 1.686 A mean [D] |

> **Correction to r1 (R13).** The r1 phase table labelled the Cliff band "12.40 – 11.80 V" but quoted 14 m 30 s, which is the interval to the **LVD trip** — 104 s past the 11.80 V crossing the label names. The band as labelled took 12 m 46 s [M]. The same construction inflated the r1 "Knee start to LVD" row. Both rows above now name the interval actually timed. A band and an interval are different quantities, and a phase table must not silently swap them.

**Two load regimes in one outage.** The graceful shutdown fired in mid-Knee, so this discharge ran at a *falling* load: ~2.05 A while HA was up, ~1.40 A for the remaining ~51 minutes. This is a materially different shape from the 05-06 run (constant ~1.18 A) and the 08-31/09-01 run (constant ~2.09 A). No phase duration from this test transfers to a constant-load scenario.

### 3.1 Settling — retrieved from InfluxDB, and there wasn't one

| Time (UTC) | V | I | Note |
| :--- | ---: | ---: | :--- |
| 13:16:55.57 | 13.2047 | +0.017 A | last clean float sample |
| 13:16:58 | — | — | `switch.ups_outlet` OFF |
| 13:17:00.64 | 13.0340 | −1.8725 A (13:17:01.88) | already below both the 13.15 V trip and the 13.00 V Settling floor |
| 13:17:05.57 | 12.9657 | −1.8930 A | |
| 13:17:10.64 | 12.9548 | −1.9367 A | `on_battery` ON |

At ~1.9 A onset, V fell from float through both the 13.15 V trip and the 13.00 V Settling/Plateau boundary **inside one 5 s InfluxDB sampling interval**. By the time `on_battery` registered, V was already 195 mV into Plateau.

**R18 bounds the claim.** The instrument samples at 5 s; the transition completed in under 5 s. This dataset establishes that Settling is *shorter than 5 s at this current* — it does not establish that Settling does not exist. Reporting "no Settling phase" as a property of the pack would be reporting the sampler's blind spot. The 08-31/09-01 tests saw the same thing at higher current; this test shows it also at lower current, which says the collapse is not purely a function of load magnitude across the range tested so far. Resolving it needs a faster capture than any instrument on this system provides.

### 3.2 Cliff current rise — constant-power is the best-supported model, and is not proven

r1 asserted the rising Cliff current was "consistent with the XB7's own switching supply drawing roughly constant power". Tested against the 14 Cliff-phase heartbeats [M]:

| Quantity | Result |
| :--- | :--- |
| V across Cliff | 12.391 → 11.730 (−661 mV, −5.34 %) |
| I across Cliff | 1.375 → 1.476 A (mean 1.4435, sd 0.0473, CV 3.27 %) |
| P across Cliff | 16.973 → 16.899 W (mean 17.444, sd 0.547, CV 3.13 %) |
| Fit dP/dV | +0.313 W/V, R² = 0.015, **t = +0.43**, n = 14 — indistinguishable from flat |
| Fit dI/dV | −0.0997 A/V, R² = 0.202, **t = −1.74**, n = 14, 95 % CI **[−0.225, +0.025]** |

Model predictions at the observed operating point: constant power gives dI/dV = −P/V² = **−0.119 A/V**; constant resistance gives +1/R = **+0.119 A/V**; constant current gives 0.

**Verdict.** The confidence interval **excludes constant resistance**, contains constant power (the point estimate sits essentially on it), and **cannot exclude constant current** at n = 14. Constant-power is the best-supported model and constant-resistance is ruled out, but this test does not establish the mechanism. r1 stated the mechanism without n or a test, which R17 does not permit.

---

## 4. Capacity — the principal finding

### 4.1 What was delivered, and how well it is known

| Quantity | This outage | Basis |
| :--- | ---: | :--- |
| Charge delivered | **2.5331 Ah** | [M] firmware coulomb counter, NVS |
| Energy delivered | **31.821 Wh** | [M] same |
| Mean discharge current | 1.686 A | [D] 2.5331 Ah ÷ 1.5022 h |
| Pack nameplate | 10 Ah | [S] Cyclenbatt 10 Ah LiFePO4 |
| Fraction of nameplate | **25.3 %** | [D] |

**The counter is trustworthy, and this is the first time that has been demonstrated rather than assumed.** Three independent checks:

1. **Two-path cross-check.** At 09:34:14 the HA poller captured the firmware's own counter at **0.5789 Ah** while HA's recorder was independently writing current to InfluxDB. Trapezoidal integration of the InfluxDB series over 09:17:00 → 09:34:14 (n = 206 samples) gives **0.5844 Ah** — a difference of **+5.5 mAh, +0.95 %** [D]. Two storage paths, two clocks, one sensor.
2. **Integrator arithmetic.** Over 10:06:36 → 10:46:28 (n = 41 heartbeats) the counter advanced 0.9409 Ah against 0.9410 Ah by trapezoid on its own published current — **+0.010 %**; Wh **−0.120 %** [D].
3. **The unobserved window closes.** No instrument covered 09:54:31 → 10:06:36 (§10.1). By difference against the counter, that 12.1-minute window must hold 0.2876 Ah → an implied mean of **1.428 A** [D]. The independently measured post-shutdown load is ~1.40 A. A 12-minute hole that nobody watched reconciles to the load measured on either side of it.

> **Correction to r1 (R13).** The r1 Abstract tagged this figure "[M, firmware-published and independently cross-checked]" while r1 §2.2 stated the agreement was "rather than an independent confirmation of either figure." The Abstract outranked its own section, which the project's verdict-vocabulary rule forbids. The cross-check above is the one r1 should have run; the data for it was already sitting in `ha_poller_log.txt`.

**Limit (R18).** All three checks share one sensor. They establish that the INA260's output is transported, integrated and stored correctly; they say nothing about its absolute accuracy. An absolute check needs a second current reference, which this system does not have.

### 4.2 The reference figure is a measurement, not a rating

The live dashboard carries 4.18 Ah / 53.3 Wh as "rated capacity". It is neither rated nor current: it is the **2026-05-06 coulomb count** [S, `UPS_Report_2026-05-06.md` §3.2], dated May on the dashboard. Every "% of capacity" figure this project has published since — including r1's headline "60.6 % of rated capacity" — is a ratio against one four-month-old measurement of the same pack.

That framing hid the finding. Restated against fixed references:

| Run | Ah delivered | % of 10 Ah nameplate | Load | Endpoint |
| :--- | ---: | ---: | ---: | :--- |
| 2026-05-06 | 4.179 | 41.8 % | ~1.18 A | BP-65 LVD |
| 2026-08-31/09-01 | 1.833 | 18.3 % | ~2.09 A | stopped at 12.565 V |
| **2026-09-15** | **2.5331** | **25.3 %** | 1.69 A mean | BP-65 LVD |

The May report's own §4.3 already establishes why none of these approaches the nameplate: the 13.3 V float ceiling leaves ~3.5 Ah permanently inaccessible at the top, and recovering it would need a 14.4 V absorption charger. That is architectural and documented. **It is not what changed between May and September.**

### 4.3 The load-matched, span-matched comparison

The 08-31/09-01 test ran fourteen days before this one, at essentially the same current, over a voltage span this test also traverses. That is the cleanest available comparison: no rate correction is required, because there is no material rate difference to correct.

| | 2026-08-31/09-01 | 2026-09-15 | Δ |
| :--- | ---: | ---: | ---: |
| Voltage span | 12.97 → 12.565 V | 13.034 → 12.546 V | matched |
| Mean current | 2.089 A | **2.043 A** [M] | −2.2 % |
| Elapsed | 54 min | **31.0 min** [M] | **−42.6 %** |
| Charge delivered | 1.833 Ah | **1.0559 Ah** [M, n = 371] | **−42.4 %** |
| Energy delivered | 23.369 Wh | **13.4394 Wh** [M] | **−42.5 %** |

**Ah and Wh agree to a tenth of a point.** That matters: a voltage-measurement fault would move Wh without moving Ah. Their agreement, combined with §4.1's two-path check, places the shortfall in the pack rather than in the instrument.

**Provenance: now [M], not [S] — Open Item 15 closed.** The 08-31/09-01 figures have been re-derived from the raw InfluxDB series for this revision: **1.8316 Ah / 23.316 Wh**, against the 08-31 report's 1.833 Ah / 23.369 Wh — **−0.1 % Ah, −0.2 % Wh**. The 2026-08-29 test re-derives the same way (**0.4731 Ah** against that report's 0.4745 Ah, **−0.3 %**). Both endpoints of this comparison are therefore measured, and the prior report's arithmetic is independently confirmed.

> **Warning for anyone re-running these queries — see §10.5.** The InfluxDB measurements `A`, `V` and `W` are **shared across every entity carrying that unit**: 19 entities in `A`, 24 in `V`, including the separate 500 Ah `battery_bank_monitor_*` pack and `ups_outlet_current`. An unfiltered query returns a mixture of them. Every figure above filters `entity_id`.

Against the LVD-to-LVD comparison with May: **−39.4 % Ah, −40.3 % Wh** over 4.3 months.

### 4.4 What does not explain it

Each candidate quantified against the ~1.65 Ah (LVD-to-LVD) and ~0.78 Ah (span-matched) gaps.

| Mechanism | Magnitude | Verdict |
| :--- | ---: | :--- |
| **Rate effect at the LVD endpoint.** The LVD terminates at a fixed *loaded* 11.80 V, so higher current terminates at higher OCV. ΔI vs May at the Cliff = 0.28 A; Ri spans 93–260 mΩ across every method available (§8.3) → ΔV = 26–73 mV; local cliff slope **2.02 V/Ah** [M] | **0.013 – 0.036 Ah** | ≤ 2.2 % of the LVD gap |
| **Peukert.** Solving 4.179 / 2.5331 = (1.686 / 1.177)^(k−1) | requires **k = 2.40** [D] | LiFePO4 is 1.01–1.05; lead-acid ~1.25. Excluded |
| **Float-ceiling droop.** Pre-outage float 13.2047 V [M] vs 13.1970 V post-boost mean [M, 08-31 §1] — no material change. Charge-side slope near the ceiling ≈ 3.2 Ah/V [D, from 05-06 §4.3: 3.5 Ah between 13.3 V and 14.4 V] | **≤ 0.11 Ah** | ≤ 6.7 % |
| **Temperature.** 77.3–78.2 °F this run [M]; 75.7–81.5 °F in May [M, 05-06 §3.6] | ~0 | Both inside the LFP flat-response zone (±2 % from ~10–35 °C) |
| **Instrumentation change.** INA260 has been the sensor since before the May run [S, 05-06 §1]; the boost draws from the BP-65 load output, inside the measured path [M, owner-confirmed, 08-31 §3] | 0 | Measurement path unchanged |
| **Combined** | **≤ 0.16 Ah** | **≤ 9.7 % of the LVD gap; ~0 % of the load-matched gap** |

**The 08-31 report predicted this and is falsified by it.** Its §2 stated: *"Delivered Ah at 2.089 A is expected lower by ~0.13 Ah, 3 % of 4.18 Ah, which is not measured."* Measured now: −42.4 % at matched load. That prediction used a cliff slope of ~1.8 V/Ah; this test independently measures **2.02 V/Ah** [M], so the prediction's arithmetic was sound and its *premise* — that only the rate effect had changed — was wrong. Recorded here because this is where the falsifying measurement was made.
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

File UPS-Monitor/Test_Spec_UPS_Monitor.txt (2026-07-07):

---

# Test Specification – UPS Monitor Board (T-5P2W969574A)
**For JLCPCB Flying Probe Test & Function Test**
**Quantity:** 2 prototype boards
**Date:** April 14, 2026

---

## Part 1 – Flying Probe Test Information

Flying probe testing verifies no shorts or opens on the bare PCB *before* assembly. JLCPCB will run this automatically using the Gerber netlist. No custom test points are required – the standard PCB layout has sufficient vias and pads.

**Instructions to JLCPCB:**
- Use the original Gerber files to generate the flying probe program.
- Test all nets for continuity (opens) and isolation (shorts).
- Minimum test pad size: 0.5mm diameter (present on all nets).
- If any failure is detected, stop and notify me before proceeding.

**No additional test point file is needed** – the Gerber netlist is sufficient.

---

## Part 2 – Function Test Procedure (After Assembly)

Perform this test on **each assembled board** after soldering and visual inspection.
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

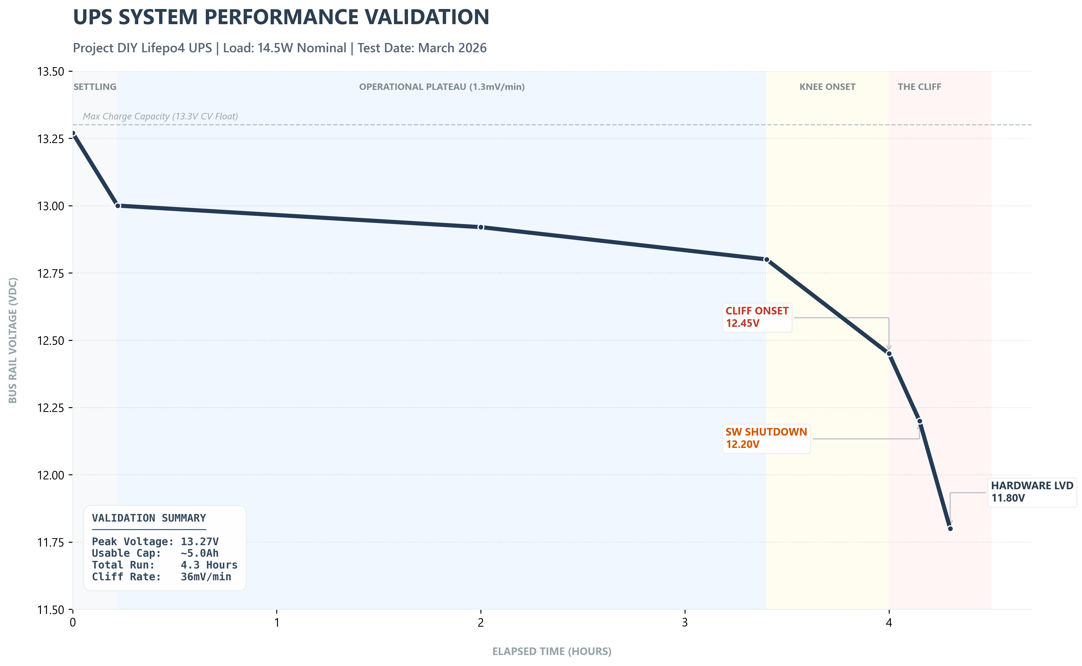
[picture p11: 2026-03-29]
assets/UPS_D3_Validation_2026.png.png

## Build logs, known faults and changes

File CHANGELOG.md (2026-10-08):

# Changelog

All notable changes to this project will be documented in this file.

The format is based on [Keep a Changelog](https://keepachangelog.com/en/1.1.0/).

---

## [Unreleased]

### Pending
- Physical build and assembly
- Home Assistant automation documentation
- Runtime validation testing

---

## [2026-10-08] — 2026-10-08

### Added
- `Top-Off-Charger/pcb/Top Off Charger- Oct 2026.pcb-eval.json` (35c07cc): this board's profile for the Tools repo's pcb-eval tools (netdrop, gnd_drop, dump, tracknet). Since Tools 077054a those tools hold no board's pads and refuse a board without a profile. It names the pads they held until 2026-10-08. Run on this board with no flag, they print the same figures as before apart from the profile line (whole GND pour 1.9645 mΩ [M, h = 0.1 mm]).

### Changed
- `Top-Off-Charger/pcb/`: the owner's 2026-10-08 11:00:58 save, rev 0.8, replaces the 17:09:17 one (e27eeab). VIN+ is re-routed on B.Cu and the power path is wider; TB1 moved 4.5 mm down so its labels can be read with U4 seated; the LED is on the left edge. All checks ran on the 10:48:22 save; the 11:00 save adds only U1's 3D models and its DRC set is identical. DRC 0 errors / 34 warnings / 0 unconnected [M, kicad-cli DRC with the board's own rules]. Schematic parity did not run (no schematic).
- `Top-Off-Charger/top-off-charger-design.md` rev 0.8 (e27eeab): §6.4's charge-path track resistance 37.33 → 12.17 mΩ [D, 2-D solve, §6.4]; §5.1 and §5.5 for the TB1 and LED moves, with the polarity table rewritten; §7, §7.3 and §7.4 for the rev 0.8 gate verdicts, pour and Kelvin figures, and an R13 record of a review session's 2026-10-06 edits to the board. O12 and O15 closed; O11, O13, O14 and O16 revised. The Gerbers are still to be exported (O11). §7 also gives the LF sha256 git stores for each board file beside the CRLF one KiCad writes (1ef6daa).

### Fixed
- `Top-Off-Charger/pcb/gnd_drop.py` (2389987): from the 2026-10-07 19:09 save on, TB2-2's enlarged pad covers the net tie's GND pad, and the tie's per-pad line read another node's voltage. It printed a Kelvin residual of 0.24–0.26 mΩ [D, false] where the solve gives 0.0000. A pad that loses all its copper to a later pad is now numbered last, and a pad left with no node is refused (O16(b)). Saves from 2026-10-06 15:16 to 22:29 give the same per-pad values as before [M, both scripts on all 17 saves, `--h 0.1`].
- R13, 2026-10-08: e27eeab, 1ef6daa and 2389987 shipped without these entries. They were added afterwards, in a commit of their own.

### Removed
- `Top-Off-Charger/pcb/gnd_drop.py`: moved to the Tools repo as `pcb-eval/solve/gnd_drop.py` (Tools cefe8a0, byte-identical to 2389987), with the other board review tools. Since Tools e6c198f the board file is a required argument; its default was the board beside the script. Design doc §7.3 and §7.4 point there.

---

## [2026-10-06] — 2026-10-06

### Changed
- `Top-Off-Charger/pcb/`: the owner's re-laid board, `Top Off Charger- Oct 2026.kicad_pcb` (saved 2026-10-06 15:16:19; 29.5 × 78 mm, was 31.5 × 95), and its `.kicad_pro` replace v7. The `.kicad_pro` differs only in the default pad width for new pads and the last plot path, so the design rules are unchanged. DRC gives 0 errors, 26 warnings (all silk or library) and 0 unconnected; schematic parity did not run, as there is no schematic. The Gerbers have not been exported from this layout.
- `Top-Off-Charger/top-off-charger-design.md` rev 0.7, for that layout. TB1's pins are swapped, so the PSU's +V lands on the lower screw. The terminal blocks are named as Phoenix 5442756 (O9 closed). The LED moved and turned 180°, XIAO D6/D7 became unplated holes, and three signals moved to B.Cu. The assembly order is set for the parts under the modules. §7.3 compares the electrical figures with rev 0.6, including what the B.Cu tracks cost the ground pour. Its §15 lists the changes.
- `Top-Off-Charger/pcb/`: the owner's 17:09:17 save of the same board replaces the 15:16:19 one. It adds a Kelvin GND: U2 pin 2 moves to a new net, GND_SENSE, joined to GND at TB2-2's pad by a net tie and a 0.5 mm track. DRC is unchanged: 0 errors, 26 warnings and 0 unconnected, the same 26 entries. The `.kicad_pro` differs only in the default size and drill of new pads.
- `Top-Off-Charger/top-off-charger-design.md`, still rev 0.7: the Kelvin GND takes the VBUS offset from 1.37–1.39 mV to ≤ 0.20 mV at 3.64 A (§5, §7.3). The lead is 24–30 in (owner), so §6.4's example now drops 58–73 mV at 3.64 A, not 146. New §7.4: the improvement study (Kelvin GND, a wider VIN+, 2 oz copper, a narrower +3V3, remote sense, a B.Cu VIN+), and the baseline and method for evaluating the owner's planned B.Cu VIN+ re-route (O15). O16 records the net tie's `REF**` reference and `gnd_drop.py` skipping R_shared without saying so.

### Fixed
- `Top-Off-Charger/top-off-charger-design.md` §7.3 and T10: the pour check probed TB2-2's screw. That adds the terminal's own clamp-to-pin drop, which is not measured and could trip the 1.5 mV threshold on a sound board. It now probes the solder joints, with new figures (R13 note at the site).
- `Top-Off-Charger/pcb/gnd_drop.py`: it took pad 2 of each terminal block as the GND pads. On the rev 0.7 board TB1's GND is pad 1, so it stopped with "expected two terminal-block GND pads". It now finds TB2's and TB1's GND pads by reference and net (R13 note at the site). `--self-test` adds a third direction: a board with no TB2 must be refused. Re-run on rev 0.6's v7, it reproduces the doc's rev 0.6 figures exactly.

---

## [2026-10-03] — 2026-10-03

### Added
- `Top-Off-Charger/pcb/`: the owner's charger board, `Top Off Charger- Oct 2026.kicad_pcb` (KiCad 10, v7 saved 2026-10-03 22:42:18), and its `.kicad_pro` design rules. DRC with those rules gives 0 errors, 26 warnings (all silk or library) and 0 unconnected. Schematic parity did not run, as there is no schematic. The `.kicad_prl` (per-user view state) is not committed, and the Gerbers are not exported yet.
- `Top-Off-Charger/pcb/gnd_drop.py`: a finite-difference solver for the voltage drop across the GND pour, which the design doc's §7.3 uses. `--self-test` checks it against a uniform strip with an exact answer and confirms that a pour cut in two is refused.

### Changed
- `Top-Off-Charger/top-off-charger-design.md` rev 0.6: a purpose-built board (§7) replaces the reuse of the V2 board and the lever nuts. Screw terminals TB1/TB2 and board copper replace most of the loose wiring. The status LED moves to GPIO3 (D1), on a 3 mm footprint, with a call-out for which leg goes in which pad (§5.5). Other additions: staged first power (§5.4), a ground-pour drop analysis (§7.3, falsified by T10) and the board's parts (§13). T7 now holds SDA to GND instead of unplugging the INA228. Open items O11–O14 are new. Rev 0.5 had no CHANGELOG entry; this one does not backfill it.

---

## [2026-09-21] — 2026-09-21

### Added
- `Top-Off-Charger/top-off-charger-design.md` rev 0.3: a pre-build design for a bench top-off / top-balance charger for the Cyclenbatt, which is removed from the UPS for each session. Moved from `Lifepo4-Battery-Banks/Top-Off Charger/` (rev 0.2, `680caed`) and scoped to this pack only. It includes from/to wiring tables with Wago splice nodes. Nothing is built, and the firmware is not written.

### Changed
- `Top-Off-Charger/top-off-charger-design.md` rev 0.4: the series resistor Rs is withdrawn, so GPIO4 drives the switch's ON pin directly. A continuity check before first power and a 5 mA pin drive strength take over Rs's job. The pin-leakage figure is corrected (R13).

---

## [2026-03-06c] — 2026-03-06

### Changed
- Corrected total system load: ~13.8W → ~13.7W (13.17 + 0.50 + 0.02 = 13.69W)
- Clarified that DC values are estimates based on 82.5% assumed adapter efficiency
- Added "AC Measured" column to README performance table
- Updated terminology: "measured" → "estimated" for DC power values

---

## [2026-03-06b] — 2026-03-06

### Changed
- Updated combined power measurement: 74.1h test, 1.182 kWh, 15.96W AC / 13.17W DC
- Added peak load measurement: 21.4W AC / 17.66W DC
- Updated total system load estimate: ~13.7W DC (combined + Shelly + BP-65)
- Updated documentation in specs, design-rationale, supplemental-analysis

---

## [2026-03-06] — 2026-03-06

### Added
- Badges to README (license, status, runtime, switchover)
- Related Projects section linking to companion repositories
- CHANGELOG.md for version tracking

### Changed
- README header formatting with centered badges

---

## [2026-03-01] — 2026-03-01

### Added
- Combined system power measurement (13.68W DC typical)
- Extended power testing documentation

### Changed
- Updated runtime calculation based on combined load testing

---

## [2026-02-15] — 2026-02-15

### Added
- HA Green power measurement (0.73W DC typical, 2.56W DC peak)
- XB7 modem power measurement (12.14W DC typical, 16.75W DC peak)
- Kill-a-Watt testing methodology documentation

---

## [2026-01-15] — 2026-01-15

### Added
- Initial repository creation
- Complete design documentation
- Bill of materials with vendor links
- Wiring diagrams and specifications
- Design rationale and cost analysis
- Safety procedures
- Voltage drop analysis
- Thermal budget and FMEA
- System architecture diagrams

### Established
- MIT license
- Documentation structure in `/docs/`

---

## Version History Notes

This project uses date-based versioning (`YYYY-MM-DD`) based on significant milestones.

| Version | Milestone |
|:---|:---|
| 2026-03-06 | README badges and cross-links added |
| 2026-03-01 | Combined system power testing complete |
| 2026-02-15 | Individual device power measurements |
| 2026-01-15 | Initial design documentation |

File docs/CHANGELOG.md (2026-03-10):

# Changelog

All notable changes to this project will be documented in this file.

The format is based on [Keep a Changelog](https://keepachangelog.com/en/1.1.0/).

---

## [Unreleased]

### Pending
- Home Assistant automation documentation
- Runtime validation testing (build complete — validation in progress)

---

## [2026-03-10] — 2026-03-10

### Added
- Ventilation holes documented in supplemental-analysis.md: 3 × ¼″ intake (low, PSU wall) + 3 × ¼″ exhaust (high, BP-65 wall)
- Chimney airflow analysis: holes contribute ~0.05W cooling (~1.5% of 3.5W load) — wall conduction dominates at this heat level; ΔT unchanged at ~2.8°C
- IP65 → IP4X rating note added (holes compromise water-jet resistance; non-issue for indoor floor installation)
- Bare wall warts baseline added to cost-analysis.md: ~$41/yr / ~$410 over 10 years; DIY UPS adds only ~$5/yr vs doing nothing
- Battery longevity analysis added to supplemental-analysis.md: 1–2%/yr calendar aging → 10–20 year realistic lifespan at 13.3V float, 63–75°F

### Changed
- **PSU model corrected throughout:** LRS-100-12 → HDR-60-12 (all docs, README, block diagram, datasheet link)
- **Adapter efficiency methodology corrected:** 82.5% assumed → actual measured efficiencies (XB7: 88% DoE Level VI confirmed from adapter label NBC56B120460VU; HA Green: 85% assumed, not characterized)
- **DC load figures corrected:** 13.7W → 14.5W DC typical (XB7 12.9W + HA Green 1.1W + Shelly 0.5W + BP-65 0.018W)
- **Kill-a-Watt measurement updated:** final combined window 2.538 kWh / 158.8 hr = 16.0W avg, 23.0W peak (6 days 14h 50min); average confirmed stable across all measurement windows
- **XB7 standalone measurement note:** reformatted to consistent kWh/hr style: 1.066 kWh / 72.4 hr = 14.7W avg
- **Voltage envelope corrected:** 11.74–13.26V → 11.71–13.11V (2A worst-case) throughout all docs
- **Runtime corrected:** 8.2h → 7.8h (112.5Wh ÷ 14.5W DC); AC-based reference 7.0h added to footnotes
- **Battery lifespan updated:** 7–10 years → 10–20 years throughout all docs
- **Annual electricity corrected:** $41/yr → $46/yr (14.5W DC ÷ 81% PSU efficiency × 8760h × $0.29/kWh)
- **BOM corrected:** 2-in-4-out terminal block replaced with Wago 221-415 lever nuts (10-pack); cost unchanged
- **Voltage drop analysis:** terminal blocks + butt splice → Wago lever nuts; Path 1 segment count corrected to 6; total resistance 40mΩ → 47.1mΩ; currents updated to 1.2A typical / 2.0A worst-case
- **Peak power updated:** 21.5W → 23.0W AC peak (measured); 19.5W → 20.2W DC peak (derived)
- **Thermal analysis:** heat load updated 2.1W → 3.5W; ΔT 1.7°C → 2.8°C; PSU efficiency at operating point corrected to 81%
- **README status:** components ordered/received ✓; combined measurement ✓; separate HA Green baseline item removed; build in progress
- **10-year cost comparison:** DIY total updated ~$654 → ~$714; BE600M1 price corrected $75 → $85; honest context updated to "roughly the same cost"

---

## [2026-03-06c] — 2026-03-06

### Changed
- Corrected total system load: ~13.8W → ~13.7W (13.17 + 0.50 + 0.02 = 13.69W)
- Clarified that DC values are estimates based on 82.5% assumed adapter efficiency
- Added "AC Measured" column to README performance table
- Updated terminology: "measured" → "estimated" for DC power values

---

## [2026-03-06b] — 2026-03-06

### Changed
- Updated combined power measurement: 74.1h test, 1.182 kWh, 15.96W AC / 13.17W DC
- Added peak load measurement: 21.4W AC / 17.66W DC
- Updated total system load estimate: ~13.7W DC (combined + Shelly + BP-65)
- Updated documentation in specs, design-rationale, supplemental-analysis

---

## [2026-03-06] — 2026-03-06

### Added
- Badges to README (license, status, runtime, switchover)
- Related Projects section linking to companion repositories
- CHANGELOG.md for version tracking

### Changed
- README header formatting with centered badges

---

## [2026-03-01] — 2026-03-01

### Added
- Combined system power measurement (13.68W DC typical)
- Extended power testing documentation

### Changed
- Updated runtime calculation based on combined load testing

---

## [2026-02-15] — 2026-02-15

### Added
- HA Green power measurement (0.73W DC typical, 2.56W DC peak)
- XB7 modem power measurement (12.14W DC typical, 16.75W DC peak)
- Kill-a-Watt testing methodology documentation

---

## [2026-01-15] — 2026-01-15

### Added
- Initial repository creation
- Complete design documentation
- Bill of materials with vendor links
- Wiring diagrams and specifications
- Design rationale and cost analysis
- Safety procedures
- Voltage drop analysis
- Thermal budget and FMEA
- System architecture diagrams

### Established
- MIT license
- Documentation structure in `/docs/`

---

## Version History Notes

This project uses date-based versioning (`YYYY-MM-DD`) based on significant milestones.

| Version | Milestone |
|:---|:---|
| 2026-03-10 | Build complete; all measurements finalized; documentation corrected |
| 2026-03-06 | README badges and cross-links added |
| 2026-03-01 | Combined system power testing complete |
| 2026-02-15 | Individual device power measurements |
| 2026-01-15 | Initial design documentation |

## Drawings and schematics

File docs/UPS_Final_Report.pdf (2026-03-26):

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

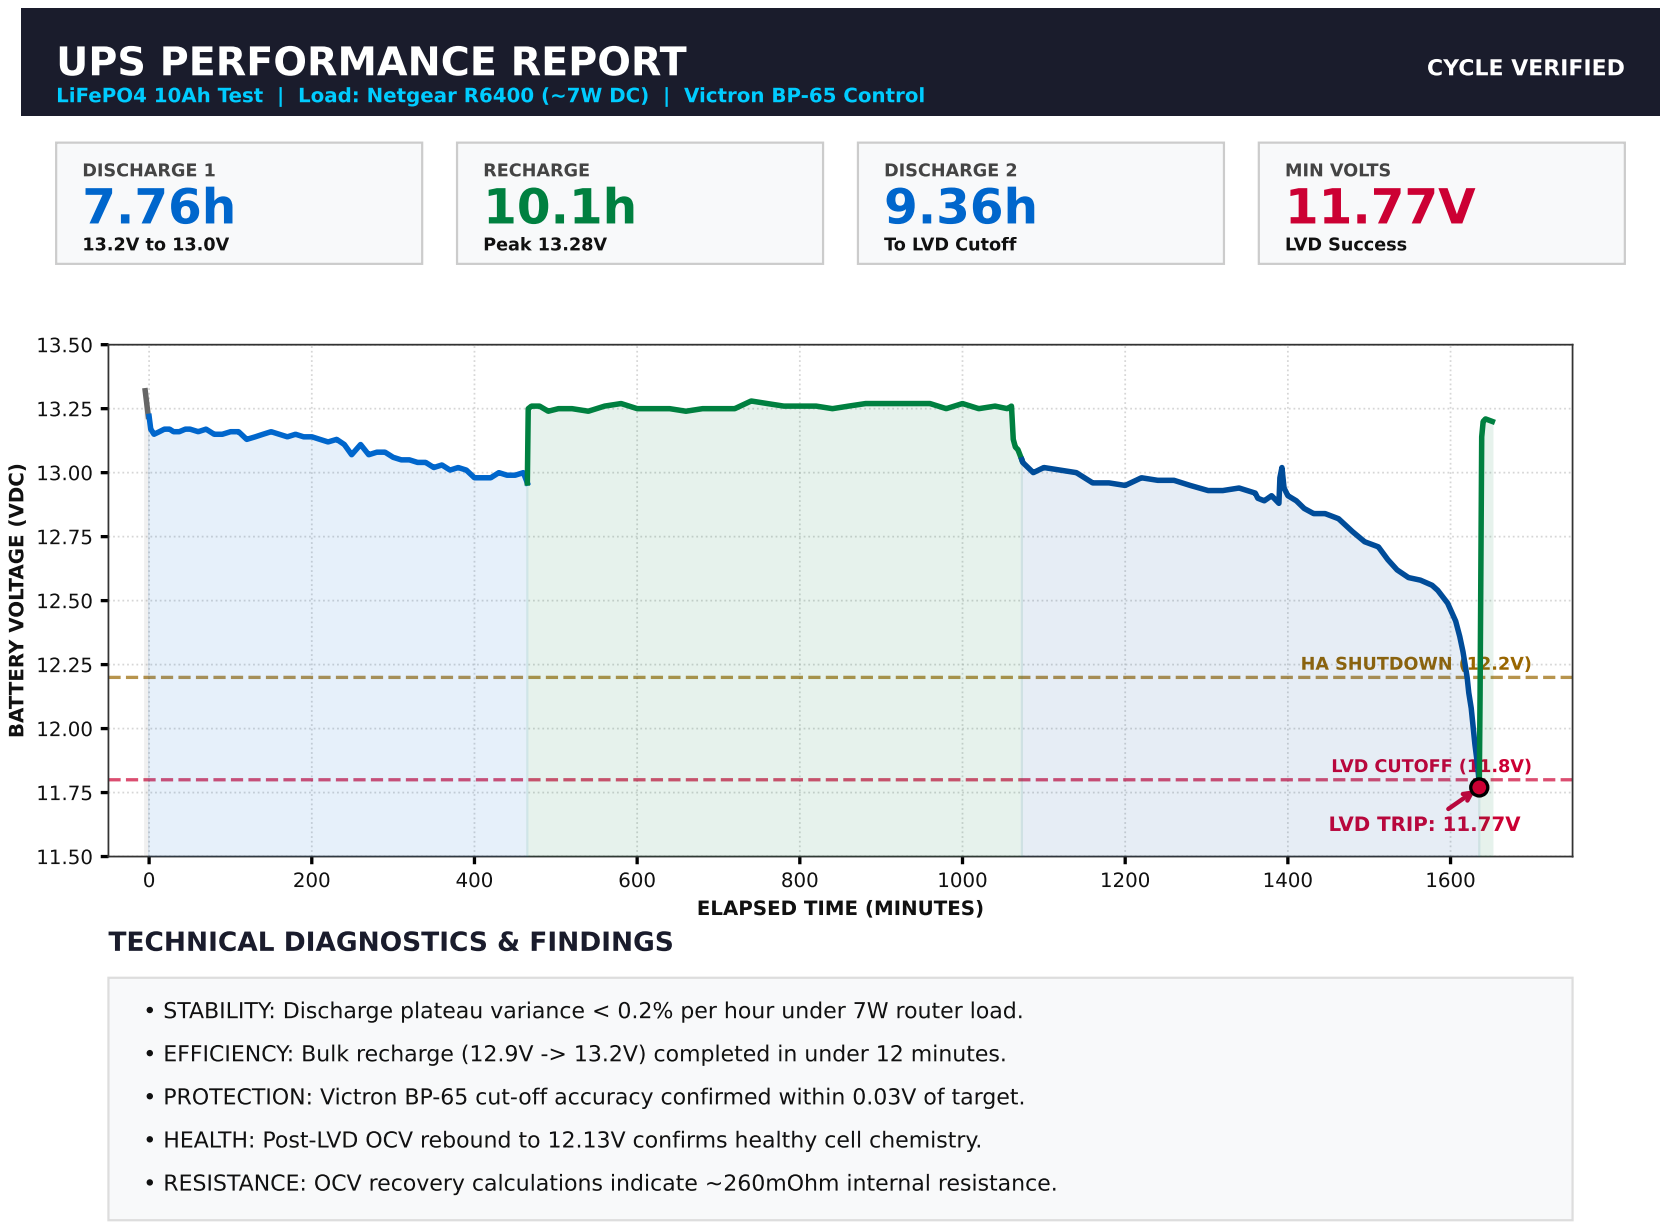
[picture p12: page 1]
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

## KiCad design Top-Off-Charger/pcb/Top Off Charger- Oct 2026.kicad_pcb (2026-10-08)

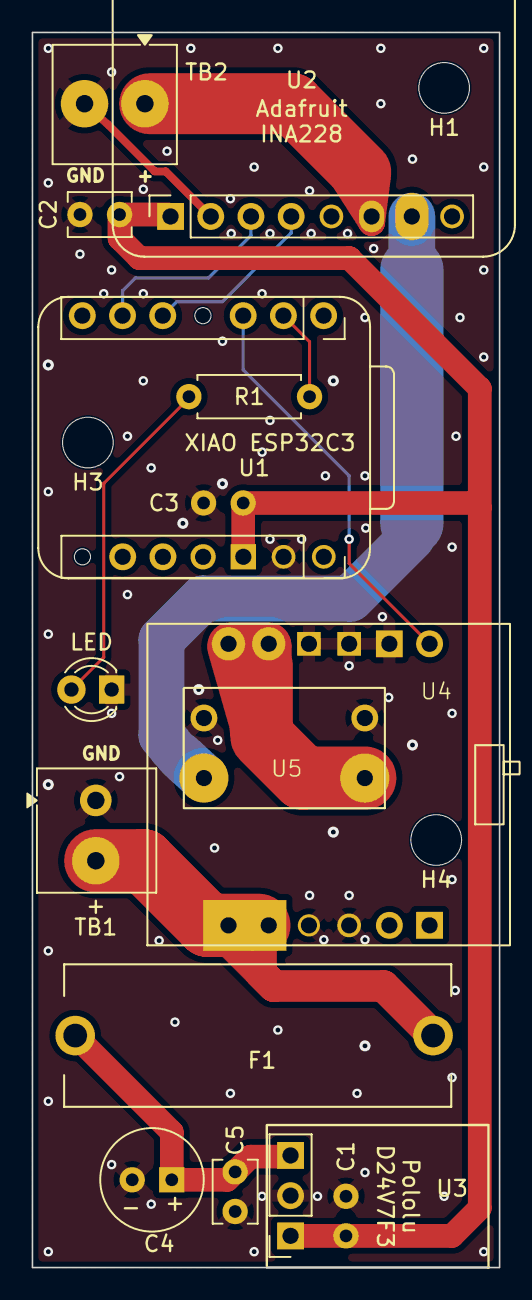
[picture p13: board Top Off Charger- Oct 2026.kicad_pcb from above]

Board: 2 copper layers, 29.5 x 78.0 mm, 19 parts (0 on the bottom side), 13 nets.

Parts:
C1: CAP CER 10UF 10% 25V X7R RADIAL, FG18X5R1E106MRT00; C_Disc_D5.0mm_W2.5mm_P2.50mm
C2, C3, C5: CAP CER 0.1UF 50V X7R RADIAL, K104K10X7RF53L2; C_Disc_D3.8mm_W2.6mm_P2.50mm
C4: CAP ALUM 47UF 20% 50V RADIAL TH, EEU-FR1H470; C_Radial_D6.3mm_H11.0mm_P2.50mm
F1: FUSEHOLDER BLOCKS - PCB - CLIP C, 696108003002; Wuerth_696108003002
H1, H3, H4: M3; MountingHole_3.2mm_M3
LED: LED GREEN DIFFUSED T/H LED_D5.0mm - LTL-4231N; LED_D3.0mm
NT1: NetTie-2_SMD_Pad0.5mm
R1: 1 kOhms ±5% 0.25W, 1/4W Through Hole Resistor Axi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; R_Axial_DIN0207_L6.3mm_D2.5mm_P7.62mm_Horizontal
TB1, TB2: TERM BLK 2P SIDE ENT 3.81MM PCB, 5442756; TerminalBlock_Phoenix_MKDS-1-2-3.81_1x02_P3.81mm_Horizontal
U1: Xiao ESP32C3; XIAO ESP32C3
U2: Adafruit INA228 5832; Adafruit INA228
U3: Pololu D24V7F3; PinSocket_1x03_P2.54mm_Vertical
U4: Big MOSFET Slide Switch with Reverse Voltage Prot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; Pololu Mosfet Switch
U5: Pololu Ideal Diode Reverse Voltage Protector, 4-6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; Pololu Ideal Diode 5382

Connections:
+3V3: C1.1, C2.2, C3.2, U1.3V3, U2.1, U3.1
BATT_RAW: F1.1, TB1.2, U4.11, U4.12
Batt_SW: U4.5, U4.6, U5.1
GND: C1.2, C2.1, C3.1, C4.2, C5.1, LED.1, NT1.1, TB1.1, TB2.2, U1.GND, U3.2, U4.2, U4.3, U4.4, U4.9, U4.10, U5.2, U5.4
GND_SENSE: NT1.2, U2.2
GPIO3: R1.1, U1.D1
GPIO3_LED: LED.2, R1.2
GPIO4_SW: U1.D2, U4.1
SCL: U1.SCL, U2.3
SDA: U1.SDA, U2.4
VIN+: U2.7, U5.3
VIN-: TB2.1, U2.6
V_Fused: C4.1, C5.2, F1.2, U3.3

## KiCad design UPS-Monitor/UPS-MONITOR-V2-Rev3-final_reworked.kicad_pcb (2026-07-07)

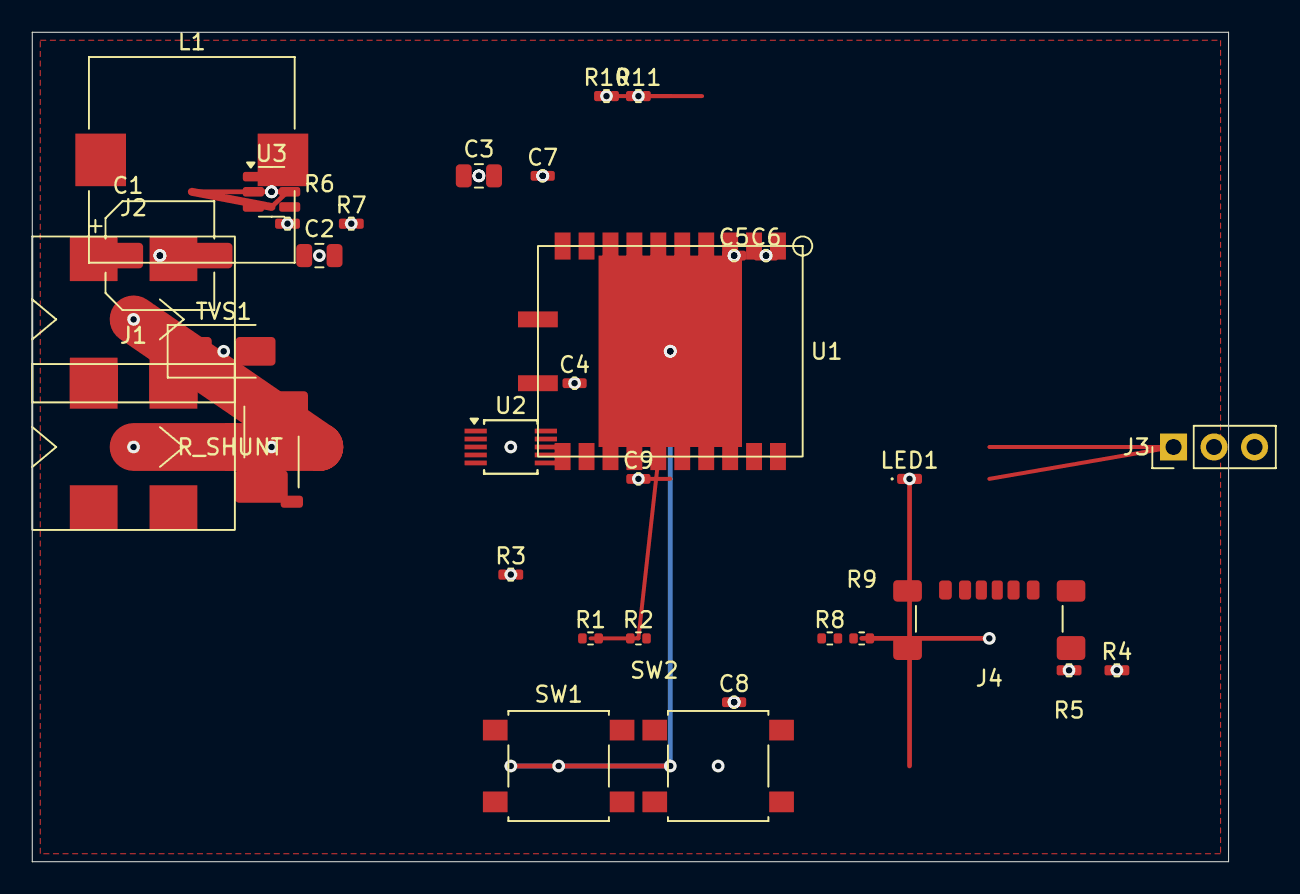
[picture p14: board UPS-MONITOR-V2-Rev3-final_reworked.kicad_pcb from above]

Board: 4 copper layers, 75.0 x 52.0 mm, 33 parts (0 on the bottom side), 19 nets.

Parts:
C1: 100uF 25V; C1
C2: 10uF 25V; C2
C3: 22uF 10V; C3
C4: 100nF; C4
C5: 100nF; C5
C6: 100nF; C6
C7: 100nF; C7
C8: 1uF; C8
C9: 100nF; C9
J1: BATT_IN; J1
J2: LOAD_OUT; J2
J3: PinHeader 1x03; J3
J4: USB4135-GF-A; J4
L1: 4.7uH IHLP-5050; L1
LED1: Blue 0402; LED1
R1: 4.7k; R1
R2: 4.7k; R2
R3: 10k; R3
R4: 100R; R4
R5: 10R; R5
R6: 210k; R6
R7: 68k; R7
R8: 10k; R8
R9: 4.7k; R9
R10: 5.1k; R10
R11: 5.1k; R11
R_SHUNT: WSLT2512R0100FEA; R_SHUNT
SW1: B3S-1000; SW1
SW2: B3S-1000; SW2
TVS1: SMAJ15CA; TVS1
U1: ESP32-C3-MINI-1-N4; U1
U2: INA228AIDGST; U2
U3: AP63203WU-7; U3

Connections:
+3V3: C3.1, C4.1, C5.1, C6.1, C7.1, J3.1, L1.2, LED1.2, R1.1, R2.1, R4.1, R6.1, R8.1, R9.1, U1.2, U2.10
BATT_IN: J1.1, R_SHUNT.1, TVS1.2
BOOT_N: SW1.1, U1.13
DS18B20: J3.2, R9.2, U1.4
EN_RC: C8.1, R8.2, SW2.1, U1.16
FB_BUCK: R6.2, R7.1, U3.3
GND: C1.1, C2.2, C3.2, C4.2, C5.2, C6.2, C7.2, C8.2, C9.2, J1.2, J2.2, J3.3, J4.S1, R3.1, R3.2, R7.2, R10.2, R11.2, SW1.2, SW2.2, TVS1.1, U1.1, U1.3, U1.6, U1.7, U1.9, U1.10, U1.11, U1.17, U1.18, U1.19, U1.20, U1.21, U1.22, U1.GND, U2.1, U2.4, U2.5, U2.6, U3.2
LED_K: LED1.1, R4.2, U1.5
LOAD_OUT: C1.2, C2.1, J2.1, J4.A9, J4.B9, R5.1, R_SHUNT.4, U3.4, U3.5, U3.6
SCL: R2.2, U1.12, U2.7
SDA: R1.2, U1.8, U2.8
SHUNT_HI: R_SHUNT.2, U2.3
SHUNT_LO: R_SHUNT.3, U2.2
SW_BUCK: L1.1, U3.1
USB_CC1: J4.A12, R10.1
USB_CC2: J4.B12, R11.1
USB_DM: J4.A5, U1.14
USB_DP: J4.B5, U1.15
VBUS_FILT: C9.1, R5.2, U2.9

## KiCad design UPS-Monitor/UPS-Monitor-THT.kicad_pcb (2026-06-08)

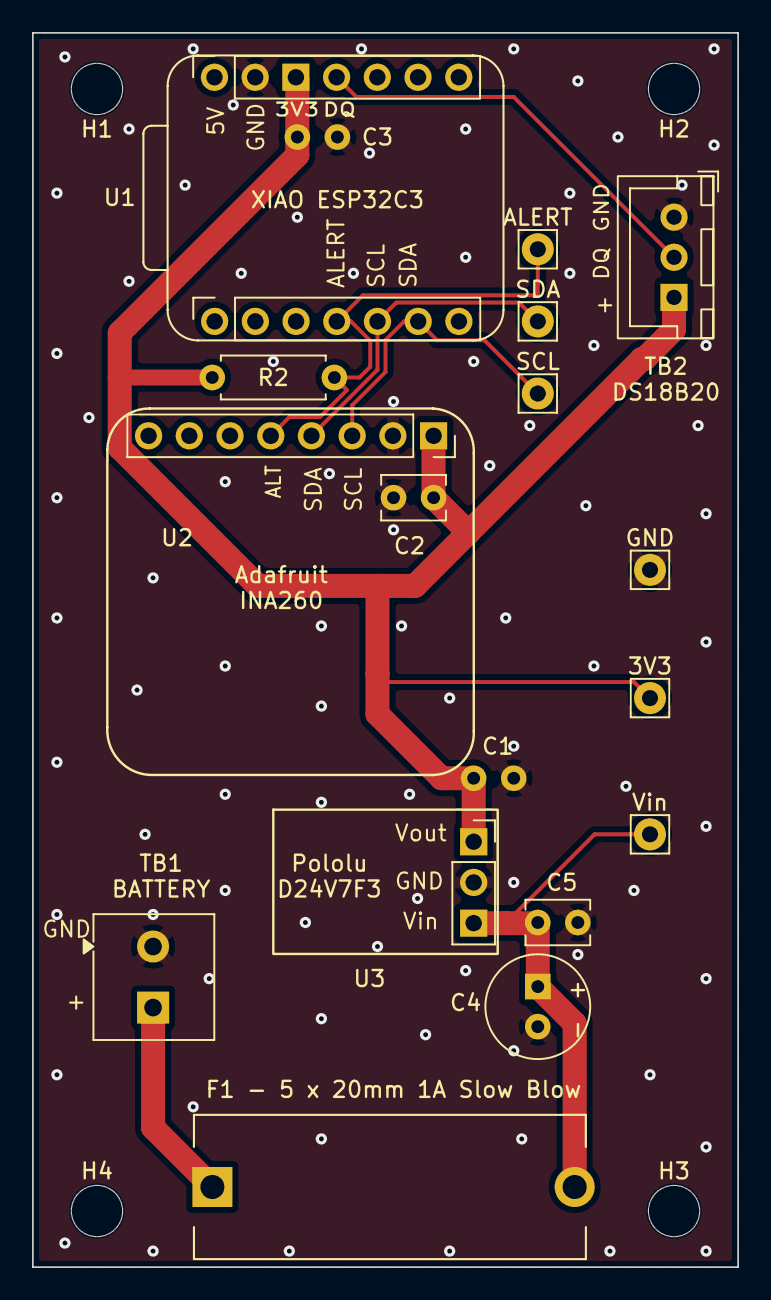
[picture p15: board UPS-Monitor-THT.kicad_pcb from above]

Board: 2 copper layers, 44.0 x 77.0 mm, 22 parts (0 on the bottom side), 8 nets.

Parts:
3V3: TestPoint_THTPad_2.0x2.0mm_Drill1.0mm
ALERT: TestPoint_THTPad_2.0x2.0mm_Drill1.0mm
C1: C_Disc_D5.0mm_W2.5mm_P2.50mm
C2, C3, C5: 0.1uF cer 50V; C_Disc_D3.8mm_W2.6mm_P2.50mm
C4: C_Radial_D6.3mm_H11.0mm_P2.50mm
F1: 1A SB Wurth 696108003002; Wuerth_696108003002
GND: TestPoint_THTPad_2.0x2.0mm_Drill1.0mm
H1, H2, H3, H4: M3; MountingHole_3.2mm_M3
R2: R_Axial_DIN0207_L6.3mm_D2.5mm_P7.62mm_Horizontal
SCL: TestPoint_THTPad_2.0x2.0mm_Drill1.0mm
SDA: TestPoint_THTPad_2.0x2.0mm_Drill1.0mm
TB1: TerminalBlock_Phoenix_MKDS-1-2-3.81_1x02_P3.81mm_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; TerminalBlock_Phoenix_MKDS-1-2-3.81_1x02_P3.81mm_Horizontal
TB2: JST_XH_B3B-XH-A_1x03_P2.50mm_Vertical
U1: Xiao ESP32C3; XIAO ESP32C3
U2: INA260/INA228; PinSocket_1x08_P2.54mm_Vertical
U3: Pololu D24V7F3; PinSocket_1x03_P2.54mm_Vertical
Vin: TestPoint_THTPad_2.0x2.0mm_Drill1.0mm

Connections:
+3V3: 3V3.1, C1.1, C2.2, C3.2, R2.2, TB2.3, U1.3V3, U2.1, U3.1
BATT_RAW: F1.1, TB1.2
GND: C1.2, C2.1, C3.1, C4.2, C5.1, GND.1, TB1.1, TB2.1, U1.GND, U2.2, U3.2
GPIO3_ALERT: ALERT.1, R2.1, U1.GPIO3, U2.5
GPIO10_DQ: TB2.2, U1.GPIO10
SCL: SCL.1, U1.SCL, U2.3
SDA: SDA.1, U1.SDA, U2.4
VIN: C4.1, C5.2, F1.2, U3.3, Vin.1

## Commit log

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2026-03-06 Fix documentation inconsistencies and adjust cost messaging
    Calculation fixes:
    - Correct voltage drop at peak: 0.069V → 0.063V (1.582A × 0.040Ω)
    - Update minimum device voltage: 11.73V → 11.74V throughout
    - Fix wall draw calculation: 15.39W → 15.7W (13.68W ÷ 0.87)
    - Standardize runtime milestones on 13.68W measured load
    Messaging adjustments:
    - Tone down cost savings claims — economics are marginal vs commercial UPS
    - Emphasize technical benefits: <1ms switchover, 3× runtime, HA integration
    - Add explicit "don't expect cost savings" guidance
    Other fixes:
    - Clarify ground wire handling: cut back to cable gland, capped
    - Add note explaining voltage envelope within ±10% tolerance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
2026-03-06 Fix peer review findings: consistency and accuracy corrections
    Issue 1 - Stale load figure:
    - Fix "13.39W" → "13.68W" in specifications.md and design-rationale.md row labels
    Issue 2 - Annual electricity cost error (HIGH PRIORITY):
    - Fix $46/yr → $40/yr in 10-year lifecycle table
    - Correct 10-year total: $714 → $654
    - This makes DIY essentially break-even with BE600M1 (~$655)
    Issue 3 - Thermal analysis residual:
    - Fix AC wall draw: 15.39W → 15.7W in supplemental-analysis.md
    Issue 4 - F1 fuse coordination:
    - Add design note: PSU internal OCP trips at ~5-6.75A; F1 provides backup
    Issue 5 - Enclosure dimensions:
    - Clarify BOM: exterior dims with interior noted
    Issue 6 - PSU efficien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
2026-03-07 Correct power values and clarify DC estimation methodology
    - Total system load: ~13.8W → ~13.7W (13.17 + 0.50 + 0.02 = 13.69W)
    - Added "AC Measured" column to README performance table
    - Clarified that DC values are estimates (AC × 82.5% assumed efficiency)
    - 82.5% efficiency is based on typical adapter behavior, not measured
    - Updated terminology: "measured" → "estimated" for DC power values
    - Updated specs, design-rationale, design-specification, supplemental-analysis
2026-03-07 Fix documentation inconsistencies
    - MTBF: Updated from ">500,000 hours" to "927,600 hours" per HDR-60-12 datasheet
    - Peak power: Clarified README shows device-only peak (17.66W), added total system peak (~18.7W)
    - Specifications: Made peak calculation explicit (17.66W + Shelly + BP-65 = 18.7W)
    Verified:
    - Cyclenbatt spelling is consistent throughout (all lowercase 'b')
    - All FMEA RPN calculations are mathematically correct
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2026-04-12 docs: add footprint verification report and critical BOM corrections
    CRITICAL FINDINGS:
    1. WAGO 2060-452 Footprint Mismatch:
    - BOM specifies WAGO 2060-452 (4.0mm pitch)
    - PCB footprint uses 5.0mm pitch
    - WAGO 2060-452 WILL NOT FIT the existing PCB
    - Solution: Use 5.08mm alternatives (KF2EDGR-5.08-2P or DG128-5.08-02P)
    2. Current Shunt BOM Error:
    - BOM claims WSLT2512 is "4-terminal Kelvin"
    - WSLT2512 is actually 2-terminal (per Vishay datasheet)
    - Corrected documentation and alternative compatibility
    Added FOOTPRINT-VERIFICATION-REPORT.md with detailed analysis based on:
    - KiCad PCB file extraction of actual footprint dimensions
    - Manufacturer datasheet comparisons
    -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
    [UPS-MONITOR-V2-Alternatives.csv]
2026-04-12 docs: add electrical compatibility analysis and critical inductor corrections
    ELECTRICAL COMPATIBILITY FINDINGS:
    Terminal Blocks (J1, J2):
    ✅ KF2EDGR-5.08-2P has BETTER specs than WAGO
    - 10A vs 9A current rating (11% higher)
    - 300V vs 320V (still 25x application voltage)
    - Wider wire gauge range (24-12 AWG vs 24-18 AWG)
    - ELECTRICALLY SUPERIOR
    Current Shunt (R_SHUNT):
    ✅ WSL2512R0100FEA IDENTICAL to WSLT2512R0100FEA
    - Same resistance: 10mΩ ±1%
    - Same TCR: ±75 ppm/°C
    - Same power: 1W
    - Only difference: temp range (170°C vs 275°C - both adequate)
    Buck Inductor (L1) - CRITICAL ISSUE:
    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
    [UPS-MONITOR-V2-Alternatives.csv]
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2026-04-12 docs: finalize USB4135-GF-A analysis and complete sourcing summary
    CRITICAL USB CONNECTOR FINDINGS (corrected understanding):
    USB4135-GF-A Specifications:
    - 6-pin power-only (NOT 16-pin full USB-C)
    - Fully SMT design (signal pins AND shell stakes surface mount)
    - GCT claims "only full SMT horizontal version on market"
    - Current: 3A VBUS, 4.25A GND
    - Unique proprietary footprint
    Why No Alternatives Exist:
    ❌ Most USB-C use through-hole shell mounting (footprint incompatible)
    ❌ Different pin configurations (power-only vs full 24-pin)
    ❌ Proprietary SMT shell stake positions (unique to GCT)
    ❌ Any substitute requires complete PCB redesign
    Recommendation: MUST use original GCT USB4135-GF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
    [UPS-MONITOR-V2-Alternatives.csv]
2026-04-12 CRITICAL BOM ERROR FIX: USB connector requires data pins for ESP32 programming
    PROBLEM IDENTIFIED:
    - BOM specifies USB4135-GF-A (6-pin power-only, no D+/D-)
    - ESP32-C3-MINI-1-N4 REQUIRES USB data pins for programming via built-in USB Serial/JTAG
    - PCB has USB_DM/USB_DP routed to connector pads A5/B5
    - USB4135-GF-A has NO pins at A5/B5 positions
    - Result: CANNOT program ESP32-C3 with specified connector!
    SOLUTION:
    - Replace USB4135-GF-A with USB4110-GF-A (16-pin USB 2.0)
    - USB4110-GF-A has D+/D- data pins at A5/B5
    - DROP-IN compatible (same GCT USB41xx family, fully SMT, same footprint)
    - Better specs: 5A VBUS vs 3A (67% improvement)
    FILES UPDATED:
    - USB-CONNECTOR-ANALYSIS.md: Complete rewr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
    [UPS-MONITOR-V2-Alternatives.csv]
2026-04-12 Updated and corrected component parts - terminal block, USB-C
    [UPS-MONITOR-V2-BOM-Rev3.1.csv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]
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2026-09-08 UPS-Monitor: single canonical config, credentials via !secret
    Replaces the versioned snapshots with one file matching what is actually
    flashed, taken from /config/esphome/ups-monitor.yaml.
    api key -> !secret api_key_ups_monitor
    ota -> !secret ota_password
    wifi -> !secret wifi_ssid / !secret wifi_password
    fallback -> !secret ap_password
    Also carries two things the repo snapshots never had: project metadata
    (wkcollis1.ups-monitor 1.19) and use_address, which fixes the ESPHome add-on
    showing the device offline because a container has no mDNS resolver. Drops
    build_path, which was a path on one Windows machine.
    The superseded revisions v1_12 through v1-16, v19_1, v1-17 an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
2026-09-15 Report r2: shutdown trigger is noise-dominated (n=2), close Open Item 15
    Adds SS6.1 and SS6.1.1, replays the deployed cliff_imminent logic against BOTH
    the 2026-09-01 and 2026-09-15 outages, and records two corrections made during
    this analysis rather than replacing them (R13).
    The trigger (SS6.1):
    - The voltage term is a GATE, not the trigger. On 09-15 it opened at 09:41:48
    and the trigger did not hold until 09:53:51 - twelve minutes later.
    - Firmware-published voltage_slope over each discharge window: 09-01 n=52,
    sd 18.7 mV/min, 21 crossings of the -10 mV/min threshold in 52 min; 09-15
    n=37, sd 24.0, 12 crossings. Noise sd is ~2x the threshold on both runs.
    - automation.ups_graceful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
2026-09-16 Report r2: correct the PSU overage figure, add AC-side cross-check (SS7.4)
    An earlier draft of r2 quoted the first post-recovery sample as 54.627 W into
    the battery branch and called it 101.2% of the HDR-60-12 nameplate, building
    Open Item 17 on it. The figure does not survive checking and is corrected here
    rather than replaced (R13).
    Why it was wrong:
    - Battery Power is a TEMPLATE computing V x I from the two published channels
    (ups-monitor.yaml:1613); the chip POWER register is internal-only and unused
    because it is unsigned. So this was never a register-vs-calculation mismatch.
    - Each ina260 channel carries its own throttle_average: 5s, which publishes
    when its OWN window closes, s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
2026-09-16 UPS-Monitor: firmware V1.20 - paired V/I blocks, windowed Ri gate, 180 s cliff dwell
    Deployed 2026-09-16 by OTA (ESPHome 2026.9.0). Byte-identical to the live
    H:\esphome\ups-monitor.yaml (home-assistant-config 059feb2).
    - Paired V/I blocks replace per-channel throttle_average (report Open Item 21)
    - Apparent Ri: 15 s windowed stability gate, every reject logged (Item 20)
    - cliff_imminent delayed_on 60 s -> 180 s (Item 19), ahead of 14a by owner decision
    - Outage duration stops at AC return; Battery Fully Charged current hysteresis
    - New diagnostics: INA260 Unpaired Reads, Battery Current 10 Hz Mean / SD
    Verified before flash: real compile 0 errors, R3 35 hunks all intended,
    host harness on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
2026-09-16 Report 2026-09-15 r3: correct four r2 errors (R13)
    Found by querying the full InfluxDB history rather than the test-window
    exports. Each correction is recorded at its site; superseded text is struck
    through, not removed.
    - Open Item 13 CLOSED, not a defect: Last Onset Step Resistance updated
    97.586 -> 108.744 mOhm at 09:17:48, 38 s after the cut [M]. r2 read it as
    "pre-test" because every instrument it used started after the onset.
    - Open Item 9b CLOSED, not a defect: total_outages incremented 18 -> 19 at
    09:17:49 [M]; this was outage #19, the "#20" tally was wrong.
    - Open Item 18 CLOSED, premise stale: battery_fully_charged fires since V1.17
    (first ON 2026-08-31 19:37:30) and was O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
2026-09-16 Report 2026-09-15 r3: Open Items 19-21 deployed in firmware V1.20
    - Item 21 (publish skew): DEPLOYED, acceptance passed. Median V-I arrival
    gap 1 ms on two V1.20 boots vs 1,318 ms on V1.19 in the same InfluxDB
    query; Battery Power == V x I of the same block in 40/40 points [M].
    S10.3 records the fix; pre-2026-09-16 data keeps every caveat.
    - Item 20 (Apparent Ri gate): DEPLOYED after the re-test S8.1 required.
    Replay over all 4 recorded onsets at 10 tick phases: V1.19 gate rejects
    09-15 and 08-29 16:08; windowed-means gate publishes all four (max
    deviation 3.3 %) and still rejects an injected +/-25 % load change.
    Remaining: that it publishes on 14a's onset (pre-registered).
    - I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
2026-09-21 Top-Off Charger: design rev 0.3 - UPS pack only, from/to wiring
    Moved from Lifepo4-Battery-Banks/Top-Off Charger/ (rev 0.2, 680caed)
    and scoped to the Cyclenbatt, which is removed from the UPS for each
    session:
    - bank profile deferred; L4 (INA228 ALERT), OLED, keyed connector and
    pigtail dropped; polarity at the F2 tabs is set by procedure
    - voltage ceiling trips on raw VBUS; the margin is checked against the
    HDR-30 datasheet's tolerance, temperature coefficient and ripple
    - #2815 -> #2814 MP, and the external ON pull-down withdrawn (the
    switch has its own 20k); an R13 correction record for each
    - normal end is time at voltage; reboot_timeout 0s with an IDLE-only
    recovery reboot
    - W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
2026-09-22 Top-Off Charger: design rev 0.4 - GPIO4 drives the switch directly
    - Rs (1k series resistor in the control wire) withdrawn at the owner's
    request. The V2 board has no series position on GPIO4_BTN (Gerber
    net: XIAO D2, R3-1, J2-1 only).
    - A swapped control pair is now caught by a continuity check before
    first power (J2-1 to GND must not read 0 ohm) and softened by
    drive_strength: 5mA on GPIO4 (FW-1). +V touching the control wire
    stays uncovered: it costs the socketed XIAO, and the charge itself
    is L6's case.
    - The off-at-reset chain is recorded (GPIO4 resets high-impedance with
    no pull; the #2814's R4 + R5 hold ON low), together with why GPIO20
    (the status LED pin, pull-up at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
2026-09-22 Top-Off Charger: design rev 0.5 - P20 does bulk, HDR-30-15 holds only
    - Bulk charge moves to the owner's Dylannet P20 (LiFePO4 mode, 5 A);
    this charger does the top-balance hold only (new section 4.3).
    - RQ-12 and an FW-4 overload stop (I > 2.0 A beyond t_ol) keep the
    HDR-30-15 inside its rating. R13 correction record in 4.1: the
    datasheet classes overload as a fault condition, and rev 0.4 used it
    for the whole bulk phase.
    - DS18B20 dropped: RQ-9/RQ-11 met by siting indoors; INA228 die
    temperature published for the enclosure (FW-10).
    - R_series out of the firmware: raw VBUS and I published, V_batt
    computed downstream; FW-12 records edge resistance each session.
    - FW-3 refuses Sta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
2026-10-04 Top-Off Charger: rev 0.6 board file, design rules and ground-pour solver
    - Top-Off-Charger/pcb/Top Off Charger- Oct 2026.kicad_pcb: the owner's
    board, v7 (saved 2026-10-03 22:42:18, 318,320 B), byte-identical to
    the desktop file. KiCad 10 DRC (--severity-all --refill-zones) with
    the committed .kicad_pro rules: 0 errors, 26 warnings (all silk or
    library), 0 unconnected. Schematic parity did not run (no schematic).
    - .kicad_pro committed for its design rules; .kicad_prl (per-user view
    state) deliberately left out. Gerbers not exported yet (doc O11).
    - gnd_drop.py: finite-difference GND-pour solver behind design doc
    section 7.3. --self-test: uniform strip 1.9481 vs 1.9457 mohm exact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
    [Top Off Charger- Oct 2026.kicad_pcb]
2026-10-04 Top-Off Charger: design rev 0.6 - purpose-built board
    - Section 7 rewritten for the owner's board (pcb/, v7): netlist,
    sockets, U5 soldered on pins (Q5), no pull-up on GPIO4_SW. DRC with
    the board's .kicad_pro: 0 errors, 26 warnings, 0 unconnected;
    schematic parity DID NOT RUN (no schematic).
    - TB1/TB2 replace the lever nuts and most loose wiring (5.1); staged
    first power (5.4); status LED on GPIO3 (D1), 3 mm footprint (Q6),
    with a which-leg-in-which-pad call-out (5.5).
    - 7.3: ground-pour drop, R_shared 0.375-0.407 mohm [D] from
    pcb/gnd_drop.py; T10 is its falsifier.
    - T7 holds SDA to GND instead of unplugging the INA228; O6/O9 revised,
    O11-O14 added (O11 partly done: board and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
2026-10-06 Top-Off Charger: rev 0.7 board, re-laid 29.5 x 78 mm, and design rev 0.7
    - Top-Off-Charger/pcb/: the owner's re-laid board replaces v7 (saved
    2026-10-06 15:16:19, 309,671 B, sha256 be94508f8888b7a4...). Its
    .kicad_pro differs from v7's only in the default width of new pads
    and the last plot path, so the design rules are unchanged. KiCad 10
    DRC (--severity-all --refill-zones): 0 errors, 26 warnings (all silk
    or library), 0 unconnected. Schematic parity did not run (no
    schematic). Gerbers not exported (O11).
    - gnd_drop.py: it took pad 2 of each terminal block as GND; rev 0.7
    moved TB1's GND to pad 1 and it stopped with "expected two
    terminal-block GND pads". It now finds TB2's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
    [Top Off Charger- Oct 2026.kicad_pcb]
2026-10-06 Top-Off Charger: Kelvin GND for the INA228, and design section 7.4
    - Top-Off-Charger/pcb/: the owner's 17:09:17 save of the same board
    (309,654 B, sha256 484347efc18dab89...) adds a Kelvin GND. U2 pin 2
    moves to a new net, GND_SENSE, joined to GND at TB2-2's pad by a net
    tie (reference still REF**, rename to NT1 is O16) and a 0.5 mm F.Cu
    track. The .kicad_pro differs only in the default size and drill of
    new pads. DRC: 0 errors, 26 warnings, 0 unconnected, the same 26
    entries as the 15:16 save. A GND track injected onto the GND_SENSE
    track fires clearance and shorting_items.
    - Design doc, still rev 0.7: the Kelvin GND takes the VBUS offset from
    1.37-1.39 mV to <= 0.20 mV at 3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
    [Top Off Charger- Oct 2026.kicad_pcb]
2026-10-08 Top-Off Charger: rev 0.8 board (VIN+ on B.Cu, wider power path)
    Board files in pcb/ are the owner's 2026-10-08 11:00:58 save
    (sha256 e5586ceb...efaf). All checks ran on the 10:48:22 save
    (9661db54...5b28); the 11:00 save adds only U1 3D models, and its
    DRC set is identical.
    Gate: DRC 0 errors / 34 warnings / 0 unconnected (+11/-3 vs rev 0.7,
    each named in section 7). Schematic parity DID NOT RUN (no schematic).
    No pad's net changed.
    Design doc rev 0.8:
    - 6.4: new widths and IPC figures; charge-path track 37.33 -> 12.17
    mOhm [D, 2-D solve]; F1 branch width is board supply only.
    - 5.1 / 5.5: TB1 moved 4.5 mm down, so its labels can be read with
    U4 seated. The LED is now on the left edge,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
    [Top Off Charger- Oct 2026.kicad_pcb]
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2026-10-08 Top-Off Charger: gnd_drop.py keeps a node for a pad inside another
    Each GND pad and via is a supernode, and a later one takes the cells
    it shares with an earlier one. From the owner's 2026-10-07 19:09 save
    on, TB2-2's enlarged pad covers the net tie's GND pad, which comes
    first in the file. The tie lost every cell, remap gave -1, and its
    per-pad line read V[-1], another node's voltage. That printed a Kelvin
    residual of 0.24-0.26 mohm where the solve gives 0.0000 (O16(b)).
    Now a pad that loses every cell is moved to the end and the numbering
    is redone, so it keeps a node. A pad that still has none (two pads on
    the same copper) raises an error instead of printing a wrong value.
    Two self-test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
2026-10-08 CHANGELOG: entries for rev 0.8, the LF hashes and the gnd_drop fix
    R13: e27eeab (rev 0.8 board and design doc), 1ef6daa (LF hashes) and
    2389987 (gnd_drop.py tie-pad fix) went in on 2026-10-08 without
    CHANGELOG entries, though every earlier Top-Off Charger commit had one.
    This adds a 2026-10-08 section for them, written from the commits
    themselves. No other file changes.
2026-10-08 Top-Off Charger: gnd_drop.py moves to the Tools repo
    The board review tools now live once, in Tools pcb-eval/, for every
    board. gnd_drop.py went there unchanged (Tools 6fe2087, byte-identical
    to 2389987, md5 5fb3d565...). Tools e273314 then made the board file a
    required argument, because its default was the board beside the script,
    which stays here.
    Design doc: section 7.3's Method now links the Tools file at e273314 and
    gives the run.py command; section 7.4 step 4 points to it. CHANGELOG:
    a Removed entry. The link resolves once Tools is pushed.
2026-10-08 Top-Off Charger: pcb-eval profile beside the board
    Since Tools 9273225 the pcb-eval tools carry no board's pads. Each board's
    pads are a <board stem>.pcb-eval.json beside it, and a board without one
    is refused. This adds the Top Off Charger's: the five paths, the charge-path
    sum and the gnd source/sink/shared pads, as tracknet.py and gnd_drop.py held
    them until 2026-10-08.
    Checked on this board with no --profile (it is byte-identical to Tools'
    fixture toc_1100 after CR strip). netdrop, gnd_drop and dump print the
    fixture's output except the profile line. tracknet between the two boards
    gives +0.00 on every solved net, and nan on Batt_SW, VIN+ and VIN-, the same
    as the recorded fixture outpu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
2026-10-16 Top-off charger rev 0.9: six-mode LED spec, FW-13, firmware V0.1 draft
    Design doc rev 0.9 (firmware spec only; board unchanged from rev 0.8):
    - FW-11: six LED modes (Waiting, Ready to charge, Charging, Final
    minute, Done, Fault), precedence order, on/off only, 60 s lead.
    - FW-13: current with the switch commanded OFF latches FAULT, so a
    failed-short #2814 is announced; T15 added.
    - FW-4: a failed read latches FAULT in every state; overload time is
    cumulative; T7 revised.
    - R13 correction record: ESPHome 2026.9.1 publishes 0, not NaN, on a
    failed INA228 read and spreads the read over ~8 loop passes.
    - O17 added: section 1's "one sample period" vs the 500 ms tick.
    Firmware V0.1 (Top-O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
2026-10-16 Top-off charger: start T11 at T_hold 6 h, T_max 8 h
    The 1 h / 2 h placeholders were too short for an unbalanced pack. A
    passive balancer moves charge only at its bleed rate: 1 h at 50 mA is
    0.05 Ah, 0.5 % of 10 Ah. 6 h shows whether a floor exists and does real
    balancing if it does. FW-6 records the sizing rule for later sessions
    (imbalance / floor); section 13 notes that the L6 timer must reach
    past 8 h.
    Claude-Session: https://claude.ai/code/session_013kHKR965cqzicNTMmV9f1M
2026-10-16 Top-off charger rev 0.10: FW-14 tail-floor observation, host bleed (O8)
    FW-14 (owner's proposal, refined), report-only; no decision reads it:
    - window means after a settle in time at voltage (tail_settle_s,
    placeholder 30 min; tail_window_s 10 min)
    - tail floor = lowest window mean, not lowest sample (a sample minimum
    is biased low by noise); no non-zero test (0 = failed read, already
    invalid)
    - charge after settle (CHARGE register end minus settle): upper bound on
    what the balancer moved
    - idle offset: EWMA of IDLE current with the switch settled OFF,
    snapshotted at Start, subtracted downstream
    - all four in the restored session record. The "balancer activity" flag
    is deferred u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
2026-10-16 docs: rewrite README for the boosted N100DC system
    Rewrite README.md for the system as it now runs: the N100DC host on
    the 18 V U3V70A boost (since 2026-08-29), the UPS-Monitor-THT Rev 1
    PCB with firmware V1.20, test history through the 2026-09-15 full
    discharge, the unattended-recovery gap, and the planned top-off
    charger (rev 0.10, untested design requirements).
    Retires the May 2026 runtime/capacity claims, "No DC-DC converter",
    the recharge-taper and lifespan figures, and the old graceful-shutdown
    trigger. Fixes the report links that pointed into docs/ instead of
    reports/. CHANGELOG gets a 2026-10-16 entry and a current Pending list.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
2026-10-16 docs: date the original design set and link its orphaned charts
    Each of the 13 docs/*.md files now opens with a currency note. It says
    the document describes the March 2026 HA Green build, gives what has
    changed since (the INA260 monitor, the N100DC host on the 18 V boost,
    today's load and the 2026-09-15 capacity result), and names what in
    that document no longer holds. The document bodies are unchanged.
    The two March commissioning charts in docs/ (UPS_Final_Report.pdf,
    ups_full_discharge_cycle_r6400.html) were linked from nowhere; the
    README now lists them with the original design set.
2026-10-16 docs: correct the BMS over-voltage figure (top-off O7)
    Eight places in five docs/ files gave 14.4-14.6 V as the Cyclenbatt
    BMS over-voltage cutoff: component-selection (2), design-rationale,
    safety, specifications, supplemental-analysis (3). The pack label
    gives that range as the charge voltage (owner, 2026-09-21), and
    nothing in the repo gives the cutoff. A dated correction now follows
    each place, and the original text is unchanged. The margin figures
    that rested on it (1.3 V, 1.1 V) are restated as margins to the
    charge range.
    The top-off design's Open Item O7 is closed; that design does not
    rely on the figure.
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2026-10-16 docs: bring CITATION.cff up to the system as it runs
    The title now matches the README, and version and date-released are
    2026-10-16. The keyword shelly is replaced by esphome, INA260, coulomb
    counting and boost converter. The abstract described the HA Green build,
    an 8+ hour runtime and Shelly monitoring; it now describes the N100DC
    host on the 18 V boost, the INA260 monitor and the dated test reports,
    and quotes no performance figures.
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2026-10-22 Top-off charger rev 0.11, firmware V0.4: lost session, INA228 reset, reset reason
    Robustness review items #1, #2 and #6 (owner). #4, web_server
    authentication, is not built.
    - #1 lost session: a restored "session open" flag is set and flushed at
    Start and cleared when the record is written. Still set at boot means a
    reset cut the session: FAULT "reset during a session", with Ah and times
    recorded as NaN. Blind spot: a reset in the ~1.5 s before the flush.
    - #2 INA228 reset: ADC_CONFIG and SHUNT_CAL are read back every fresh
    cycle against the chip's own first read (not a copy of the firmware
    settings, R10), and CHARGE must not fall below half its session peak.
    Either latches FAUL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

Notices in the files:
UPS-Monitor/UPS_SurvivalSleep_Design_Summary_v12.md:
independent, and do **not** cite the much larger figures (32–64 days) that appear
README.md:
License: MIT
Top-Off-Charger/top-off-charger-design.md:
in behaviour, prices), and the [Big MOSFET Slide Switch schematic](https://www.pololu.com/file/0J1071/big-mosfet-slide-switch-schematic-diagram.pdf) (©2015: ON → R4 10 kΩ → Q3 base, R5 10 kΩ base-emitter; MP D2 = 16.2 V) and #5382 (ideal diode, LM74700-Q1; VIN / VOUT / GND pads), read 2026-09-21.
